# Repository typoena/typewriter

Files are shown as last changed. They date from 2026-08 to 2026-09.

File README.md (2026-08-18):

# Typoena

<p align="center">
  Typo, o tucano
</p>

A distraction-free, hackable, DIY writing machine. ESP32-S3 + e-ink + a real
mechanical keyboard. You write Markdown, you commit, you push. Nothing else
runs on it.

> **Status: firmware 0.8.0, hardware on the bench.** The device boots, edits,
> and syncs: vim navigation and editing, a file palette over multiple buffers,
> Markdown affordances, `/` search, `:gs` push / `:gl` pull, focus mode,
> `:update` OTA, a command palette and font picker, and a zero-computer
> first-boot wizard. v0.9 (robustness) is the open release — per-item status in
> the Macroplan, release contents in the [CHANGELOG](CHANGELOG.md).

Design & context:

- [Macroplan](docs/plan/macroplan.md) — the week-by-week delivery plan, live
  per-item status, and per-version scope
- [QFD](docs/quality/qfd.md) — how every decision is weighted against the
  user-facing requirements (Goal → Function → How → Component)
- [ADRs](docs/adr.md) — the decision log, rejected alternatives included
- [Doc index](docs/README.md) — everything else: per-version specs, notes,
  tradeoff curves
- [Bill of materials](hardware/bom.md) — build it yourself, full part list
- [Wiring](hardware/wiring.md) — every electrical connection, pin by pin
- [Postmortems](docs/record/postmortems/README.md) — failure write-ups
- [Kaizen](docs/record/kaizen/README.md) — improvement loops

Technical pages, one per subsystem:

- [Firmware](firmware/README.md) — build, flash, provisioning, editor setup,
  bring-up spike log
- [Enclosure](hardware/case/README.md) — parametric, 3D-printable
  typewriter-body case (OpenSCAD)
- [Installer](installer/DESIGN.md) — macOS setup tool: flash + provision
  without a dev environment

---

## Vision

A single-purpose appliance that boots into a text editor with a Vim keymap,
edits Markdown files, and (optionally) pushes them to a git remote (GitHub
first) over Wi-Fi. No browser, no notifications, no apps. Open lid → write →
push (or don't) → close lid.

Two file scopes coexist on the SD card — formal definitions in
[`CONTEXT.md`](CONTEXT.md):

- **Tracked** — lives in the git working copy, gets **Pushed** when the
  user runs `:gs`.
- **Local** — never leaves the device. Permanently-private: journal entries,
  scratch, things that aren't anyone else's business. There is no "promote
  to Tracked" gesture — scope is fixed at file creation.

Same editor, same keymap; the difference is just whether `:gs` (push to
the remote) is offered.

---

## Hardware

**ESP32-S3-N16R8** (16 MB flash, 8 MB PSRAM) · **GDEY0579T93** 5.79″ e-ink
strip (792×272, ~2.9:1 — biases the UX toward "current line + recent context",
the writing posture we want) · **Nuphy wired USB keyboard** with the S3 as USB
host · **microSD over SPI** · **USB-C wall power or a 3700 mAh LiPo**, switched
by a latching panel button through a load-sharing power path.

---

## Software stack

**Rust on `esp-idf-rs` (std)**, a custom modal editor and thin widget layer on
`embedded-graphics`, a custom dual-SSD1683 e-ink driver, libgit2 (via `git2`)
for `:gs`/`:gl` sync over mbedTLS. The layer-by-layer table — each choice with
its ADR, measured costs, and the annotated repo layout — is in
[`docs/reference/stack.md`](docs/reference/stack.md).

---

## UX boundaries set by the medium

E-ink is a brutal honesty filter on UI choices. Hard constraints we design
around, not against:

- **No cursor blink.** Kills the panel and the battery.
- **Typing latency target: ≤ 200 ms** from keypress to glyph on screen, using
  partial refresh on the affected line only.
- **Full refresh every ~20 partials** to clear ghosting. User-visible flash —
  schedule it on pauses (>1 s of no input).
- **No smooth scrolling.** Page-style jumps only.
- **No animations.** Anywhere.
- **Render only changed lines**, not the viewport.

---

## Open questions / risks (tracked, not yet resolved)

- [ ] Heap fragmentation over a long writing session with the PSRAM allocator.
- [ ] Real-world e-ink ghosting with the current partial-refresh cadence.
- [~] Use-after-free freeing the in-flight USB transfer on keyboard unplug —
  fixed in code, pending an on-device hot-plug run to confirm.

Retired risks ([gix push](docs/record/postmortems/2026-07-05-spike7-gix-https-push.md),
[SD CMD59 rejection](docs/record/postmortems/2026-07-05-spike3-sd-cmd59.md), TinyUSB HID
stability, TLS heap, libgit2-on-xtensa) and how they died:
[`docs/record/postmortems/`](docs/record/postmortems/README.md) and the
[bring-up spike log](firmware/docs/bring-up-spikes.md).

These get resolved by writing code, not by deciding harder.

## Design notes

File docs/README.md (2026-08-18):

# Docs

> The design record for Typoena. Four trees, split by what you are doing:
> **reference** is what is true right now, **plan** is what is coming,
> **quality** is how requirements are weighed, and **record** is dated and
> append-only.
>
> Start with the [ADRs](adr.md) for the load-bearing choices, or
> [commands](reference/commands.md) for what the device actually answers to.
> Project overview: [`../README.md`](../README.md).

## Decisions

| Doc | What's in it |
| --- | --- |
| [`adr.md`](adr.md) | Architecture Decision Records — the load-bearing technical choices, rejected alternatives included. |
| [`INDEX.toml`](INDEX.toml) | Retrieval index: what each doc concludes, and which subsystem it concludes it about. One read, no folder browsing — for agents and for finding the file that holds a number. |

## Reference — true now, no dates

| Doc | What's in it |
| --- | --- |
| [`reference/commands.md`](reference/commands.md) | Every `:` command and `>` palette action, and what each one refuses to do. |
| [`reference/stack.md`](reference/stack.md) | Software stack layer by layer, with measured costs and the annotated repo layout. |
| [`reference/typoena-toml.md`](reference/typoena-toml.md) | `.typoena.toml` — the git-tracked editor preferences. |
| [`reference/typoena-snippets.md`](reference/typoena-snippets.md) | `.typoena.snippets.json` — the git-tracked, Zed-compatible snippet library. |
| [`reference/testing.md`](reference/testing.md) | Where Rust tests live and how to run them. |
| [`reference/ssd1683-commands.md`](reference/ssd1683-commands.md) | What every command and data byte the e-paper driver writes means. |
| [`reference/hid-keycodes.md`](reference/hid-keycodes.md) | Boot-report layout, modifier bits, and the usage IDs behind the chord table. |
| [`reference/font-atlas.md`](reference/font-atlas.md) | Atlas geometry, glyph slot order, and the framebuffer's ink polarity. |
| [`reference/libgit2-esp-port.md`](reference/libgit2-esp-port.md) | The POSIX shims libgit2 links against on esp-idf. |
| [`../hardware/bom.md`](../hardware/bom.md) | Bill of materials — every physical part by subsystem. |
| [`../hardware/wiring.md`](../hardware/wiring.md) | Every electrical connection, one table per subsystem. |

## Plan — what is coming

| Doc | What's in it |
| --- | --- |
| [`plan/macroplan.md`](plan/macroplan.md) | The delivery plan: macroplan source and the open checklists for v0.9, v0.10, v1.0 and v1.x. |
| [`plan/v0.9-onboarding-wizard.md`](plan/v0.9-onboarding-wizard.md) | First-boot setup and `:setup` — the zero-computer provisioning flow. |
| [`plan/v0.10-battery-and-sleep.md`](plan/v0.10-battery-and-sleep.md) | Power switch, power path, battery, sleep. Design decided, not built. |

Delivered releases are listed in full in [`../CHANGELOG.md`](../CHANGELOG.md).
Their behaviour lives in the reference pages above, not in per-release specs.

## Quality — how requirements are weighed

| Doc | What's in it |
| --- | --- |
| [`quality/qfd.md`](quality/qfd.md) | QFD hub — what-matters-now headlines, §6 the critical performance budget, §7 the tradeoffs and unresolved tensions. Start here. |
| [`quality/glossary.md`](quality/glossary.md) | Methodology vocabulary: the WHAT / Function / Characteristic / Metric / Target ontology. |
| [`quality/qfd-house-1.md`](quality/qfd-house-1.md) | House 1 (WHATs × HOWs) — §1 requirements, §2 characteristics, §3 reading, §4 roof. |
| [`quality/qfd-house-2.md`](quality/qfd-house-2.md) | House 2 (HOWs × components) — §5 cascade tree, component ranking, shared-pool budget. |
| [`quality/qfd-houses-3-4.md`](quality/qfd-houses-3-4.md) | Houses 3 & 4 under the pipeline reading — processes P1–P9 × controls Q1–Q8. |
| [`quality/qfd-perception.md`](quality/qfd-perception.md) | Competitive perception — five products scored 0–5 per WHAT. |
| [`quality/house-vs-product.md`](quality/house-vs-product.md) | Standing challenges: where the scored houses and the real product disagree. |

Device vocabulary (Save, Push, Tracked, Local) is in
[`../CONTEXT.md`](../CONTEXT.md), not here.

## Record — dated, append-only, never pruned

| Area | What's in it |
| --- | --- |
| [`record/postmortems/`](record/postmortems/README.md) | What broke, the root cause, and the decision that came out of it. |
| [`record/kaizen/`](record/kaizen/README.md) | Six-step improvement loops: a recurring cost measured, attacked, re-measured. |
| [`record/tradeoff-curves/`](record/tradeoff-curves/README.md) | Cost-vs-knob curves behind chosen defaults — energy, latency, memory. |
| [`record/notes/`](record/notes/README.md) | Longer-form essays: the arguments too big for an ADR, too durable for a commit message. |
| [`../firmware/docs/bring-up-spikes.md`](../firmware/docs/bring-up-spikes.md) | The chronological bench log of Spikes 1–7 that brought the firmware up on silicon. |

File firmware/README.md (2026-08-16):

# Typoena firmware

Rust crate targeting `xtensa-esp32s3-espidf` — the on-device firmware: a
vim-style modal editor with git push/pull, OTA updates, and a first-boot
wizard.

One crate of the [Typoena project](../README.md) — start there for the
vision, the hardware, and the design record (macroplan, QFD, ADRs, doc
index). The layer-by-layer stack and the annotated repo layout:
[`docs/reference/stack.md`](../docs/reference/stack.md).

Technical pages:

- [Build details](docs/build-details.md) — esp-idf components, libgit2 and
  the `full` feature
- [Editor setup](docs/editor-setup.md) — Zed / rust-analyzer, `esp` toolchain
  version requirement, launch environment
- [Provisioning an SD card](docs/sd-provisioning.md) — `just init` / `load` /
  `provision`, the config ladder, secrets on the card
- [Bench board & pinout](../hardware/wiring.md#the-bench-board) — DevKitC-1 v1.0, pin assignments
- [Bring-up spike log](docs/bring-up-spikes.md) — Spikes 1–6 as verified on
  the bench
- [Bench QC firmware](docs/bench-qc.md) — go/no-go fixture for the
  hand-soldered carrier PCB

## Quick commands

A [`justfile`](https://github.com/casey/just) wraps the common commands and
sources the espup env itself — run `just` in this directory for the list
(`build`, `flash`, `monitor`, `info`, `ports`).

## Build

Once per shell session, source the espup env (sets `LIBCLANG_PATH` and adds
the Xtensa GCC to `PATH`):

```sh
. ~/export-esp.sh
```

Then from this directory:

```sh
just build   # the product firmware: editor + git pushing + OTA + wizard
```

The first build is slow (esp-idf + libgit2 + mbedTLS); after that it's
incremental — see [build details](docs/build-details.md). The fast iteration
loop is host-side: `cargo test -p app -p editor`.

The panel's fast/partial waveform comes from Good Display's vendor reference
driver, kept verbatim in
[`reference/gdey0579t93-fp-lut/`](reference/gdey0579t93-fp-lut/README.md) — it is
the source of truth for the custom `0x32` LUT, which cannot be derived from the
panel's OTP.

## Flash

With the board connected over USB, `just flash` (or `cargo run --release`)
triggers `espflash flash --monitor` via the runner configured in
[`.cargo/config.toml`](.cargo/config.toml).

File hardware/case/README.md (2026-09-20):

# Enclosure — Typoena body

A 3D-printable case for [**Typoena**](../../README.md), the distraction-free DIY
writing machine. The e-paper strip sits on a reclined **deck**, where a
typewriter's paper would be; you bring your own keyboard for the front. There is
no platen part (it complicates the print); the rounded back-top edge nods to one.

> **Status: outer form and screen clamp proven on a print; the cavity
> follows the fabricated mainboard and has not been printed against it.** The
> wedge, the deck and the glass retention are worked out against the real
> hardware and every number there is measured — the **3700 mAh** cell included.
> The board block — mounting, ports, button — is cut straight from
> [`typoena-devboard.kicad_pcb`](../pcb/devboard/typoena-devboard.kicad_pcb), so
> its dimensions are exact and its *fits* are untried: **print the I/O coupon
> first**. Process error is corrected **in the slicer** and not in the model, and
> the correction is qualified per filament, so
> **[MANUFACTURING.md](MANUFACTURING.md)** is required reading before any print.
> The 12 heat-set inserts are untried — see **Open questions**.

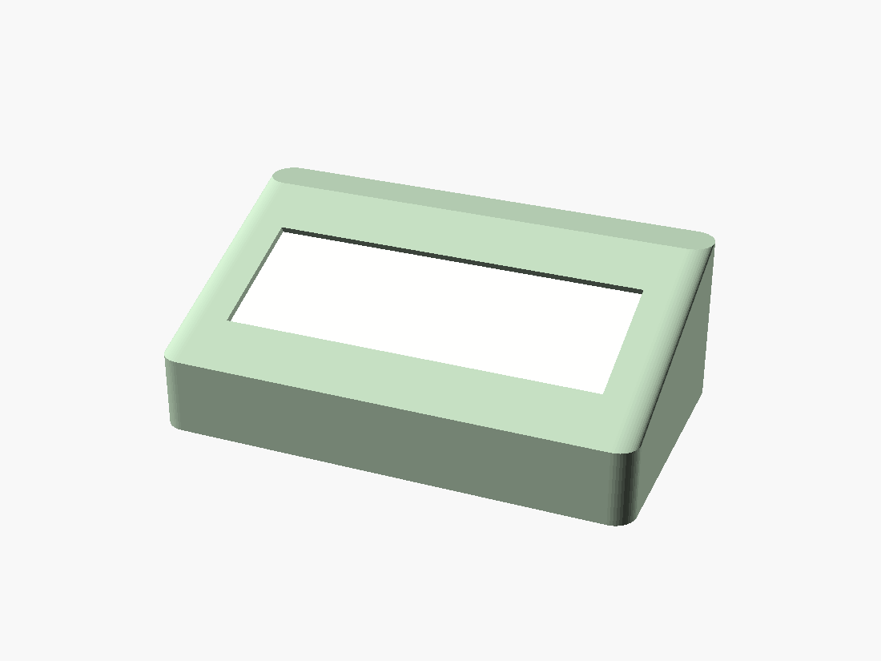
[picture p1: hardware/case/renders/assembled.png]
The deck: bezel lip framing the e-paper aperture

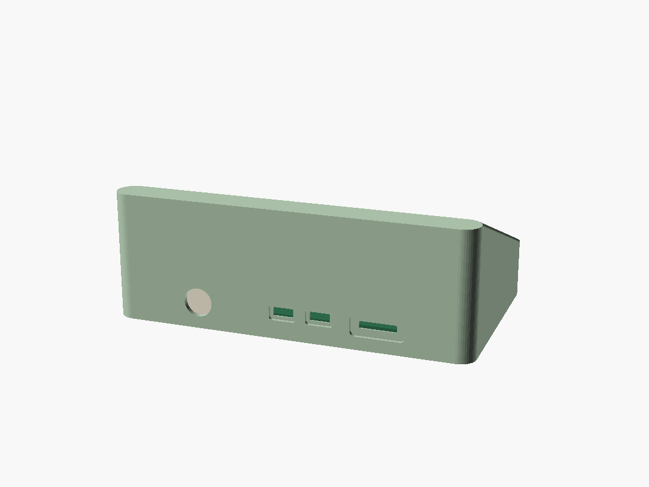
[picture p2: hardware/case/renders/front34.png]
Assembled body, three-quarter — reclined deck, back wall with port cutouts


## Files

| File | What |
| --- | --- |
| [`typoena-case.scad`](typoena-case.scad) | The parametric model, **nominal geometry**. All dimensions live at the top. |
| [`MANUFACTURING.md`](MANUFACTURING.md) | **Slicer settings — read before printing.** Process error is corrected here, not in the model, and the value is qualified per filament. |
| [`typoena-case-kb.scad`](typoena-case-kb.scad) | Integrated-keyboard variant (60%/40%) — see [README-kb.md](README-kb.md). |
| [`concept.html`](concept.html) | The **v0 concept sheet** as drawn, before the model existed. Its platen roller and knobs never shipped; the model wins on every dimension. |
| `renders/` | PNG previews (regenerated by `just render`). |
| `*.stl` | Mesh exports — generated on demand by `just stl`, not tracked. |

## Render

Needs [OpenSCAD](https://openscad.org). From `hardware/`:

```sh
just render   # regenerate every case/renders/*.png
just stl      # export every STL: body / bracket / baseplate / coupon / jig / assembly
just stl-io   # re-export just the back-wall I/O fit coupon (quick test print)
just stl-guide # re-export just the baseplate drill jig block (print it 4x)
just stl-feet # export the stick-on feet (deferred — see feet_mode)
just open     # open the model in OpenSCAD
```

The meshes aren't tracked — they're 5 MB of ASCII that git rewrites line by line
on any geometry change. For a shareable set, tag instead: `git tag case-vX.Y.Z &&
git push origin case-vX.Y.Z` has CI export from the tagged commit and publish
`stl.zip`, `stl-kb.zip` and the I/O coupon to
[Releases](https://github.com/typoena/typewriter/releases).

`show` accepts `assembled` · `body` · `bracket` · `baseplate` · `feet` ·
`print_plate` · `section` (vertical cut) · `plan` (exploded horizontal) ·
`plan_up` / `plan_down` (each half alone) · `io_coupon` (the I/O fit test print) ·
`drill_guide` (one baseplate drill jig block, print four) / `drill_guide_fit`
(the four of them seated on the plate).

## Dimensions

Baked into the model from the datasheets:

- **Panel (GDEY0579T93):** glass 150.92 × 56.94 × 1.0 mm, active area
  139.00 × 47.74 mm, pitch 0.1755 mm.
- **Mainboard** (99 W × 45 D × 1.6 mm, corners R3): the whole machine on one
  PCBA — BQ25896 power path, the panel's power stage, µSD, both USB-C. **Ø3.7
  hole 5 mm in from each corner**, which is a #6-32 clearance. It lies **along
  the back wall**, ports out.

  **Read its X off the canvas and you get it backwards.** KiCad's Y points down,
  so the port edge is drawn at the *bottom*; laying the board in with its ports at
  the **back** turns it 180° in plan. Every board-local X in the model is
  therefore `u = 116 − kicad_x`, from the board's **left edge as installed** — so
  `J4` (KiCad x 110) ends up 2…7 mm from the **left** edge, and the devkit
  (KiCad x 15…78) fills the **right** half.
- **ESP32-S3-DevKitC-1**, plugged into the mainboard's two 1×22 rows over its
  right half (`u` 38…101): **13.5 mm of stack** over the board face (socket 8.5 +
  board 1.6 + can 3.4) and the tallest thing in the cavity. Its antenna end
  overhangs the board's **right** edge by 2.3 mm, which is the widest the
  assembly ever gets.
- **Battery:** LiPo 3700 mAh, 94 × 32 × 10.3 mm, flat in the front-right.
- **Body:** 176 W × 104 D, 28 mm front → 68 mm back, deck reclined ~21°. Walls
  2.4 mm, deck 3.4 mm, corner radius 8 mm.

## How the hardware goes in (glueless)

No glue on the fragile 1 mm glass; every part stays serviceable.

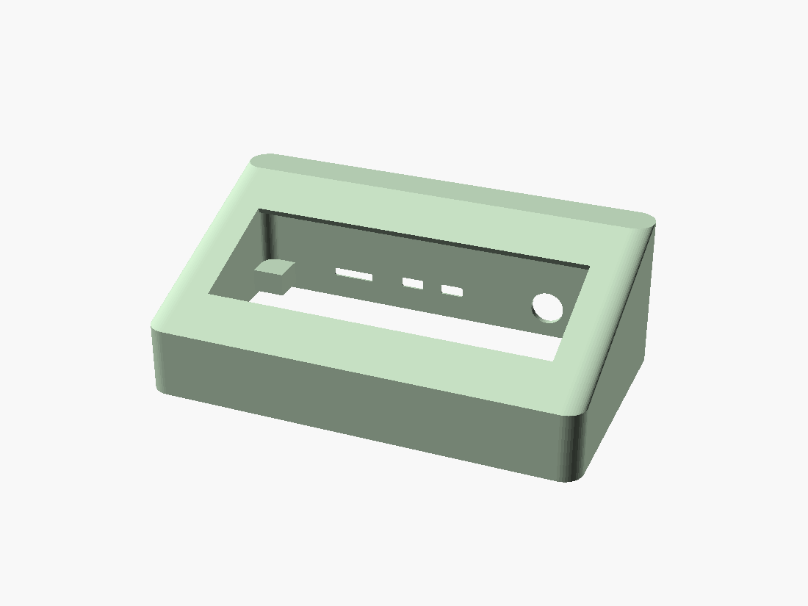
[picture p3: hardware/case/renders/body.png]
Bare body shell — screen recess through the deck, FPC slot on the left edge


**Screen.** The glass drops into the deck recess from behind (the walls locate it
in X/Y). The deck is that recess plus the lip in front of it — `top_wall` is
`lip_t + G_t`, so the pocket wall is **exactly one glass deep**: it takes the glass
over its full 1 mm and stops on its back face, where the foam frame (wider than the
pocket) comes up to meet it. Front to back the stack is: deck **bezel lip** (covers
the inactive border only, `lip_t = 2.4 mm`) → **glass** → non-adhesive closed-cell **foam**
gasket (`foam_t = 5 mm` free, squashed to `foam_c = 3.5` — a 30% squash) → printed
**bracket**
screwed to 4 bosses. The lip stops the glass falling out the front; the bracket
stops it dropping into the cavity. The FPC folds back through an internal
clearance on the **left** (kept under the bezel, so invisible outside) and down
into the cavity on its way to the board. For a screwless build, cantilever clips work but point-load the glass
edge; I'd default to foam + bracket.

The bosses' **free ends are the bracket's seating face** (`br_seat = 6.9 mm` below
the deck's outer face). The screw pulls the bracket onto that shoulder and stops,
so the foam squash — and therefore the clamp on a brittle panel — is set by
geometry rather than by how hard you turn the screwdriver. That is also why the
foam is 5 mm and not 1: the seat has to sit far enough behind the glass to leave
the boss room for a **heat-set insert** (see *Fasteners* below). The bore stops
`pilot_skin = 2.1 mm` short of the deck's outer face, so nothing shows on the side
the user looks at — and that skin, not the thread, is what set `lip_t`.

Locating tolerances: the pocket is the glass's *only* registration — nothing behind
it is narrower than the cavity — and it gives the glass **0.25 mm of play per side**
in X and Y, against a window margin of 1.00 mm (X) / 0.50 mm (Y) over the active area —
so a drifted panel shifts the bezel by a quarter of a millimetre and can never clip
a pixel. Don't try to make the bracket locate anything either way: the pocket
locates, the bracket only clamps. Its clearance holes are **Ø3.9 on a Ø3.5 shank** —
drive the screws through the bracket rather than expecting it to drop over them.

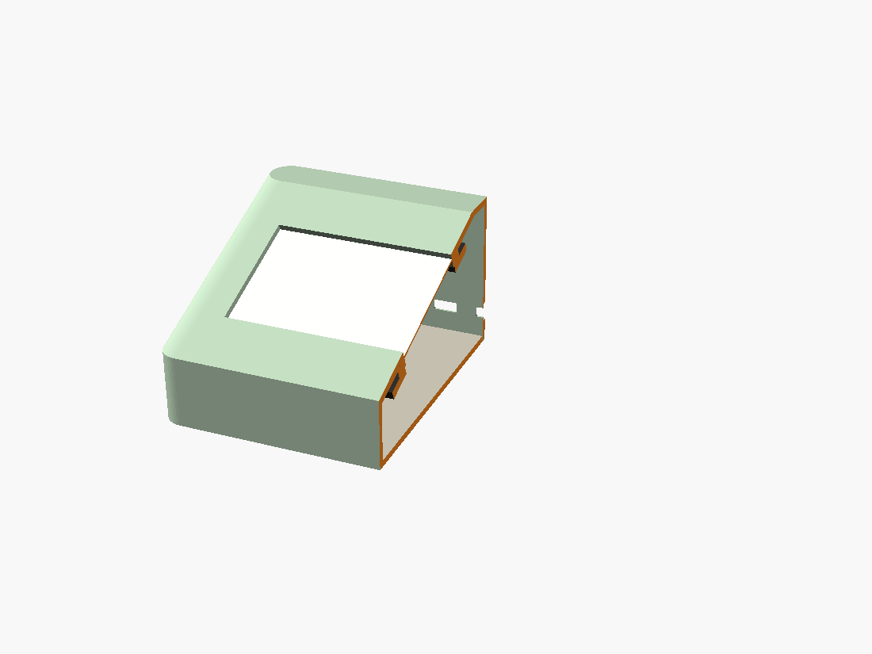
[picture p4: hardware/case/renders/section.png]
Midline section: glass clamped between front lip and rear foam + bracket

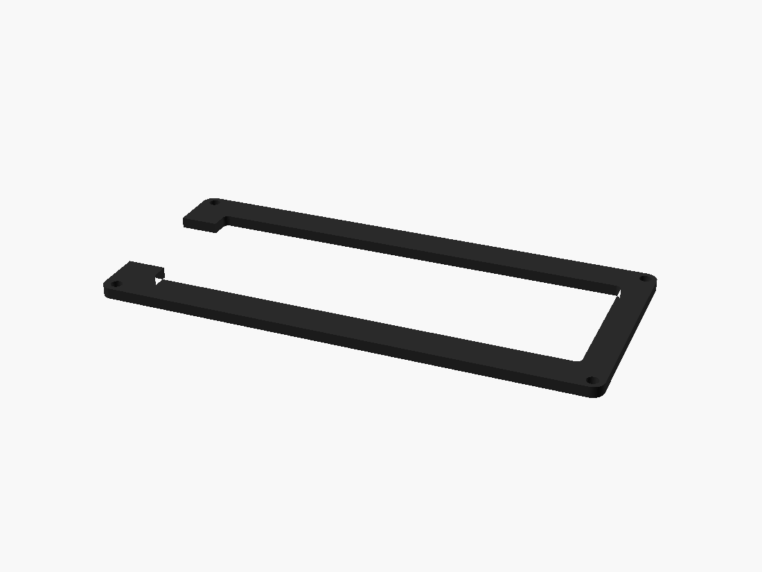
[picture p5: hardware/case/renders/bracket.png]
The bracket — four corner holes, window clears the active area, left edge relieved for the FPC


**Fasteners.** Every screwed joint in the machine uses one family: a
**ruthex RX-6-32×3.8** brass heat-set insert (Ø4.7 body, 3.8 long, datasheet bore
**Ø4.8 × 4.8 min**, **1.8 mm minimum wall**) taking a **#6-32** pan screw — 7 mm
of thread under a flat 1 mm × Ø6.5 head. Both parts are measured, not
catalogue numbers. All three joints get *opened*: the baseplate on every service,
the bracket on every glass swap, the board whenever it comes out — and a
self-tapped thread in PLA is good for a handful of cycles before it's a stripped
hole in a 10-hour print.

| | bracket → deck (×4) | baseplate → body (×4) | board → standoff (×4) |
| --- | --- | --- | --- |
| insert lives in | the body, under the deck | the body, from below | the **baseplate**, from above |
| boss | Ø8.9, **2.05 mm** of wall | rectangular pad, **2.6 mm** to the free faces | Ø8.9 standoff, **2.05 mm** of wall |
| bore | Ø4.8 × 4.8 blind, **2.1 mm of deck** left over it | Ø4.8 × 6.6 blind, 3.4 mm of roof | Ø4.8 × 6.4 blind, bottoming on the plate — **3.2 mm** under it |
| screw crosses | 3.6 mm of bracket | 1.4 mm of plate | 1.6 mm of PCB |
| thread in brass | **3.4 mm** | **3.8 mm** (the whole insert) | **3.8 mm** (the whole insert) |
| head | **no lamage** — bears on the bracket's face, inside the case | in a **lamage** in the plate's underside, flush with the desk — **drilled, not printed** (see [Drilling the baseplate](#drilling-the-baseplate)) | **no lamage** — bears on the PCB, Ø6.5 on a Ø3.7 hole |

Every bore is a **plain Ø4.8 cylinder** — no relief, no step, no lead-in for the
insert's head end: the iron melts its own seat, so the bore is not a clearance fit
and nothing about the insert's outline is modelled. There is no counterbore left
anywhere in the model: the baseplate's four screw passages come out of the printer
**solid** and are drilled afterwards.

That Ø4.8 is what Ruthex asks for around a Ø4.7 body: the insert melts its own
seat, so this is a grip, not a clearance fit. No insert has been set yet — judge
the first one on a part sliced with the XY compensation, since an uncompensated
bore lands ~0.16 mm under and the brass would be pressed into a hole that tight.

Every bore is deliberately **deeper than the insert** (they have to swallow the
screw tip), and with the relief gone **nothing in the part stops the press**. Sink
each insert flush with the boss's free end by eye or with a depth stop on the iron:
that face is a seating face on all three joints — proud brass spends the foam
preload on the bracket, rocks the plate on the baseplate, and tilts the board on
its standoffs.

**Twelve inserts, one screw.** The board is in the family too: its four holes are
a #6-32 clearance, so it screws *down* into an insert in each standoff and the
same **#6-32 × 7** drives every joint in the machine. That is what took the
drill off the baseplate's standoffs — the bore they need is Ø4.8, which a printer
holds, where the Ø1.6 pilot of a self-tapper is two or three perimeters wide and
comes out whatever size the extrusion width allows.

The depth budget is why `lip_t` went 1.4 → 2.4 and `bracket_t` 2.6 → 3.6. Between
the bracket's seat and the deck's *outer face* there is only `br_seat`, and the
bore eats it from below: 6.9 = bore 4.8 + skin 2.1. At the old numbers the bore came
to 5.4 against a `br_seat` of 5.9 — **0.5 mm** of skin on the machine's showpiece
face, with the screw tip arriving under it and the iron melting brass into it.
There is nowhere else to buy that skin, so it came half from the visible lip (a
deeper bezel well) and half from the invisible bracket, and the
glass ends up 1 mm deeper in a stiffer clamp. `typoena-case.scad` **asserts** the
walls, the skin, the roof and the thread engagement — a plausible-looking edit to
any of those four numbers fails the render instead of the print.

**Board.** Mount everything to the **baseplate** on the bench, then close from
below.

The mainboard sits on **four Ø8.9 printed standoffs**, `standoff_h` = **7 mm**
tall, one under each corner hole, and is pulled down onto them by four #6-32 into
their heat-set inserts. The standoff height is set by the insert rather than by
the gap: the bore is 6.4 mm deep from the standoff's free end and bottoms on the
plate, which leaves 3.2 mm of material under it.

That 7 mm gap is the **wiring bay**. The panel's flex crosses it west to east,
and the battery, button and lamp pigtails share it.

- The board lands **back-left**: `x` 18…117, `y` 55.8…100.8, i.e. hard against
  the back wall and as far left as the back-left baseplate boss allows.

  **Y is set by the ports.** The two USB-C shells stand **1.3 mm past the board's
  back edge** and have to end up *inside* the wall opening rather than behind the
  wall, so the board is pushed back until only **0.8 mm** is left between its edge
  and the wall's inner face. That puts the receptacle mouths 0.5 mm into the
  wall's thickness, 0.3 mm behind the floor of the cable-boot pocket — as close
  to full plug engagement as a 2.4 mm wall gets.

  **X is set by the flex.** The panel's ribbon leaves the glass on the **left**
  and drops through the deck slot at `x` 3.8…13.8; `J4`, the 24-pin FFC that takes
  it, is at the board's **left** end — body at `x` 20.1…24.5, ribbon entering its
  mouth at 25.3 heading **west**. The two want to be as close as they can get, and
  what stops the board at `x` = 18 is the back-left baseplate boss, whose free
  face is at 16; the model asserts the 2 mm between them.

  The run: down through the slot into the **front-left plenum**, east across the
  plenum floor, up over the board's front edge (its left quadrant is clear — the
  JST row starts at `u` 36) and back west into `J4` at (25, 75). Because the
  connector opens east, the flex has to overshoot and fold back on itself — a
  plain 180° reverse bend in the vertical plane, no mitres. Call it **~90 mm**
  of flex with the bends, against a panel ribbon of 20.

  The **DevKitC-1** lies over the board's right half, 8.5 mm up on its headers,
  with its antenna end overhanging the board edge. Nothing is put beside that end,
  and its own USB-C — the machine's programming port — points into the cavity:
  taking the baseplate off brings the whole board assembly out with it, which is
  how you reach it.

  Height is slack here, because the stack stands at the tall end of the wedge: it
  tops out at **24.7 mm** off the plate's underside against a ceiling of **43.9**
  over the board's front edge, so it clears by 19 mm. The model asserts 2.5.
- **Ports**, from the left: µSD at `x` 44.2, keyboard USB-C at 72.0, charge
  USB-C at 89.9 — the board's own spacing, carried over from the PCB file, so the
  cluster follows the board and nothing else can move it. Centres sit at
  `z` 11.91 (µSD card) and 12.83 (USB-C).

  The **µSD needs its pocket to be usable.** The socket is a push-pull Molex
  1040310811 whose mouth sits 1.92 mm *behind* the board's edge, and a card
  protrudes only 4 mm from that mouth — less than the wall is thick. However the
  board is placed, the card stops short of the outer face. So the µSD gets a
  **26 × 11 finger pocket** in the outer face, 1.6 mm deep like the USB-C boots,
  and an **18 × 3.5 opening** through its floor: the card ends level with the
  pocket floor (0.5 mm proud), and the 3.5 mm of open slot either side of an
  11 mm card is what a fingernail hooks. That clearance *is* the grip — it is not
  slack, and it is the first thing to judge on the coupon.
- **Power on/off switch** — a latching push button (push-on / push-off) through
  the back wall (`pwr_*`), Ø11.8 barrel, centre at `x` **132.3** (43.7 mm in from
  the right outer face), on the USB-C centreline. It carries **gate signal only**
  (µA) — it drives the soft-power latch that opens the load path, so the machine
  is genuinely off between sessions instead of draining the LiPo, and firmware
  still shuts down cleanly on flip-off; contract in
  [v0.10](../../docs/plan/v0.10-battery-and-sleep.md#power-switch--power-path--decided-2026-07-26).
  It sits clear of the typing path. It is a **loose part wired back to `J2`** on
  the board, with its lamp on `J3`.

  Nothing stands behind it, so its three rules are all clearances and all
  asserted: the Ø14 nut — the widest thing behind the panel, not the barrel —
  keeps 6 mm to the **devkit's** overhanging antenna end (`x` 119.3, which is what
  it has to clear, not the PCB edge at 117), 20.7 mm to the back-right screw boss,
  and 3.2 mm over the baseplate. The back face is planar only to `x` = 168
  (`W - corner_r`), which is the other end of its travel.

  No reset/BOOT button is exposed (S3 auto-download makes both recovery-only);
  like the devkit's own USB-C they're reached by opening the case.

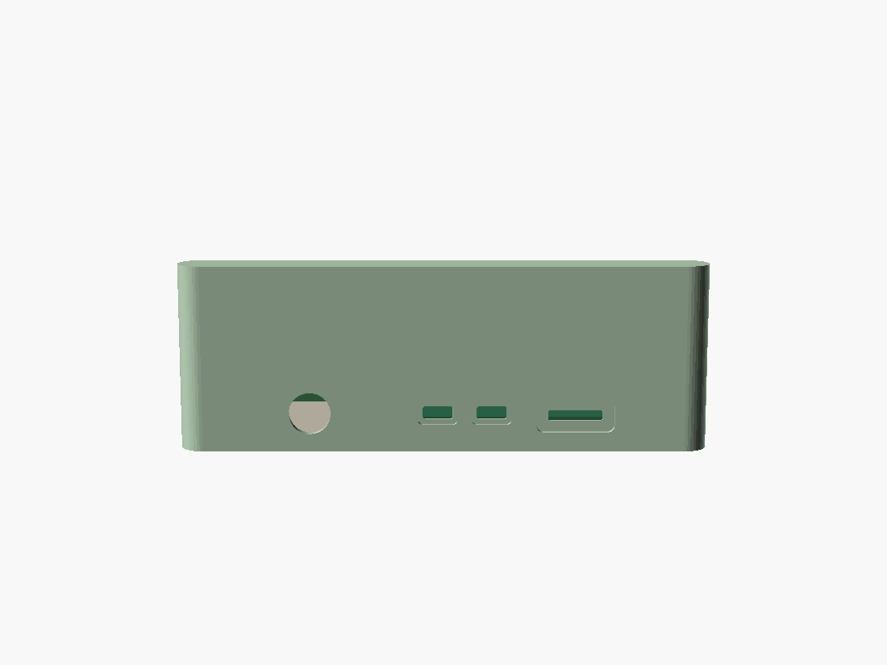
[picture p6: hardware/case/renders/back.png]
Back elevation — µSD, keyboard, charge and the button, all on one line

- **LiPo** flat across the **front** in a baseplate cage (foam/VHB does the
  rest) — the shallow (28 mm) front of the wedge is dead space the board stack
  can't use, and **3700 mAh is the biggest flat cell that fits it**
  (94 × 32 × 10.3); the heaviest part up front also keeps the centre of gravity
  low and forward. Its leads reach `J1` on the board's own front edge, ~25 mm
  away. The latching power switch keeps that capacity from bleeding between
  sessions.

  The cage is **not symmetric**. A **wall** stands at the cell's left end and two
  **nibs** sit at its mid-length: the cell goes in from the right, passes between
  the nibs — which hold it in Y only — and slides left until it stops on the wall.
  The nibs are at mid-length because that is where a pouch cell bows, and it is
  the one spot from which neither end of the cell can lever itself out.

  X is boxed both ways. On the left is the **flex plenum** — the front-left floor
  the panel's ribbon drops into and coils its slack in — and on the right the
  front-right screw boss, which is a rigid printed corner at the cell's own height
  and must never meet a pouch cell:

  | | x |
  | --- | --- |
  | flex plenum, right edge (`plenum_x1`) | 56 |
  | cage wall (`bat_wall_t` = 2) | 56 … 58 |
  | cell (94 long) | **58 … 152** |
  | nibs (`bat_nib_x`) | 105 |
  | front-right screw boss, free face | 160 |

  That is **8 mm** of air ahead of the cell, asserted (`battery: the cell runs
  into the front-right screw boss`) because `bat_x0` is set 300 lines from
  `post_xy` and a plausible edit to either would close it in silence. In Y the
  cell runs 6.4…38.4, and the **17.4 mm corridor** between it and the board's
  front edge is the flex's east-west run — also asserted.
- The baseplate screws up into **four bosses**, one at each corner, all on the
  same 3 mm inset off the corner tangent. Each is a rectangular pad **fused into
  the two walls it sits against** — the box in `post_box` is driven straight
  through the shell and `body_outer()` trims it flush, so the fusion can't drift
  when `wall` or `corner_r` moves. They start at `bp_t` so the plate seats *under*
  them; the 2.6 mm void that leaves is the plate's own volume, and the boss's
  first layer bridges off the wall. They are only `post_h` = **10 mm** tall: the
  walls carry the boss, so height is purely about clearing the Ø4.8 × 6.6 insert
  bore with a roof left on it. Running them to the deck was 67% more plastic
  propping nothing the walls weren't already carrying. The insert goes in from
  **below**, into the boss face the plate seats against — the iron reaches it
  straight down through the open bottom of the shell, so press all four *before*
  any board goes in.

  Each screw keeps **4.9 mm of plate rim** outboard of its Ø6.9 lamage for the
  head to pull against; that rim also absorbs the wander of a lamage that is
  drilled by hand. **No boss may stand under the board** — they run 3 mm past the
  board's underside — which is what the back pair costs: it is the back-left one
  that fixes how far left the board can go.

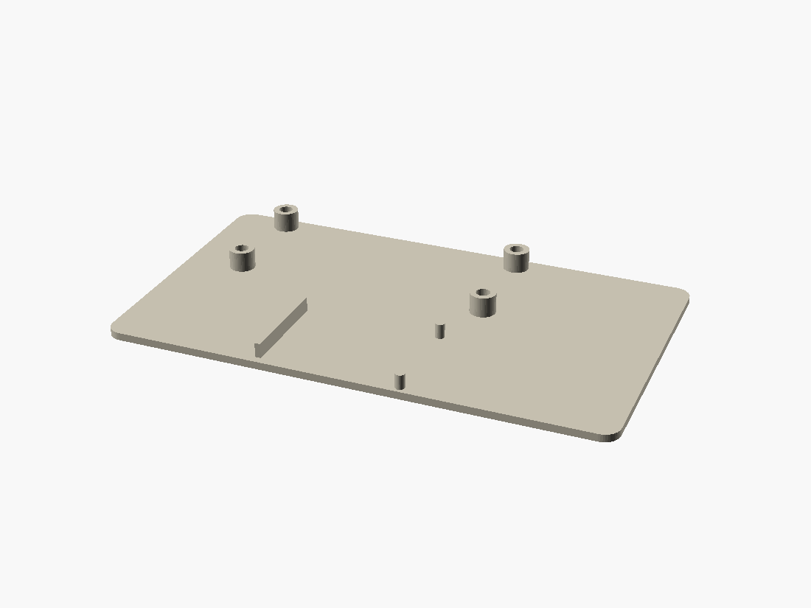
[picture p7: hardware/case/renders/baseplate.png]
The baseplate — the board's four bored standoffs, the battery cage, the screw pads

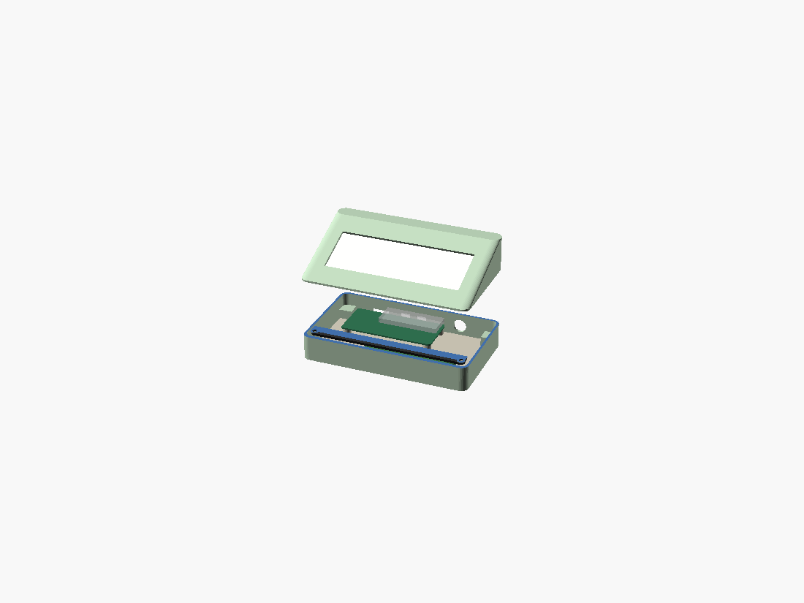
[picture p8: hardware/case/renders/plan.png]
Exploded plan: deck/screen half lifted above the cavity — the board across the back, the battery across the front, screw bosses, ports

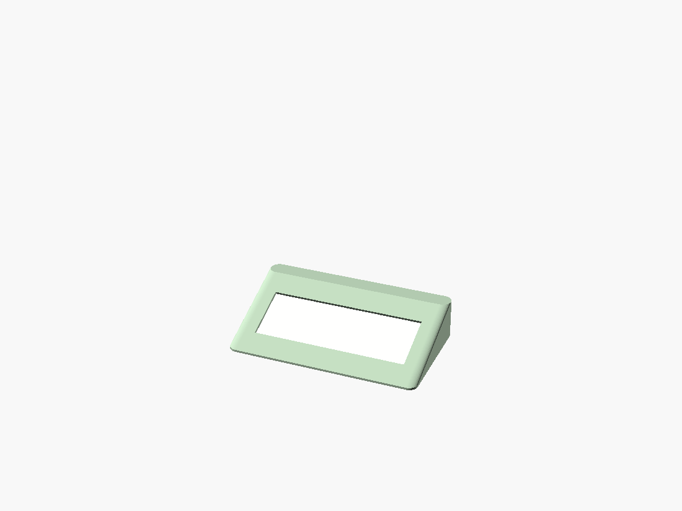
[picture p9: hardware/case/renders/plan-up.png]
Top half (plan_up) — deck underside: the screen in its recess and the bracket bosses

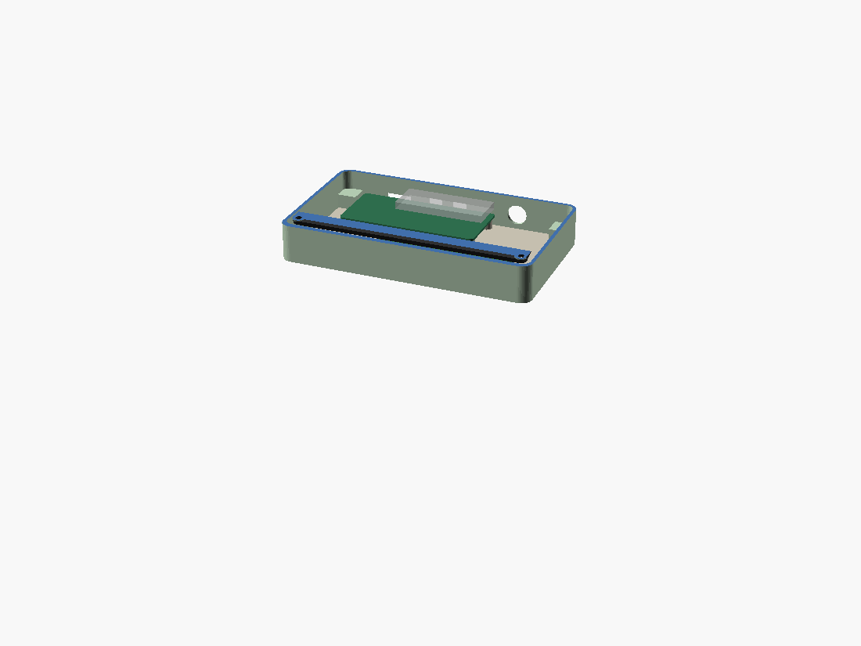
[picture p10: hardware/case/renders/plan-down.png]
Bottom half (plan_down) — the cavity: the mainboard along the back wall with the devkit over its right half, the battery across the front, the flex plenum front-left


**Assembly order.**

0. **Drill the baseplate** — 4 screw passages, the only feature it does not
   print. Print the corner jig (`just stl-guide`) and drill them off it; the
   fallback is marking through the still-empty Ø4.8 boss bores, which only works
   before the inserts go in. See [Drilling the baseplate](#drilling-the-baseplate).
1. **Press the 12 inserts**: on the bare body, 4 into the bracket bosses under the
   deck and 4 into the baseplate bosses (from below); on the baseplate, 4 into the
   standoffs (from above). Iron at ~250 °C, straight in, stop when the brass is
   **flush with the boss's face** — every bore is deeper than the insert, so
   nothing bottoms out for you. The bracket four point at the deck's visible face
   with 2.1 mm of PLA behind them — these are the ones to go slowly on.
2. Lay glass into the deck recess, add foam, screw the bracket to the 4 bosses
   (#6-32 × 7). Drive them until the bracket sits flat on the boss shoulders and
   stop — the shoulder is the stop, not the foam.
3. Screw the mainboard down onto its four standoffs (#6-32 × 7, ports facing the
   back); set the LiPo into its cage — slide it in from the right, past the two
   nibs, until it stops on the wall, and plug it into `J1`.
4. Connect the flex: through the deck slot, east along the wiring bay, up over the
   board's front edge and into `J4`, with the slack coiled in the front-left
   plenum. Run the button and lamp pigtails to `J2` / `J3`.
5. Screw the baseplate up into the four bosses.

### Drilling the baseplate

**The four body screws are the only thing the plate does not print.** Everything
else it carries — the standoffs, their Ø4.8 insert bores, the battery cage — comes
off the bed finished.

The lamage is a flat-bottomed pocket in the plate's *first* layers, so the print has
to bridge from Ø7.4 back in to Ø3.9 over open air, and the seat the head pulls
against ends up being whatever that bridge sagged to. A drill gives a flat seat.

Two features per hole, from the plate's **underside** (the face that meets the
desk):

| | Ø | depth | what it is |
| --- | --- | --- | --- |
| through hole | **3.9** (Ø4 bit) | through 2.6 | #6-32 shank clearance — the screw is turned through it |
| lamage | **6.9** (Ø7 bit) | **1.2**, flat-bottomed | the Ø6.5 × 1 pan head, finishing 0.2 **below** the face |

Flat-bottomed, not a countersink: the head is a flat 1 mm pan and a cone would only
touch it on one rim circle. The head must finish below the underside — with
`feet_mode = "none"` that face is what the machine stands on, and a proud head makes
it rock on three of four points. Drill the lamage **first**, then the through hole
through its centre: a twist bit's point needs full material to centre on.

Positions, from the plate's front-left corner (the long edge is the front; the plate
is 170.7 × 98.7):

| screw | x | y |
| --- | --- | --- |
| front-left | 8.35 | 8.35 |
| front-right | 162.35 | 8.35 |
| back-left | 8.35 | 90.35 |
| back-right | 162.35 | 90.35 |

**A jig rather than a measurement.** `just stl-guide` exports `drill-guide.stl`:
one corner block, of which the plate takes **four** — set the count in the slicer.
The passage sits 8.35 in from *both* edges at every corner, so a block symmetric
about its own diagonal serves all four positions: it is turned, never flipped. Drop it over a corner, where the two edges that meet there locate it
completely, and 6 mm of Ø4 bore holds the bit square over the centre. The plate
goes **underside up** on a sacrificial board: that face is the flat one, the
standoffs stand on the other.

The jig guides the **through hole only**, which inverts the order above — Ø4
first, lamage second, concentric to a hole that is already open. A **step drill**
is the bit for that: its Ø4 step drops into the passage and the Ø7 step cuts the
flat seat on the same axis. A plain Ø7 twist bit has nothing left to centre on and
will chase the hole off.

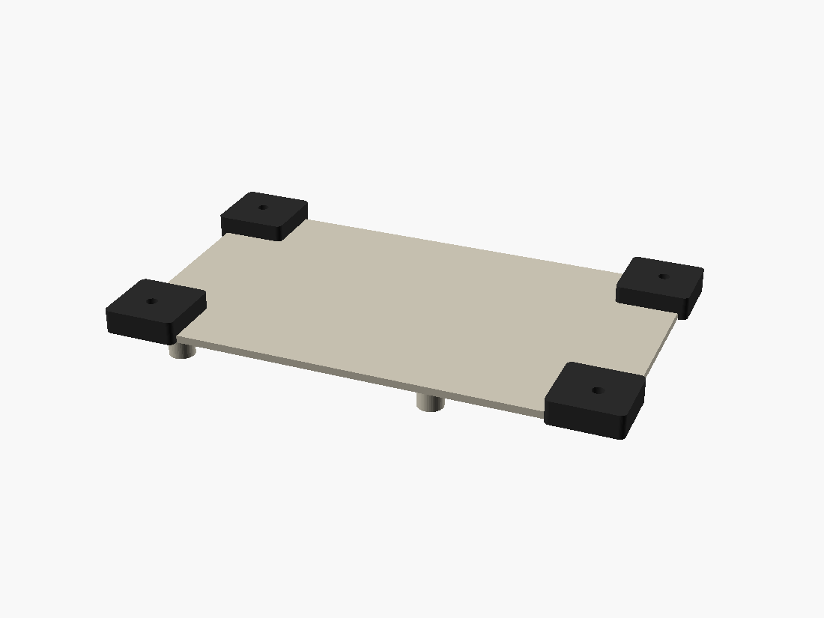
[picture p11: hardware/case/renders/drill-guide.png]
The four corner blocks seated on the plate they drill


Without the jig, **transfer from the body, before the inserts go in.** The
four boss bores are plain Ø4.8 holes at that point, open from below and pointing
straight down at the seated plate — sit the plate in the shell and mark their
centres through them (a Ø4.8 transfer punch, or a pointed marker and then a centre
punch). Press the inserts afterwards; once the brass is in, its ~Ø2.9 thread no
longer lines a bit up on anything. Every screw keeps 4.9 mm of plate rim outboard
of its lamage, which is the wander budget for doing this by hand.

The keyboard variant's bay posts (`bay_posts()` in `typoena-case-kb.scad`) are the
one place a drilled pilot survives: its keyboard PCB takes M2, and **Ø1.6 is two or
three perimeters wide**, so the printer rounds the hole to whatever its extrusion
width allows and the self-tapper arrives at a hole of unknown size. A bit cuts 1.6.

## Tune first

- **`Hb` (back height) → deck angle.** 18–22° is typewriter-shallow; raise toward
  ~28–35° if the screen reads too edge-on when sitting close.
- **Everything else is pinned to a part.** The cell (`bat_*`) and the panel's
  active-area offset (`active_off_x/y`) are measured; the board and port numbers
  (`pcb_*`, `port_*`, `usbc_*`, `sd_*`) are read off the PCB file. Move them only
  against a new part or a new board revision.

## Print notes

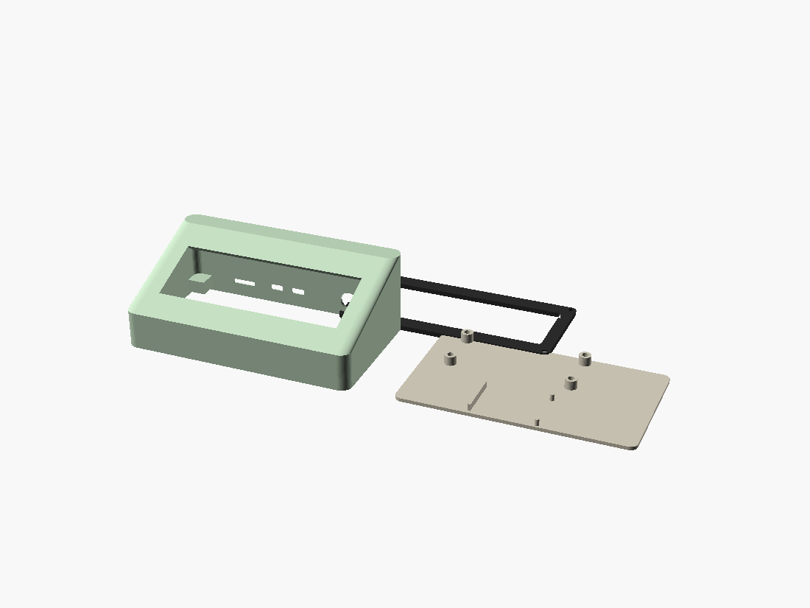
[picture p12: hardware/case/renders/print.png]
The three printed parts — body, bracket, baseplate


- Material PLA/PETG. Body in matte **sage** (`#B6CEB4`), bracket/base in cream or
  brass — the two-tone reads "typewriter" for a filament swap.
- 2.4 mm walls + open bottom keep material low.
- **Print the I/O coupon first.** `just stl-io` exports `io-coupon.stl` — a flat
  slice of the real back wall carrying only the four openings (2× USB-C with their
  cable-boot pockets, the µSD slot in its finger pocket, the power button) at their
  real spacing and wall thickness. Print it face-down (no support, ~45 min), then
  dry-fit it **against the assembled board**: the USB-C shells stand inside their
  openings now, so the coupon checks alignment and not just size. Adjust
  `usbc_*` / `sd_*` / `port_fit` / `pwr_fit` before committing to the body print.
  At 45 minutes a round it is not a guess-and-reprint loop: caliper the parts, then
  size the openings loose so one print clears.

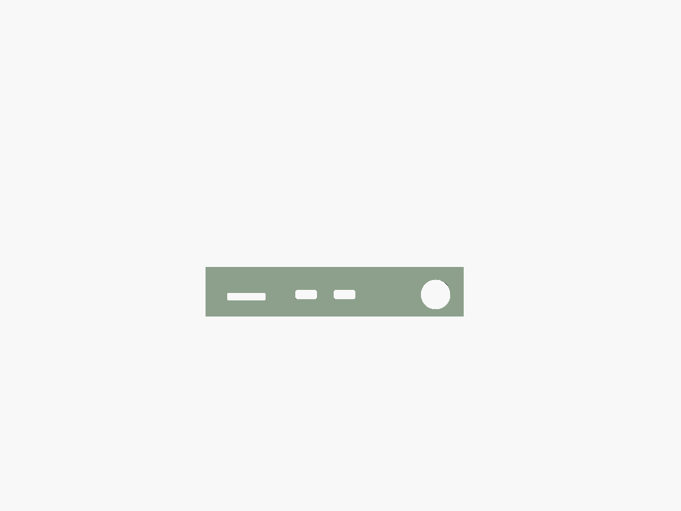
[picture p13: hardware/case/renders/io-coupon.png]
The I/O fit coupon — charge, keyboard, µSD, power button

- Print body deck-up (or on its back) for little/no support; bracket and baseplate
  print flat.
- **The STLs are nominal — the slicer carries any correction.** Process error is
  not in the model, and the XY compensation that removes it is qualified per
  filament: check it against the current spool before committing to a long print,
  and mind the sign. Value and procedure: **[MANUFACTURING.md](MANUFACTURING.md)**.
- **Check the fit that goes tight first:** the baseplate must drop into the shell
  with ~0.25 mm of play a side, no force. Both its mating faces are printed, so it
  loses twice whatever the process loses. Worth repeating on every new filament.
- **The deck ships blank** — `name_on = false`. The engraved `TYPOENA` nameplate
  is still modelled and comes back with that one flag; it sits in the band between
  the front edge and the screen, the only free deck area there is. If it does come
  back it needs `name_font` installed (**Monaspace Krypton**, `brew install --cask
  font-monaspace`, then `fc-cache -f` so the CLI finds it) and something to make
  the recess read: a swipe of paint pen, or a 3–4 layer filament swap across the
  band mid-print.
- **No feet on this version** (`feet_mode = "none"`). They are modelled and can
  come back as their own part with `feet_mode = "separate"` + `just stl-feet` —
  four Ø14 × 3.5 discs, the front pair concentric with the screw bosses and bored
  at the lamage Ø so a **driver** still reaches the recessed head (a shank-sized
  hole would put it out of reach and the plate could never come off). Glue them on
  *after* drilling, and off the drilled holes rather than off the model. What they must *not* go back to
  is `"fused"`: hanging off the plate they leave it resting on four small discs,
  turning the whole baseplate into a 3.5 mm overhang that wants support across its
  footprint, standoffs and nibs floating above it. As it stands all three parts
  print flat-face-down with every feature growing upward off the bed — no support
  anywhere.

## Open questions

Everything settled is in the sections above; the model `assert`s the numbers a
plausible edit could break, so those fail the render rather than the print.

- [ ] **Does the 100 mm extension still reach?** The panel's own ribbon is 20 mm
      and the glass back plane sits ~38 mm off the floor at mid-deck, so the drop
      alone is ~35. `J4` is close — its mouth is at (25, 75), a few centimetres
      from where the flex lands — but it **opens east**, so the flex overshoots
      and folds back on itself, and the round trip puts the run near **90 mm with
      the bends**. That is inside 100 with nothing to spare; a 150 mm part would
      coil the difference in the plenum. Measure it against the real adapter
      before ordering, and check the adapter itself sits in the plenum
      (`plenum_x1` = 56, with the 17.4 mm corridor in front of the board behind
      it).
- [ ] **Extension contrast risk, and it grows with the length.** On these
      COG-on-flex panels the charge-pump capacitors live on the driver board and
      the FPC carries the *generated* high-voltage rails (VGH/VGL/VSH/VSL) back to
      the COG. Added length adds resistance on exactly those rails, and the
      classic symptom is faint or ghosty output rather than an outright failure —
      so it can pass a smoke test and still look wrong. Run a full black/white
      refresh through the extension on the bench and compare against the direct
      connection **before the body print commits the geometry**. Keeping the run
      short is the only defence the case can offer, and `pcb_x0` is where it is
      for that reason.
- [ ] **Can the µSD card be pulled out?** By construction it stops level with the
      floor of its finger pocket (0.5 mm proud), so what does the pulling is the
      3.5 mm of open slot either side of the card. That is the first thing to
      judge on the coupon. If a nail can't hook it, `sd_slot_w` has 8 mm of room
      to grow before it meets the keyboard port's pocket, and `sd_pocket_w` has
      the same.
- [ ] **The USB-C shells stand inside their openings.** The mouths sit 0.5 mm into
      the wall's thickness, which is what buys the plug its engagement — but it
      also means `port_fit` (0.5 mm a side) is the board's **alignment** budget in
      X and Z, not just the plug's clearance. Dry-fit the coupon on the
      real board before the body print; if a shell binds, `port_fit` grows and
      nothing else has to move.
- [ ] **The devkit stack is the one unmeasured number in the cavity.** `pcb_h` =
      13.5 is socket 8.5 + board 1.6 + can 3.4, none of it calipered. It clears
      the deck by 19 mm, so it is not load-bearing — but it is what the ceiling
      assert is checked against, and the board is in hand.
- [ ] **Re-check `pwr_fit = 0.4` on the coupon.** At 0.4 the hole is Ø12.2,
      leaving 0.9 mm a side of bearing against the Ø14 `pwr_body_d` — ample, but
      that bearing is what retains the switch, so it is judged on the coupon and
      not on paper. The switch is deliberately far tighter than the ports: it is
      the one part *retained* by the panel rather than merely passing through it,
      and a coupon whose hole printed Ø14.7 came out wider than `pwr_body_d`,
      with the panel no longer retaining it at all.
- [ ] **The 12 heat-sets are the one irreversible step on a print.** The geometry
      is checked (walls, skin, roof, floor and thread engagement are asserted; the
      screw and insert-body envelopes were booleaned against the solids and come
      back empty — the insert's head end has no relief, it melts its own seat by
      design), but nothing in the model can hold the **iron**. Two live risks:
      - **Over-pressing the bracket four.** The bore is 4.8 deep for a 3.8
        insert and has no stop in it, so there is 1 mm of slack under a flush
        insert and only **2.1 mm of deck** past that — on the face the user
        looks at. Sink to flush and stop; if a first deck dimples or blushes
        there, take `lip_t` up before touching anything else (each +1 is +1 of
        skin; the cost is a deeper bezel well and the same +1 on `top_wall`,
        which an assert holds — the pocket has to stay one glass deep).
      - **The screw length is a tape-measure datum.** Bore depths are budgeted
        at `scr_thread_max = 8` against a measured 7, so a 7.5 mm batch is
        already covered; a 10 mm one is not, and on the bracket it would arrive
        at the deck skin. Caliper one screw before driving 4 into the deck.
- [ ] **Programming means opening the case.** The board's own charge USB-C carries
      no data — the USB-serial bridge is on the devkit — so the port that flashes
      the machine is the devkit's, pointing into the cavity. Four screws take the
      baseplate off and the whole board assembly comes with it, which is the
      intended answer; OTA is the other one.
- [ ] Optional **hinged lid** over the deck (protects the glass in a bag) — not
      yet modelled.
- [ ] Feet — **deferred** (`feet_mode = "none"`). Modelled and ready as a
      separate part. With the heads flush there is nothing forcing them back:
      the plate sits flat on the desk on its own face.

## The panel measurement

Measured borders, glass edge → active area: **9.0 left** (FPC side) · **2.0
right** · **4.0 top** · **4.0 bottom**. From those,
`active_off = (left − right)/2` horizontally and `(top − bottom)/2` vertically,
giving **+3.5 mm horizontal** (toward the right, away from the FPC) and **0
vertical**.

Only the differences are used, so measuring to the visible light window rather
than the true pixel array is fine — the overshoot is symmetric and cancels. The
size itself comes from the datasheet, where it is exact: 792 × 272 px at 0.1755 mm
pitch = **139.00 × 47.74 mm**.

Consequences of the 2 mm right border: the bezel ledge over the glass is
**8.46 mm on the left and 1.46 mm on the right**. That ledge is a step in a solid
deck rather than a free-standing rib, so 1.46 mm prints and holds fine — the
bracket and foam behind carry the clamping load, and the ledge only has to stop
the glass falling forward.

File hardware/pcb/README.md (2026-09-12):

# Typoena — PCBs

Deux projets KiCad 10, même form factor **99 × 45 mm**, 4 couches, et le même
netlist à quelques blocs près.

| Projet | Rôle |
| --- | --- |
| [`devboard/`](devboard/README.md) | carte fabriquée, portant une ESP32-S3-DevKitC-1 sur deux rangées de barrettes. **Figée** — elle décrit le matériel posé sur l'établi |
| [`mainboard/`](mainboard/README.md) | la carte de la machine : module ESP32-S3 soudé, pont USB-série intégré |
| [`common/`](common) | ce que les deux partagent : outillage, symboles maison |

Les valeurs de composants et leur source de datasheet sont communes aux deux
cartes, elles vivent dans [`DESIGN-NOTES.md`](DESIGN-NOTES.md).

## Deux projets, pourquoi deux dossiers

Un projet KiCad, c'est **un** schéma racine et **un** PCB. Les deux cartes ne
peuvent donc pas cohabiter dans un dossier : leurs feuilles hiérarchiques portent
les mêmes noms (`01-power.kicad_sch` … `04-io.kicad_sch`). Chaque carte a son
dossier, et tout le reste remonte dans `common/`.

## Prérequis

Aucun des deux éléments ci-dessous ne vit dans le dépôt : ils s'installent **par
machine**, et les projets ne s'ouvrent pas correctement sans eux.

### KiCad 10

Développé et vérifié avec **KiCad 10.0.5**. Le format de fichier du schéma est
`20250114`, partagé avec KiCad 9, donc un KiCad 9 devrait pouvoir l'ouvrir — mais
la bibliothèque ci-dessous s'installe dans un chemin versionné
(`KICAD10_3RD_PARTY`), donc il faudrait l'y réinstaller séparément.

### Bibliothèque JLCPCB (CDFER)

Elle fournit les symboles et empreintes des composants du catalogue JLCPCB, **avec
les champs `LCSC`, `Part` (MPN), `Class` (Basic/Preferred) et `Stock` déjà
renseignés**. C'est ce qui rend le BOM commandable sans saisir chaque référence à
la main.

Installation par `Outils` → `Gestionnaire de plugins et de contenu` → `Gérer les
dépôts`, ajouter :

```
https://raw.githubusercontent.com/CDFER/cd_fer-kicad-repository/main/repository.json
```

puis installer *JLCPCB KiCad Library* depuis l'onglet `Bibliothèques` (~127 Mo).

| | |
| --- | --- |
| Paquet | `com.github.CDFER.JLCPCB-Kicad-Library` |
| Version installée | **2025.07.18** |
| Licence | MIT — [dépôt](https://github.com/CDFER/JLCPCB-Kicad-Library) |
| Enregistre | `PCM_JLCPCB-*` (18 bibliothèques de symboles) et `PCM_JLCPCB` (empreintes) dans les tables **globales** |

Deux réserves, sans conséquence sur la conception mais bonnes à connaître :

- **Le canal d'installation est en retard sur le dépôt git** — la dernière version
  publiée date de juillet 2025, le dépôt est mis à jour quotidiennement par
  script. Les numéros LCSC et les empreintes ne changent pas ; en revanche les
  champs `Stock`, `Price` et `Class` sont vieux d'un an. Il faut de toute façon
  **revérifier les stocks au moment de commander**, en particulier pour les
  références Extended.
- Le paquet se déclare pour KiCad 8.0. Vérifié ici sous KiCad 10.0.5 : les
  bibliothèques se chargent et se tracent sans erreur.

## `common/` — l'outillage

```
common/
├── netlist.py         les composants que les deux cartes ont à l'identique
├── gen_sch.py         netlist.py + <carte>/board.py -> les 5 fichiers de schéma
├── kisch.py           émission de schéma KiCad 10 (symboles, fils, étiquettes)
├── gen_syms.py        écrit typoena.kicad_sym
├── gen_fab.py         gerbers, perçage, placement et BOM au format JLCPCB
├── check_pcb.py       contrôle qualité du PCB, lecture seule
├── projet.py          chemins d'un projet, résolus depuis son nom
└── typoena.kicad_sym  symboles maison
```

Chaque carte n'a plus qu'un `board.py` : son nom, son UUID racine, et les
composants qu'elle seule porte.

### Bibliothèque de symboles

`common/typoena.kicad_sym` — deux symboles absents des bibliothèques stock,
partagés par les deux cartes. **Aucune empreinte faite main** : tous les
composants utilisent des empreintes stock, relues par l'équipe bibliothèque de
KiCad.

- **BQ25896RTW** — dérivé du `Battery_Management:BQ25895RTW` stock. Les deux
  puces partagent le même WQFN-24-EP 4×4 mais **trois broches diffèrent**
  (2 `PSEL`, 3 `/PG`, 24 `NC` au lieu de `D+`, `D−`, `DSEL`). Le générateur
  contrôle les 25 broches contre la datasheet avant d'écrire, et l'empreinte reste
  celle du symbole d'origine.
- **TPS61023DRL** — dessiné d'après le § *Pin Configuration*, en SOT-563 stock.

Un symbole ne peut se tromper que sur le nom, le numéro et le type électrique de
ses broches — trois choses que l'ERC et la relecture du netlist attrapent. C'est
pourquoi le buck-boost 3V3 a été choisi **parmi les composants dont l'empreinte
existe déjà** (TPS63001 plutôt que TPS63802) : le raisonnement est dans
[`DESIGN-NOTES.md`](DESIGN-NOTES.md).

## Régénérer

```sh
cd hardware/pcb
python3 common/gen_syms.py             # bibliothèque de symboles
python3 common/gen_sch.py mainboard    # schéma : racine + 4 feuilles
kicad-cli sch erc --severity-all -o /tmp/erc.rpt \
  mainboard/typoena-mainboard.kicad_sch
```

`gen_sch.py` réécrit les cinq fichiers de schéma en entier : le relancer après une
retouche dans le GUI **écrase le travail manuel**.

### Le verrou `netlist.lock`

Une carte qui porte un `netlist.lock` est **figée** : `gen_sch.py` vérifie que son
netlist n'a pas bougé, puis s'arrête sans réécrire une seule feuille. Deux raisons
de ne jamais régénérer une carte figée :

- `netlist.py` sert les deux cartes ; une retouche faite pour l'une déplacerait le
  netlist de l'autre en silence. Le verrou la fait échouer ;
- le PCB rattache chaque empreinte à son symbole par un chemin d'UUID, et
  `kisch.uid()` est un uuid4 : une régénération tire de nouveaux UUID et **casse
  tous ces liens**. La mise à jour suivante repose les empreintes et perd le
  placement — c'est le contrôle `H1` de `check_pcb.py` qui surveille ce lien.

Poser le verrou est donc le dernier geste d'une carte terminée, et une carte dont
le PCB existe se verrouille sans attendre qu'elle parte en fabrication :

```sh
python3 common/gen_sch.py mainboard --lock
```

Pour reprendre une carte figée, supprimer son `netlist.lock` — en sachant que les
liens symbole/empreinte du PCB sont alors à refaire.

## Contrôler

```sh
cd hardware/pcb
python3 common/check_pcb.py mainboard                        # pendant le routage
python3 common/check_pcb.py mainboard --profil fabrication   # avant de commander
python3 common/check_pcb.py mainboard -v                     # tous les détails
```

**Lecture seule** : l'outil ne peut pas écrire dans le dépôt. Il rend `PASS` /
`WARN` / `FAIL` par contrôle et sort en erreur s'il reste un `FAIL`.

Il commence par **s'autotester** : la transformation empreinte → pastille est
validée contre la carte (coïncidences piste/pastille, orientation des boîtiers
deux bornes). Si elle ne tient pas, le script s'arrête au lieu de produire des
distances fausses.

Ce qu'il couvre, au-delà de l'ERC et du DRC :

| | |
| --- | --- |
| **A7** | remplissage périmé — un recouvrement zone/piste à 0,000 mm signifie qu'il faut remplir avant de lire quoi que ce soit |
| **B, C** | aucune piste sur In1.Cu, plans d'un seul tenant, **aucune via sur un nœud de commutation** |
| **D** | boucles chaudes et découplage : condensateur → broche, pastille GND → via, et la topologie en té |
| **E, F** | trou de via hors des pastilles CMS ; plafonds d'échappée par boîtier à pas fin, et couverture de la règle `.kicad_dru` |
| **G** | cols trop longs, capacité en courant des rails |
| **H** | lien schéma↔PCB, pastilles sans net — deux défauts qu'aucun outil KiCad ne signale |
| **I, J** | perçages sous le procédé, bandeau de vernis, signaux haute impédance |

Les seuils et leur justification vivent dans le script, au-dessus du contrôle
concerné. Les **budgets de courant sont des hypothèses** à corriger après mesure
au banc.

## Fabriquer

```sh
cd hardware/pcb
python3 common/gen_fab.py mainboard
```

Réexporte la BOM du dépôt depuis le schéma, puis écrit gerbers, perçage,
placement et BOM JLCPCB dans `<carte>/fab/`, qui est ignoré par git.

## Assemblage

Communs aux deux cartes, et portés par le tronc commun :

- **Non montés** — les trois JST-PH du bord (`J1` batterie, `J2` contact bouton,
  `J3` LED), le JST-PH clavier `J13` et le bouton QON `SW1`. Ils se posent à la
  main, donc ils sortent du BOM et du CPL. Chaque carte y ajoute ses headers
  traversants 2,54 mm, que JLCPCB n'assemble pas de toute façon.
- **`R1`, `R10`, `R11`, `R26`, `R27` en 0603** et non en 0402, comme tous les
  autres passifs : ce sont celles qui se reprennent au fer pendant la mise au
  point.
- **`D1`** porte `C19077497` — deux références JLCPCB existent pour le même
  SMF5.0A, c'est celle qu'on a trouvée en stock.

## Classes de nets

Communes aux deux cartes — même `.kicad_dru`, mêmes classes dans le `.kicad_pro`.

| Classe | Piste | Via | Nets |
| --- | --- | --- | --- |
| `Default` | 0,25 mm | 0,6 / 0,3 | tout le reste |
| `Power` | 0,6 mm | 0,8 / 0,4 | VBAT, VSYS, VBUS, PMID, +3V3, +5V, +3V3_SD, REGN |
| `Ground` | 0,6 mm | 0,8 / 0,4 | GND — le seul net de masse du schéma |
| `Switching` | 0,6 mm | 0,8 / 0,4 | les nœuds de commutation des trois convertisseurs et de la pompe de charge du panneau |
| `USB` | 0,25 mm | — | les deux paires D+/D−, en paire différentielle 0,25 / 0,2 |

La classe `Switching` existe pour être **visible en couleur** au routage : ce sont
les nets où la boucle doit être la plus courte possible, et ils ne se rattrapent
pas une fois la carte partie en fabrication.

## Construire sans interface

`kicad-cli` 10 est sur le `PATH` du poste de bureau. Le conteneur exécute KiCad
depuis une AppImage extraite, qui demande son propre environnement :

```sh
K=~/.local/share/com.jean.desktop/tools/kicad9
bash -c "source $K/kicad-env.sh && \$KICAD_CLI sch erc -o /tmp/erc.rpt --severity-all \
  hardware/pcb/mainboard/typoena-mainboard.kicad_sch"
```

Ne pas `source` cet environnement dans un shell qui sert à autre chose — son
`LD_LIBRARY_PATH` casse le `curl` du système.

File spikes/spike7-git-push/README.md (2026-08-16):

# Spike 7 — git push (desktop half)

> Bring-up spike 7, the desktop half of the
> [spike log](../../firmware/docs/bring-up-spikes.md).
> Decision context: [ADR-004](../../docs/adr.md#adr-004-git-implementation--gitoxide-gix)
> (git impl) and [ADR-005](../../docs/adr.md#adr-005-auth--https--github-personal-access-token)
> (auth). Full write-up:
> [`../../docs/postmortems/2026-07-05-spike7-gix-https-push.md`](../../docs/record/postmortems/2026-07-05-spike7-gix-https-push.md).

Spike 7 proves the `add → commit → push` sequence the on-device `git` module
will run. Per the technical doc it's **desktop-Rust first, then on device** —
this crate is the desktop half. It is a **host** program (plain `stable`
toolchain), deliberately kept out of the xtensa-pinned `firmware/` crate.

## Headline finding: the ADR-004 kill-switch fired

Spike 7 is the documented kill-switch for [ADR-004](../../docs/adr.md): _"if
[gix smart-HTTP push] fails on the device, we fall back to `libgit2-sys`."_
It fires at the **library level**, before any device work: gitoxide's own
crate-status doc states `gix` supports push only over `file://` and `ssh://` —
**push over HTTP(S) is not implemented** (only clone/fetch are). Since
[ADR-005](../../docs/adr.md) fixes auth as HTTPS + PAT, `gix` cannot satisfy the
push path today. So this spike uses the fallback the risk table names:
`libgit2` via the [`git2`](https://docs.rs/git2) crate.

## What it does

Mirrors the v0.1 `git` module contract:

1. open the working copy
2. stage with `git add --all` semantics (**deletions propagate** — needed for
   v0.5 file-delete)
3. short-circuit when nothing is staged → "nothing to push"
4. commit; author from config, message = an ISO-8601 timestamp (the time _is_
   the message)
5. push `HEAD` to `origin/<branch>` over HTTPS, PAT in the credential callback
   (**never logged**)
6. on push rejection (remote moved): fetch + `pull --no-edit` (fast-forward or a
   clean merge), then retry the push once; merge conflicts are fatal (surfaced,
   never auto-resolved)

## Verified (2026-07-05)

Run live against a local `file://` bare remote (no credentials):

- **first commit + push** from an unborn `HEAD` → lands in origin ✅
- **nothing to push** short-circuits when the index matches `HEAD` ✅
- **divergence**: a second clone advances origin → push rejected → `pull
--no-edit` merges cleanly → retry push succeeds, origin gets a two-parent
  merge commit ✅

- **real HTTPS + PAT push to github.com** — confirmed 2026-07-05 against
  `jcalixte/typoena-test`: `committed → push accepted by remote`, the commit
  landed on GitHub. The `git2` build links `openssl-sys` for the TLS transport.

Still not exercised: a **non-fast-forward rejection over HTTPS** (the
`push_update_reference` callback path) — the local `file://` transport surfaced
rejection as a `push()` error instead, and the GitHub push above was a clean
fast-forward. The callback path is coded for but unproven live.

## Not proven here (the next gate)

The risk moved _with_ the kill-switch: **can `libgit2` cross-compile to
`xtensa-esp32s3-espidf` against esp-idf's mbedtls?** — the exact C cross-compile
pain gix was chosen to avoid. That is the next on-device spike, and it also
needs PSRAM (`CONFIG_SPIRAM`) enabled and a working SD card (Spike 3) for the
`/sd/repo` working copy. This desktop pass de-risks the API + git mechanics
only.

## Run

Local remote — proves the mechanics, no secrets:

```sh
mkdir -p /tmp/s7 && cd /tmp/s7
git init -q --bare origin.git && git clone -q origin.git work
echo hi > work/notes.md
cargo run --manifest-path <this-crate>/Cargo.toml -- "$PWD/work"
```

Real GitHub repo — proves HTTPS + PAT (use a throwaway repo + a `repo`-scoped
fine-grained PAT):

```sh
cp .env.example .env    # fill TW_GH_USER / TW_PAT / TW_REPO_PATH
set -a; . ./.env; set +a
cargo run -- "$TW_REPO_PATH"
```

`TW_REPO_PATH` must be a clone whose `origin` is the HTTPS URL (or set
`TW_REMOTE_URL` to point `origin` there). The PAT is passed to libgit2's
credential callback and never printed.

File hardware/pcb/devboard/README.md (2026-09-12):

# Typoena devboard — carte de mise au point

Elle porte toute l'électronique de la machine **sauf le MCU** : à sa place, deux
rangées de barrettes qui reçoivent une ESP32-S3-DevKitC-1. C'est la carte
fabriquée, celle qui est sur l'établi.

| | |
| --- | --- |
| Schéma | hiérarchique, 4 feuilles — 86 composants, ERC 0 violation |
| Nets | 62 |
| BOM | 40 lignes, 37 référencées LCSC |
| PCB | routé — 99 × 45 mm, 4 couches, 85 empreintes, 569 segments, 80 vias, 4 zones remplies, 0 connexion restante |
| Contrôle | `check_pcb.py devboard` : 26 PASS · 5 WARN · 0 FAIL |
| Valeurs et leur source | [`../DESIGN-NOTES.md`](../DESIGN-NOTES.md) |

```
typoena-devboard.kicad_sch    racine : les quatre feuilles
├── 01-power.kicad_sch     47 composants   chargeur, rails 3V3 et 5V, rail uSD, bouton
├── 02-mcu.kicad_sch        5              rangées DevKitC, découplage 3V3
├── 03-display.kicad_sch   21              étage de puissance du panneau, FPC, secours
└── 04-io.kicad_sch        13              USB-C ×2, clavier interne, microSD
```

## Figée

`netlist.lock` verrouille son netlist, et `gen_sch.py devboard` s'arrête après
l'avoir vérifié sans réécrire une feuille. Le verrou décrit exactement la carte
fabriquée — référence, symbole, valeur, empreinte, LCSC, MPN, non-monté — pas ce
que le générateur croit. Les deux ont divergé : la carte a été finie dans le GUI,
et `board.py` porte maintenant l'écart dans `REMPLACEMENTS` et `DNP`. Le mécanisme
est décrit dans [`../README.md`](../README.md#le-verrou-netlistlock).

## Ce qu'elle a et que la mainboard n'a pas

- **`J11` / `J12`** — deux rangées 1×22 au pas de 2,54 mm, 22,86 mm entre rangées,
  pour une ESP32-S3-DevKitC-1. Chaque signal garde la GPIO qu'il a sur la
  mainboard : le firmware est le même sur les deux cartes.
- **`J5`** — header 8 points vers une DESPI-C579, secours si l'étage écran intégré
  ne démarre pas. Il a servi : l'étage intégré est validé, et la mainboard part
  sans lui.
- **`J6` sans paires de données** — le pont USB-série est sur la carte de
  développement, le port USB-C n'est donc ici qu'un port de charge. Les 5k1 de CC
  restent : ce sont elles qui déclarent la carte comme consommateur.

Elle n'a **pas** de points de test sur ses GPIO libres : ils sont nés sur la
mainboard.

### Assemblage

En plus des non-montés communs aux deux cartes, JLCPCB n'assemble pas ses trois
headers traversants 2,54 mm : `J5`, `J11` et `J12`.

## Régénérer, contrôler, fabriquer

Tout l'outillage est dans [`../common/`](../common) et les commandes dans
[`../README.md`](../README.md).

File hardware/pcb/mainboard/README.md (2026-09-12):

# Typoena mainboard — carte unique PCBA

Une seule carte porte toute l'électronique de la machine : chargeur et power path,
ESP32-S3 soudé, étage de puissance du panneau, µSD, pont USB-série et les deux
ports USB-C.

| | |
| --- | --- |
| Schéma | hiérarchique, 4 feuilles — 106 composants, ERC 0 violation |
| Nets | 79 |
| BOM | 53 lignes, 41 référencées LCSC |
| PCB | 99 × 45 mm, 4 couches — **en cours de routage**, voir plus bas |
| Contrôle | `check_pcb.py mainboard` : 26 PASS · 4 WARN · 0 FAIL |
| Valeurs et leur source | [`../DESIGN-NOTES.md`](../DESIGN-NOTES.md) |

```
typoena-mainboard.kicad_sch   racine : les quatre feuilles
├── 01-power.kicad_sch     47 composants   chargeur, rails 3V3 et 5V, rail uSD, bouton
├── 02-mcu.kicad_sch        9              ESP32-S3-WROOM-1, strapping, découplage
├── 03-display.kicad_sch   20              étage de puissance du panneau, FPC
└── 04-io.kicad_sch        32              USB-C ×2, clavier interne, microSD, CH343P, points de test
```

## Forme de la carte

**99 × 45 mm, coins R3, quatre fixations Ø3,7 mm à 5 mm des coins** — la géométrie
de la [devboard](../devboard/README.md), reprise telle quelle, ports compris. Le
boîtier est construit dessus : `case/typoena-case.scad` pose `pcb_w = 99`,
`pcb_d = 45`, `pcb_r = 3` et ses quatre inserts aux mêmes coordonnées. Une
seule forme à tenir pour les deux cartes, un seul boîtier à imprimer.

| Décision | Raison |
| --- | --- |
| Format allongé | épouse une machine de 176 mm de large et laisse un rectangle propre pour la batterie de 94 × 32 mm. JLCPCB facturant la surface et non la forme, les ~4 400 mm² se paient au même prix sous n'importe quel format de surface égale |
| Module **en débord de bord** | son keepout fait 48 × 41 mm contre 18 × 25,5 mm pour le corps : le faire déborder sort l'essentiel de cette zone stérile de la carte, et c'est la configuration que préfère la datasheet |
| Les 3 ports groupés sur **un bord long** | une seule paroi à percer, et c'est la disposition qui éloigne le plus les convertisseurs à découpage de l'antenne |
| L'écran **n'impose rien** | on conserve le coupleur FFC et la rallonge 100 mm, donc `J4` se place où le routage l'arrange |

Le plancher en largeur est **~35 mm** : le socket µSD est profond de 15,4 mm depuis
le bord et le module large de 18 mm. En dessous il n'y a plus de canal pour router
derrière les connecteurs.

À nos vitesses (SPI 20 MHz, USB full-speed, I²C 400 kHz), l'allongement ne coûte
rien électriquement. Les vrais coûts sont un plan de masse plus étroit — compensé
par la couche dédiée — et une carte qui fléchit, d'où les fixations aux **quatre
coins**.

> :warning: **Commander un deuxième coupleur FFC.** Puisqu'on garde la rallonge, le
> coupleur 24↔24 reste dans le montage — et `hardware/bom.md:50` le note acheté à
> **un seul exemplaire, sans rechange**. C'est la seule pièce non redondée de la
> chaîne.

## Ce qu'elle a et que la devboard n'a pas

- **`U1`** — ESP32-S3-WROOM-1-N16R8 soudé, à la place des rangées DevKitC, avec son
  strapping (`R18`/`C14` sur EN, `R19` sur IO0) et ses boutons `SW2` RESET /
  `SW3` BOOT.
- **`U5`** — CH343P, pont USB-série, sur les paires de données de `J6` : l'USB-C de
  charge est aussi le port de programmation. L'USB natif de l'ESP32-S3 reste câblé
  côté hôte clavier (`J7` / `J13`).
- **`Q5` / `Q6`** — auto-reset croisé façon DevKitC : chaque transistor a sa source
  sur l'**autre** signal, si bien que EN et IO0 ne sont tirés bas que lorsque DTR
  et RTS diffèrent. Les deux asserter ensemble — ce que fait un terminal à
  l'ouverture du port — ne redémarre pas la carte.
- **`J9`** — header UART 6 points, non monté.
- **11 points de test** traversants sur les GPIO libres, voir plus bas.

Elle n'a **pas** le header de secours écran `J5` : la réimplémentation de l'étage
intégré est validée au banc.

## PCB — en cours de routage

Le PCB descend de celui de la devboard : contour, empilage, fixations et position
des trois ports en viennent tels quels.

| | |
| --- | --- |
| Posé | 94 empreintes, 768 segments, 124 vias, 4 zones |
| Plans | GND, PWR_3V3 et PWR_5V d'un seul tenant · **aucune via sur un nœud de commutation** |
| Cuivre en l'air | **0** |
| Connexions restantes | **2** |

L'import se fait par **`Outils` → `Mettre à jour le PCB depuis le schéma`** : KiCad
garantit les nets, les écrire à la main serait strictement plus risqué pour un
résultat identique.

> Le schéma porte son `netlist.lock`. Ne pas le régénérer : les empreintes sont
> rattachées à leurs symboles par un chemin d'UUID, et `gen_sch.py` en tirerait de
> nouveaux. Voir [`../README.md`](../README.md#le-verrou-netlistlock).

### Ce qu'il reste à poser

1. **Déplacer `TP10`** — sa pastille traversante tombe sur `KBD_5V_EN` et
   `SD_PWR_EN`, qui passent dessous sur B.Cu : 4 courts-circuits et 4 ponts de
   vernis. Un trou traversant perce toutes les couches, il ne peut pas se poser
   sur une zone routée
2. Basculer le champ `Value` des points de test sur **F.Silkscreen** (voir plus bas)
3. Les **2 dernières connexions**
4. Remplissage des plans

## Architecture

```
USB-C charge ──VBUS──┬─► BQ25896 ──BAT──► [JST-PH] LiPo 3700 mAh
   (2× 5k1 Rd sur CC)│      │  L 1µH
                     │      └──SYS──┬──► TPS63001 ──► 3V3  (MCU, EPD, µSD, CH343P)
                     └─► CH343P     │
                        (D+/D−)     └──► TPS61023 ──► 5V ──► VBUS clavier
                                          EN ← IO41           (USB-C, 2× 56k Rp sur CC)
3V3 ──► AO3401A ──► 3V3_SD ──► µSD
        EN ← IO40
3V3 ──► L 47µH + Si1308EDL + 3× MBR0530 ──► PREVGH / PREVGL ──► FPC 24p ──► panneau
```

Le 3V3 sort du buck-boost à **~90 %** de rendement. Le BQ25896 intègre tout le
power path — sélection source/batterie, limitation d'entrée, BATFET — donc aucun
MOSFET ni diode discrète sur le chemin de puissance principal.

## Plan de broches

| Signal | GPIO | | Signal | GPIO |
| --- | --- | --- | --- | --- |
| EPD BUSY / RST / DC / CS | 4 / 5 / 6 / 7 | | `I2C_SDA` / `I2C_SCL` | **17 / 18** |
| EPD MOSI / SCK | 11 / 12 | | `PMIC_INT` | **16** |
| SD CS / MISO / SCK / MOSI | 10 / 13 / 14 / 15 | | `PWR_SENSE` (contact bouton) | **21** |
| USB D− / D+ (clavier) | 19 / 20 | | `SD_PWR_EN` | **40** |
| UART0 RX / TX | 44 / 43 | | `KBD_5V_EN` | **41** |
| BOOT | 0 | | `BTN_LED` | **38** |

**`PWR_SENSE` doit rester dans GPIO 0–21.** Sur ESP32-S3, seuls les RTC GPIO
réveillent d'un deep sleep (`ext0` / `ext1`) — et le « off » de cette machine *est*
un deep sleep. Même contrainte pour le reed switch de couvercle, à qui **IO2 est
réservé** (laissé non connecté ici, aucun connecteur n'est prévu à ce stade).

### Points de test

Les GPIO restants ne sortent pas sur une barrette : chacun a son **trou traversant
non monté**, posé où le routage l'arrange. L'empreinte `TestPoint_THTPad_*` se
retire d'elle-même du BOM et du CPL — ni ligne de BOM, ni pose.

**Deux tailles, selon l'usage.**

| | net | empreinte | perçage | pourquoi |
| --- | --- | --- | --- | --- |
| `TP1` | `GND` | Ø2,0 | **Ø1,0** | le retour, sans lequel un point de test de signal ne sert ni à sonder ni à alimenter |
| `TP3` | `+3V3` | Ø2,0 | **Ø1,0** | de quoi alimenter ce qu'on soude |
| `TP4`, `TP5` | `I2C_SDA`, `I2C_SCL` | Ø2,0 | **Ø1,0** | un périphérique I²C se câble sans rien redécider : le bus existe déjà pour le BQ25896, un composant de plus coûte **zéro broche** |
| `TP6`–`TP9` | `IO1`, `IO2`, `IO8`, `IO9` | Ø1,5 | Ø0,7 | les seules **ADC1** disponibles, et les seules capables de **réveiller d'un deep sleep** |
| `TP10`, `TP12`, `TP13` | `IO39`, `IO47`, `IO48` | Ø1,5 | Ø0,7 | numériques ordinaires |

Le Ø1,0 des cinq premiers n'est pas du confort : une broche carrée de 0,64 mm a
**0,9 mm de diagonale**, donc c'est le plus petit perçage qui laisse encore souder
une barrette et y mettre un cavalier. C'est là qu'on branche quelque chose
d'alimenté, et c'est la seule raison de dépenser la place.

Les huit GPIO ne recevront qu'un fil soudé une fois : Ø0,7 passe du 24 AWG à
l'aise et divise l'encombrement par deux.

> **Chaque `TP` doit porter son nom de net sur la sérigraphie.** Son champ `Value`
> l'a déjà ; il reste à le basculer de F.Fab vers F.Silkscreen dans pcbnew
> (`Édition` → `Modifier les propriétés des textes et graphiques`, filtré sur
> `TP*`). Sur une barrette, la position encode l'identité ; un trou isolé sans
> marquage ne dit rien, et ces treize-là sont alors inutilisables.

`IO1`, `IO8` et `IO9` sont les trois ADC1 libres — l'ADC2 est désactivé par le
Wi-Fi, et le reste de l'ADC1 est pris par l'écran et la µSD. `IO2` est RTC comme
eux, et c'est lui qui accueillera le **reed switch de couvercle** le jour venu.

> **`IO3`, `IO45` et `IO46` ne sont délibérément pas sortis.** Ce sont des broches
> de strapping : quelque chose qui les charge au démarrage empêche la carte de
> booter. Les rendre accessibles serait une invitation à un mode de panne difficile
> à diagnostiquer. `IO35`, `IO36` et `IO37` sont pris par la PSRAM octale.

**Il n'y a aucun port de debug matériel sur cette carte.** Le JTAG de l'ESP32-S3
demande `IO39`/`IO40`/`IO41`/`IO42`, or `IO40` porte `SD_PWR_EN` et `IO41`
`KBD_5V_EN` ; et l'USB-Serial/JTAG intégré est sur `IO19`/`IO20`, dépensées pour
l'hôte clavier. `TP10` est donc une simple broche numérique malgré son nom
JTAG, et `IO42` n'est pas sorti du tout — sa broche 35 est déclarée non connectée.

**Contrainte de placement** : garder les `TP` de GPIO **près de `U1`**, en grappe
lâche derrière le module. Pas pour les aligner — chacun va où il veut — mais parce
qu'une piste GPIO non terminée près de l'antenne rayonne. Deux millimètres de
moignon valent mieux que vingt.

## Ce qui reste à faire

- [ ] **Finir le routage.** 2 connexions restantes, plus les 13 points de test
      à importer et poser.
- [ ] **Relire le schéma.** 106 composants, relus par une seule paire d'yeux. L'ERC
      est à zéro et le netlist a été vérifié bloc par bloc, mais sur une carte
      qu'on fait fabriquer c'est le jalon qui compte.
- [ ] **Tracer les fils.** La connectivité passe par des **étiquettes globales**,
      pas par des fils : électriquement équivalent, ERC-propre, netlist identique.
      Mais c'est aride à lire. Les tracer est un travail de souris qui ne change
      pas le netlist — la découpe en feuilles, elle, est faite.
- [ ] **Confirmer les 25 perçages Ø0,2 mm** — les matrices thermiques de U1, U2 et
      U3 — sur
      la page de capacités du fabricant. Seul poste de la carte sous le procédé
      courant, donc le seul susceptible de changer de catégorie tarifaire.
- [ ] **Frais de chargeur à arbitrer.** Tous les passifs sont Basic ou Preferred,
      donc exemptés. Restent ~12 lignes Extended à 3 $ : les 5 ICs (incompressible),
      les 4 inductances (JLCPCB n'a **aucune** inductance de puissance en Basic) et
      les connecteurs.
- [ ] **Revérifier les stocks à la commande**, en particulier les références
      Extended : la bibliothèque JLCPCB installée date de juillet 2025.
- [ ] Reprendre `hardware/bom.md` et `hardware/wiring.md` : ils décrivent le montage
      de banc — devkit et deux perfboards — et non cette carte. Le brochage y est
      celui du DevKitC-1, donc faux pour le module nu.

## Points ouverts, à trancher au banc

- **La protection thermique de la cellule est désactivée.** La cellule EEMB n'a pas
  de NTC, donc `TS` est polarisé par un pont fixe au centre de la fenêtre autorisée.
  C'est la conséquence assumée du choix de cellule — détail et valeurs dans
  [`../DESIGN-NOTES.md`](../DESIGN-NOTES.md).
- **Le courant de charge n'est pas sourcé.** La fiche de la cellule EEMB 103395 n'a
  pas été consultée, et l'`ICHG` par défaut du BQ25896 n'est pas vérifié. `/CE` étant
  à la masse, c'est cette valeur par défaut qui s'applique au premier branchement,
  avant que le firmware ne parle en I²C — donc avant toute programmation possible.
- **Consommation du CH343P en veille.** Son `VIO` est sur le 3V3 permanent (c'est
  l'usage prévu de cette broche) tandis que `VDD5` vient de VBUS. À mesurer : si le
  quiescent est significatif devant les ~84 µA visés, l'alimenter autrement.
- **Luminosité de la LED du bouton.** Spécifiée 12 V, alimentée en 3V3 : elle
  fonctionnera faiblement. La résistance série se règle au bring-up, **sans
  descendre sous 100 Ω** — elle sert aussi à borner une inversion de connecteur.
- **Trois JST-PH identiques.** Batterie, contact et LED sont mutuellement
  enfichables : la protection contre le mésappariement est devenue électrique, pas
  mécanique. Le tableau des cas dans [`../DESIGN-NOTES.md`](../DESIGN-NOTES.md) fait
  partie du cahier des charges du layout (sérigraphie explicite, connecteur batterie
  écarté des deux autres).
- **Détection de carte µSD non câblée** (`DET_A` en l'air). Si elle devient utile,
  IO9 est libre et compatible.

### Budget de veille visé

ESP32-S3 en deep sleep ~10 µA + BQ25896 (BATFET passant, High-Z) 32 µA + TPS63001
40 µA + 2× SSD1683 en deep sleep mode 2 (`0x10`/`0x03`) 2 µA + µSD coupée ≈ **84 µA**,
soit ~5 ans. L'autodécharge de la cellule (~2–3 %/mois, l'équivalent de ~150 µA)
domine largement : en pratique la veille tient **~22 mois**, et c'est elle qui fixe
la limite, pas l'électronique. Tout ce qui passe sous ~50 µA optimise du bruit.

## Régénérer, contrôler, fabriquer

Tout l'outillage est dans [`../common/`](../common) et les commandes dans
[`../README.md`](../README.md).

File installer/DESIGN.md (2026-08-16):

# Typoena installer — design

A self-contained macOS CLI (ratatui TUI) that prepares an SD card so a
**pre-flashed** Typoena is ready to use the moment the card goes in. The public
entry point is the one-liner on typoena.dev:

    curl -fsSL https://typoena.dev/install.sh | sh

`install.sh` downloads this prebuilt binary; the binary does the rest. The user
needs **no repo checkout and no Rust toolchain** — just the card.

## Decisions

- **Self-contained end-user tool.** No `just`, no typewriter checkout. The
  binary bundles what it needs (config templates, snippet catalog). The proven
  `just` bash (`firmware/justfile`) is the *reference spec* for the safety
  behaviours, ported to Rust — not shelled out to.
- **The installer never flashes.** Devices ship **pre-flashed from
  manufacturing**; setup is SD-card-only. Firmware field updates
  (auto-update) are a **device/roadmap** concern, not the installer's — see
  [`docs/plan/macroplan.md`](../docs/plan/macroplan.md) (v1.x note).
- **The card's repo is a fresh `git clone` from the remote** (HTTPS + PAT),
  written straight onto the card. There is no local source clone to mirror, so
  none of the rsync machinery applies: **no `--ff-only` refresh, no `.gitignore`
  excludes, no repack** — a fresh clone already contains only tracked files and
  is a single pack, and its origin is already the HTTPS URL we cloned from.
- **Lives in `typewriter/installer/`**, tracked in the firmware repo so it
  versions in lockstep with the config templates + snippet catalog it ships.

## Phase pipeline (the wizard)

1. **Preflight** — a mounted card + git present. Advisory; warnings don't block.
2. **Configure** — collect Wi-Fi SSID/pass, GitHub user, GitHub token, git
   remote, and commit identity (the remote field sits **after** user + token so
   a bare repo name can complete against the now-known username). Pre-fill via
   the derive ladder (below); the token comes from **Sign in with GitHub** (^G,
   device flow) or a pasted PAT. The remote accepts shorthand — a bare `notes`
   (→ `https://github.com/<gh_user>/notes.git`), `you/notes`, `you/notes.git`,
   `github.com/you/notes`, and SSH pastes (`git@host:…`, `ssh://…`) all expand
   to the canonical HTTPS clone URL (`expand_remote_url_with_user`, live
   "→ will use …" hint under the field); the conf and the clone only ever see
   the expanded form, since the device's libgit2 is HTTPS-only.
3. **SD card** — pick the card (refuse on ambiguity), `git clone` the remote
   onto `/repo`, seed `.typoena.toml` + snippets if absent, write
   `typoena.conf`, strip `._*`, eject.
4. **Done** — "put the card in your Typoena and power on."

## Safety behaviours to keep (from `firmware/justfile` — do NOT regress)

- **Card-ambiguity refusal** — never guess when >1 removable volume; a wrong
  guess lets a write hit the wrong disk. Refuse and ask.
- **`.typoena-dirty` guard** — refuse to overwrite a card that carries
  unpushed device edits; offer backup-and-discard.
- **AppleDouble `._*`** — `dot_clean` before eject; `._pack-*.idx` corrupts the
  pack scan (Mac git *and* device libgit2).
- **Token never derived** — it comes from the ^G sign-in or is typed, never
  scraped from this Mac; plaintext on FAT means physical custody is the
  control. Device-flow tokens carry only the Typoena app's `contents:write`
  on repos the user granted; a pasted PAT should be fine-grained and scoped
  the same way. The clone uses the token so private notes repos work.

_Dropped vs. the old `just load` (now moot with clone-from-remote): rsync
mirror, `--ff-only` source refresh, `.gitignore` exclude list, `git repack -ad`._

## Config derive ladder (Configure step)

Each value: explicit input → derived from this Mac → prompt.
`author` ← `git config user.{name,email}` · `gh_user` ← `gh api user` ·
`ssid` ← live SSID if it can be read, else the top preferred network as a
**flagged guess** · `wifi_pass` ← Keychain (on ^K, may prompt macOS) ·
`remote` ← typed · `token` ← ^G Sign in with GitHub (device flow) or a typed
PAT (never derived).

**Wi-Fi SSID is best-effort, not authoritative.** On macOS 15+ (incl. Tahoe
26) `networksetup -getairportnetwork` reports "not associated" even when
connected, and `ipconfig`/`system_profiler` return `<redacted>` unless the
process holds Location Services permission — which a `curl | sh` binary won't.
So `config.rs` tries the real current SSID (dynamic Wi-Fi device via
`-listallhardwareports`, then `getairportnetwork`, then `ipconfig getsummary`),
and when all are blocked, falls back to the top of
`-listpreferredwirelessnetworks` as a guess. A guess sets `wifi_ssid_guessed`,
and the Configure step flags the field so the user confirms rather than trusts
it.

## Architecture / crates

- `ratatui` + its crossterm backend — TUI.
- `git2` — clone the remote onto the card, confirm origin. _[SD slice]_
- Config templates + snippet catalog embedded via `include_str!`
  (self-contained).

## Open items

- **Non-macOS** — Linux/Windows later; the work is macOS-first.
- **Clone target** — cloning ~hundreds of MB directly onto FAT via a reader;
  measure, and fall back to clone-to-temp-then-copy if it's too slow.
- **Re-provision** — the destructive case is covered: an existing card goes
  through an explicit **wipe-and-reclone** (`y`-confirmed screen showing origin +
  HEAD + unpushed-edit count; removes only `repo/` + the dirty journal, then
  clones fresh). Missing: a config-only rewrite that rotates the token or
  switches Wi-Fi *without* recloning, and backing up `.typoena-dirty` edits
  before wiping instead of only warning.

## The wizard, screen by screen

**App shell + Preflight.** Branded wizard with a `--check` headless mode; card
and git detection. Preflight reports only genuinely removable cards (via
`diskutil`) and never names `Macintosh HD` — a machine's own disk showing as
"available" alarms users.

**Configure.** Form + derive ladder, masked secrets, Keychain fill,
required-field validation.

**SD card.** Pick the card (boot disk excluded) → `git clone` onto it (single
pack, clean HTTPS origin) → seed `.typoena.toml` → write `typoena.conf` → strip
`._*` → eject. The clone runs on a worker thread streaming progress: `git clone
--progress` is split on `\r`/`\n` (line-buffered reading swallows the in-place
ticks) and parsed into a gauge, and the scrolling log keeps only the phase-final
`done.` lines.

**Navigation.** `Tab` / `Shift-Tab` move forward and back through fields *and*
steps, spilling at the ends; vim `h/j/k/l` on the non-form steps; arrows work
too. The sidebar shows `✓` done / `▸` current / dim pending, a `move` box, and a
live gate hint (`fill required` / `write card first` / `→ <next>`), so
"when and where can I go" is always visible.

**Brand header.** A single block caret types `typoena`, then the site's tagline,
paced against a wall-clock `Instant` rather than the render tick so the cadence
is frame-rate-independent. Solid while writing, blinks for 10 s once both lines
land, then settles.

## Sign in with GitHub (device flow)

`^G` on Configure asks GitHub for a one-time code (client_id
`Iv23liwgnE86ITDpBdnn`, the org-owned "Typoena" GitHub App — public by design,
no client secret in the device flow), shows it big, auto-opens
github.com/login/device, and polls in the background
(`authorization_pending` / `slow_down` honored, Esc cancels via an atomic flag)
until the `ghu_` token lands in the token field. The panel is modal on Configure
(plain Esc/n/q cancel; `^N`/`^P` are inert so a reflexive step-jump can't kill
the flow). HTTP is system `curl` — no HTTP crate; GitHub's OAuth endpoints
answer form-encoded, parsed by a tiny percent-decoding parser. `ghu_` tokens
speak the same `x-access-token:<token>` basic auth as a PAT, so the clone path
and the firmware are unchanged; a manual PAT paste remains the fallback. If the
app has token expiry on, the success message flags the token's lifetime.

**Authorization ≠ installation.** The token proves identity, but it only reaches
repos the app is *installed* on — a clone of an uninstalled repo 403s
(`Write access to repository not granted`), and the device flow never installs
anything, so every first-time `^G` user would hit it. Two guards:

- the token is probed against `GET /repos/{owner}/{repo}` the moment sign-in
  completes. No access → a yellow flag on Configure with the fix; `^O` opens the
  install page and a background watcher re-probes (5 s, ~2 min) so the flag
  turns green the moment the repo is granted. (`^I` would be the mnemonic, but
  Ctrl-I *is* Tab on a terminal.) Verdicts remember the remote they judged, so
  editing the field retires a stale flag. Advisory only: non-GitHub hosts and
  network failures stay silent.
- the SD step detects that 403's stderr signature and fails with a hint pointing
  at `github.com/apps/typoena/installations/new`, plus Enter-to-retry — no new
  sign-in needed, since token access is evaluated live.

## Release

Public GitHub releases on `typoena/typewriter`, one per `installer-v*` tag: a
universal macOS binary (lipo arm64+x86_64, stripped) with a `.sha256` sidecar.
`typoena.dev/install.sh` (in the [[typoena-site]] repo) is a Darwin guard → curl
of binary + sidecar from `releases/latest/download` → `shasum -c` verify →
`exec … </dev/tty`. Cutting a tag is the whole deploy.

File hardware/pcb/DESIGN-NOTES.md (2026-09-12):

# Typoena — valeurs de conception et leur source

Chaque valeur non évidente du schéma, avec la page de datasheet dont elle sort. Le
schéma porte les valeurs ; ce fichier porte le *pourquoi*, une seule fois.

## BQ25896RTW — chargeur / power path (datasheet SLUSC76C)

Adresse I²C **0x6B**. Boîtier WQFN-24-EP 4×4, empreinte stock
`Package_DFN_QFN:Texas_RTW_WQFN-24-1EP_4x4mm_P0.5mm_EP2.7x2.7mm_ThermalVias`.

Le symbole est dérivé du `Battery_Management:BQ25895RTW` stock : **trois broches
diffèrent** entre les deux puces, tout le reste est identique.

| Broche | BQ25895 | BQ25896 |
| --- | --- | --- |
| 2 | D+ | **PSEL** |
| 3 | D− | **/PG** |
| 24 | DSEL | **NC** |

Régénérable : `scratchpad/gen_syms.py` contrôle le brochage complet des 25 broches
contre le §6 de la datasheet avant d'écrire.

### Valeurs

| Élément | Valeur | Source |
| --- | --- | --- |
| Inductance SW → SYS | **1 µH** | §10.2 Typical Application |
| C sur VBUS | 1 µF | §10.2 |
| C sur PMID | 10 µF | §10.2 (8,2 µF au schéma type ; 10 µF est la valeur E-standard la plus proche) |
| C sur BTST (vers SW) | 47 nF | broche 21 : « connect the 0.047 µF bootstrap capacitor from SW to BTST » |
| C sur REGN | 4,7 µF / 10 V | broche 22 |
| C sur BAT | 10 µF | broche 13/14 : « connect a 10 µF closely to the BAT pin » |
| C sur SYS | 2 × 10 µF | broche 15/16 : « connect a 20 µF closely to the SYS pin » |
| R sur ILIM | **150 Ω** | `IINMAX = KILIM / RILIM`, KILIM 320…390 A·Ω (§8.5) → plafond 2,4 A typ / 2,6 A max |

**Pourquoi 150 Ω et pas les 260 Ω du schéma type.** Le plafond matériel ne doit pas
être la contrainte qui mord : en charge, l'entrée alimente *à la fois* la charge
(~1,5 A visés) et le système (~0,5 A à 3V3 plus le clavier). 260 Ω plafonnerait à
1,5 A et brimerait la charge dès que la machine tourne. Le firmware fixe la vraie
limite par `IINLIM` (REG00) selon l'alimentation branchée.

### Broches de configuration câblées en dur

| Broche | Niveau | Raison |
| --- | --- | --- |
| PSEL (2) | **GND** | déclare une alimentation « adapter » et non un port USB hôte : limite par défaut plus haute |
| OTG (8) | **GND** | l'OTG est délibérément inutilisé — le 5 V clavier vient du TPS61023. Le maintenir bas garantit que le boost ne peut pas démarrer |
| /CE (9) | **GND** | charge active par défaut : **la carte charge sans une seule ligne de firmware** |
| TS (11) | pont **10 k (REGN) / 12 k (GND)** | voir ci-dessous |

**Le pont sur TS.** La cellule EEMB n'expose pas de thermistance. Le BQ25896 suspend
la charge si TS sort de sa fenêtre, donc il faut le polariser dans la plage
« température normale » : entre `V(T3)` = 44,75 % et `V(T2)` = 68,25 % de REGN pour
une charge à plein régime (§8.5, JEITA Thermistor Comparator). Le pont 10 k/12 k met
TS à **54,5 %** de REGN, bien au centre. REGN étant coupé hors charge (§9.2.6 : « the
REGN LDO stays off to minimize the quiescent current »), ce pont **ne consomme rien en
veille** — ce qui compte, vu que le budget de veille est le critère de conception.

> :warning: Le revers : la protection thermique de la cellule est désactivée. C'est la
> conséquence assumée d'une cellule sans NTC. Si un jour la cellule en expose une, le
> pont se remplace par la thermistance et le firmware n'a rien à changer.

## TPS63001DRCR — buck-boost 3V3 (datasheet SLVS520)

Sortie **fixe 3,3 V**, VSON-10-EP 3×3 (boîtier DRC). Symbole **et** empreinte stock :
`Regulator_Switching:TPS63001` + `Package_SON:Texas_DRC0010J_ThermalVias`.

| Élément | Valeur | Source |
| --- | --- | --- |
| Inductance L1↔L2 | **2,2 µH** | §8.2, Table 1 (VLF4012-2R2) |
| C entrée | 10 µF | §8.2 |
| C sortie | **2 × 10 µF** | §8.2 |

> :warning: Ne pas « améliorer » ce filtre. §8.2.1 : *« The TPS63000 series have internal
> loop compensation. Therefore, the external LC filter has to be selected according to
> the internal compensation. »* Mettre 22 µF parce qu'on en a en stock déstabilise la
> boucle.

| Broche | Niveau | Raison |
| --- | --- | --- |
| EN (6) | **VSYS** | le 3V3 doit monter sans firmware et ne jamais être coupé — le MCU dort dessus |
| VINA (8) | **VSYS** | alimentation de l'étage de contrôle |
| PS/SYNC (7) | **GND** | 0 = mode économie d'énergie actif, ce qui donne le quiescent annoncé |
| FB (10) | **VOUT** | §8.2.1 : sur la version à sortie fixe, FB **doit** être relié à VOUT. Pas de pont de contre-réaction |

### Pourquoi pas le TPS63802, qui était meilleur sur le papier

Le TPS63802 fait 11 µA de quiescent et 2 A sur toute la plage, contre 40 µA typ
(50 max) et 800 mA en mode boost ici. Il a été écarté parce que son boîtier VSON-HR
(DLA0010A) n'existe dans aucune bibliothèque KiCad : il aurait fallu dessiner
l'empreinte à la main, et **une empreinte faite main est le seul artefact d'un schéma
qu'aucun outil ne peut valider** — une numérotation de pastilles inversée passe l'ERC,
le DRC et la relecture des Gerbers, et ne se découvre qu'à la mise sous tension.

Ce qu'on a payé pour supprimer ce risque :

| | TPS63802 | TPS63001 | Effet réel |
| --- | --- | --- | --- |
| Quiescent | 11 µA | 40 µA | veille 25 → 22 mois (l'autodécharge de la cellule, ~150 µA, domine de toute façon) |
| Sortie, mode buck | 2 A | 1200 mA | pic mesuré ~600–700 mA → ~2× de marge |
| Sortie, mode boost | 2 A | **800 mA** | le mode boost ne s'enclenche que sous VSYS 3,3 V, soit **sous le seuil de coupure basse** qu'on implémente déjà |
| Prix ×1 | ~1,3 $ | 1,73 $ | |

En prime, la sortie fixe supprime le pont 511 k / 91 k et sa dérive.

## TPS61023DRL — boost 5 V clavier (datasheet SLVSF14B)

| Élément | Valeur | Source |
| --- | --- | --- |
| Inductance VSYS→SW | **1 µH** | §8.2 Typical Application |
| C entrée | 10 µF | §8.2 |
| C sortie | 2 × 22 µF | §8.2 |
| Pont FB, R10 (VOUT→FB) | **56 kΩ** 1 % | calcul ci-dessous |
| Pont FB, R11 (FB→GND) | **7,5 kΩ** 1 % | idem |

VREF = 595 mV (PWM) → 0,595 × (1 + 56/7,5) = **5,04 V**, dans la fenêtre USB
4,75–5,25 V. Avec la tolérance de 1 % sur les deux résistances, la sortie reste entre
4,95 et 5,13 V. Les ~79 µA du pont sont sur le rail 5 V, coupé en veille : sans effet
sur le budget. Le 56 kΩ est mutualisé avec R26 et R27, les rappels CC de l'USB-C.

C'est le **rapport** qui fixe la sortie, à 1 % près sur chaque résistance : toute paire
de rapport 7,5 donne la même tension. Les valeurs sont hautes pour que le pont, en
travers de la sortie tant que le boost tourne, ne consomme presque rien.

`EN` (2) porte un **pulldown 100 kΩ** : le rail clavier est **éteint par défaut**, y
compris GPIO flottant et pendant le deep sleep.

## Les quatre inductances de puissance

Aucune n'existe en Basic — **JLCPCB n'a aucune inductance de puissance dans sa
bibliothèque Basic**, ni la bibliothèque CDFER qui la suit. Ce sont donc quatre lignes
Extended, dont une mutualisée.

| Réf | Valeur | Référence | LCSC | Empreinte |
| --- | --- | --- | --- | --- |
| L1 (BQ25896) | 1 µH, 4,15 A, 18 mΩ | Sunlord SWPA4030S1R0NT | C42193 | `L_APV_ANR4030` |
| L3 (TPS61023) | **même référence que L1** | — | C42193 | `L_APV_ANR4030` |
| L2 (TPS63001) | 2,2 µH, 2,9 A, 44 mΩ | Bourns SRN4018-2R2M | C913207 | `L_Bourns-SRN4018` |
| L4 (panneau) | 47 µH, 1,2 A, 200 mΩ | Sunlord SWPA6045S470MT | C36414 | `L_APV_ANR6045` |

Mutualiser L1 et L3 sur la même référence économise une ligne de BOM, soit 3 $ de frais
de chargeur.

### Pourquoi une empreinte « APV » pour un composant Sunlord

C'est déroutant à la lecture, donc autant l'écrire : `L_APV_ANR4030` porte le nom d'une
série d'un autre fabricant, mais son motif est **identique au millième près** à celui que
Sunlord recommande pour le SWPA4030S — pastilles **1,10 × 3,70 mm, entraxe 3,00 mm**.
Idem pour `L_APV_ANR6045` face au SWPA6045S : **1,70 × 5,70 mm, entraxe 4,50 mm**. Les
deux séries partagent le même code de taille (4030 = 4,0 × 4,0 × 3,0 mm) et donc la même
implantation.

La correspondance a été établie **par calcul** — en analysant les 692 empreintes
d'inductances de KiCad et en comparant taille de pastille et entraxe aux cotes `a`/`b`/`c`
du tableau *Recommended Land Pattern* de la datasheet SWPA — et non à l'œil. Ça évite de
dessiner deux empreintes à la main.

> :warning: **L'erreur à ne pas reproduire.** Ces quatre inductances étaient initialement
> spécifiées en 0805 et 1210. À 1 µH ou 2,2 µH, un boîtier 0805 contient une inductance
> **de signal calibrée pour ~50 mA**, pas les 1 à 4 A de nos rails. Ni l'ERC ni la
> relecture du netlist ne peuvent voir ce genre d'erreur : elle ne vit que dans le choix
> d'empreinte. Les vraies inductances font 4 × 4 et 6 × 6 mm, ce qui pèse sur le budget
> de surface de la carte.

## Panneau GDEY0579T93 — étage de puissance (datasheet §9 Reference Circuit)

Recopie littérale du circuit publié. Le SSD1683 est en COG sur la dalle et pilote un
étage à découpage **externe** : il sort la commande de grille (`GDR`, broche 2) et lit
le courant (`RESE`, broche 3) ; l'inductance, le MOSFET et les diodes sont à nous.

| Réf | Valeur |
| --- | --- |
| L | 47 µH / 500 mA |
| Q | Si1308EDL (SOT-323) |
| D ×3 | **B5819W** (SOD-123) — substitution, voir ci-dessous |
| R grille | 1 MΩ |
| R shunt | 2,2 Ω |
| R sur TSCL / TSDA | 10 kΩ ×2 |
| C sur 3V3 | 4,7 µF / 25 V |
| C sur VDHR, VGH, VSL, VGL, VCOM, VSH, VDD, VCI, PREVGH, PREVGL | 1 µF / 25 V ×9 |

`BS` (broche 8) à la masse : sélectionne le SPI 4 fils. Alimenté depuis le **3V3**,
aucun rail supplémentaire.

### La seule substitution par rapport au circuit de référence

Les trois MBR0530 sont remplacées par des **B5819W** (`C8598`). Motif : la MBR0530 est
Extended chez JLCPCB, la B5819W est **Basic** — 3 $ de frais de chargeur en moins et
un stock de 648 000 pièces au lieu de 87 000.

Elle est mieux dimensionnée sur les trois axes qui comptent ici : 40 V au lieu de 30,
1 A au lieu de 0,5, même boîtier SOD-123. La tension directe est comparable (600 mV
à 1 A contre 550 mV à 500 mA), et aux courants réels de cette pompe de charge —
quelques dizaines de mA — les deux tournent autour de 300 mV. C'est cette tension qui
fixe l'écart entre les rails ±15 V théoriques et réels, donc c'est le paramètre à
surveiller au banc si le contraste du panneau surprend.

Aucune autre substitution : le **Si1308EDL** est conservé tel quel malgré son statut
Extended. Le SSD1683 pilote sa grille avec un driver faible, et le choix d'origine tient
à sa très faible charge de grille (1,4 nC). Le 2N7002W en SOT-323, Preferred et dix fois
moins cher, ne commute que 115 mA contre 1,5 A — ce n'est pas un substitut.

## Bloc bouton

Les trois connecteurs off-board sont en **JST-PH 2,0 mm 2 points** (batterie, contact,
LED) — c'est le format en stock. Ce choix abandonne la règle anti-mésappariement de
`docs/bom.md:40` : la protection devient électrique.

| Erreur de branchement | Protection |
| --- | --- |
| Batterie → connecteur contact | 10 kΩ série → ~420 µA dans la diode de clamp du GPIO |
| Batterie → connecteur LED | **résistance série 100 Ω, jamais 0 Ω** → ~40 mA au lieu d'un court sur le 3V3 |
| Batterie inversée → connecteur LED | même résistance, via la diode de corps du 2N7002 |
| Contact ↔ LED intervertis | inoffensif dans les deux sens |

LED du bouton mesurée : s'allume à 3 V comme à 5 V, tension nominale annoncée 12 V —
elle embarque donc presque certainement sa propre résistance dimensionnée pour 12 V.
Alimentée en 3V3 elle tirera ~1 mA et **sera peu lumineuse** ; c'est assumé, la valeur
de la résistance série se règle au bring-up sans jamais descendre sous 100 Ω.

## Contraintes de brochage MCU

`PWR_SENSE` et le reed switch de couvercle doivent être dans **GPIO 0–21** : sur
ESP32-S3, seuls les RTC GPIO réveillent d'un deep sleep (`ext0` / `ext1`). C'est la
seule contrainte de brochage qui ne se voit pas sur un schéma.

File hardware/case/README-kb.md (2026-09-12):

# Enclosure — integrated-keyboard variant (concept)

The one-piece [**Typoena**](../../README.md): the same reclined e-paper deck as
the [bring-your-own-keyboard body](README.md), with a keyboard tray grafted onto
the front — AlphaSmart / Freewrite silhouette, typewriter proportions. Two
sizes, both built on off-the-shelf QMK PCBs so "custom" means switches,
caps and keymap, not PCB design:

| `kb` | keyboard | body (W × D) | print |
| --- | --- | --- | --- |
| `"60"` | GH60 footprint (DZ60, YMDK…) | 291.3 × 202.4 mm | monolithic, 300 bed |
| `"40"` | Planck footprint, ortho, MIT (2u) | 232.1 × 180.7 mm | monolithic |

> **Status: v0 concept, not yet printed.** The wedge half is inherited verbatim
> from the proven base model. The `"40"` bay is dimensioned from OLKB's published
> CAD part (see below); the `"60"` bay's tray-mount numbers are still best-guesses
> marked `<< VERIFY >>` until checked against a real DZ60 drawing.

**The Planck is discontinued** — Drop's store closed 31 March 2026 and olkb.com no
longer lists one. Buy a clone that advertises Planck-case compatibility (JJ40,
Niu Mini): those keep the footprint the `"40"` numbers come from, and both plates
cut MIT as well as grid. A clone that doesn't claim compatibility (Pabile P48,
Boardsource Equals 48) may fit the bay but will not land on these posts — caliper
it and re-derive `kb_holes` before printing.

| 60% (GH60) | 40% (Planck) |
| --- | --- |
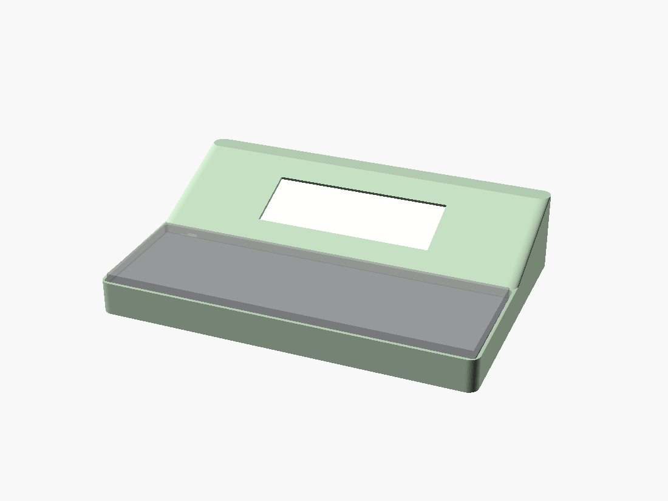
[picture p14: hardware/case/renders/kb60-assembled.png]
60% variant assembled — keyboard tray in front, reclined deck behind
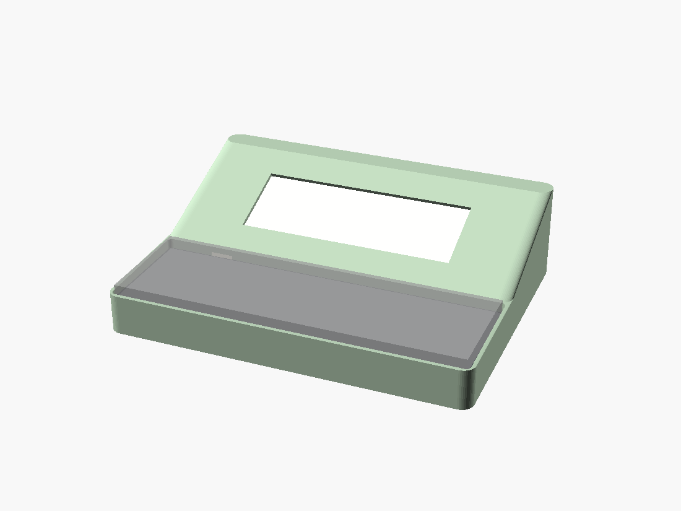
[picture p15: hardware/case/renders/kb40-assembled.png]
40% Planck variant — same silhouette, 59 mm narrower
|  |  |

## How it composes

[`typoena-case-kb.scad`](typoena-case-kb.scad) `include`s the base model and
overrides only `W`: the whole wedge — screen clamp, the mainboard across the
back, the front battery, the baseplate and the ports — carries over at the new
width and is translated back by the bay depth. The screen re-centres on the wider
deck and the right-hand baseplate bosses track the new right wall; the board, the
battery and the I/O cluster keep their distance from the **left** wall. The bay is
additive:

- **Tray mount.** The keyboard PCB screws to integral posts on the bay floor
  (standard GH60 tray positions for the 60%; for the 40, the Planck's five M2
  holes read off [`olkb_parts`](https://github.com/olkb/olkb_parts/blob/master/planck/planck-pcb-module.kicad_mod) —
  the same part gives the 226.5 × 73.5 outline and puts the USB notch rear-left,
  37.25 mm in, not centred).
  Plate floats on the switches, walls locate it with 0.75 mm wiggle. The rim
  (`Hk = 26` at the front) hides the plate edge, caps sit proud; toward the
  deck it rises to meet the wedge's front-top edge flush, so bay and deck
  join without a seam.

  **`Hk` and `kb_post_h` track the base model's `Hf`.** `Hf` isn't only the
  wedge's front height here — it *is* the bay/cavity shared wall, the wall behind
  the top key row. Raise it and that wall climbs while the keyboard stack stays
  put: at the base model's +4 with these left alone, the caps drop from **3.1 mm
  proud of the wall to −0.9 mm** and the back row sits in a well. Both carry the
  same +4 (`Hk` 22→26, `kb_post_h` 8→12), which restores 3.1 mm over the wall and
  5.1 mm over the front rim exactly, and the plate stays hidden. `kb_cable_cut`
  derives from `kb_pcb_z`, so the USB passthrough follows the taller posts on its
  own — no third number to chase.
- **Internal USB.** The keyboard stays a stock QMK device. Its cable leaves
  through a slot in the shared wall into the wedge cavity and lands on **`J13`**,
  the mainboard's 4-pin JST-PH (VBUS/D−/D+/GND) wired in parallel with the
  keyboard USB-C. That receptacle faces **out** the back wall and can't take an
  internal plug, so the model fills its cutout: the back wall shows only charge,
  µSD and the power switch. (Direct matrix-on-GPIO — dropping the 5 V boost
  and USB host for wake-on-key — is a possible v2; it costs 19 pins plus matrix
  scan and a keymap in firmware.)
- **Floor + feet.** The bay has an integral 3 mm floor and its own front feet;
  the wedge keeps its drop-in baseplate for service access.

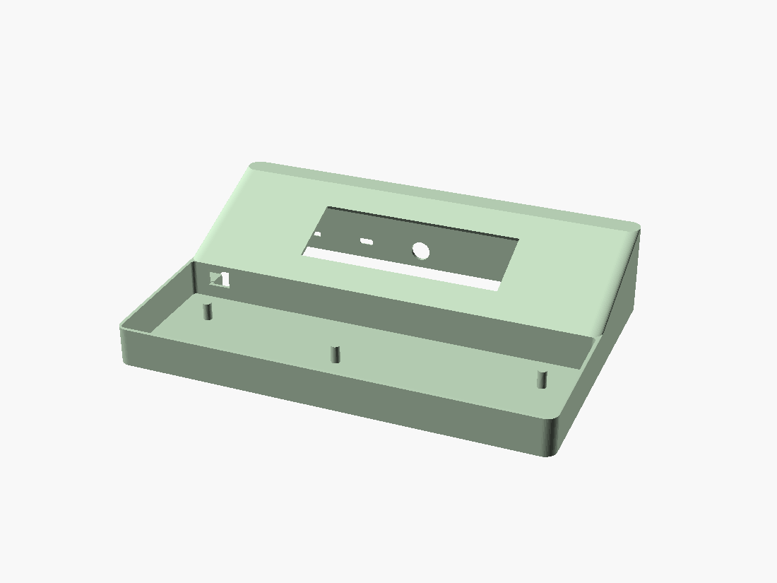
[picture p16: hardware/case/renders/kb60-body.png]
60% body — tray posts, USB passthrough slot, screen recess behind

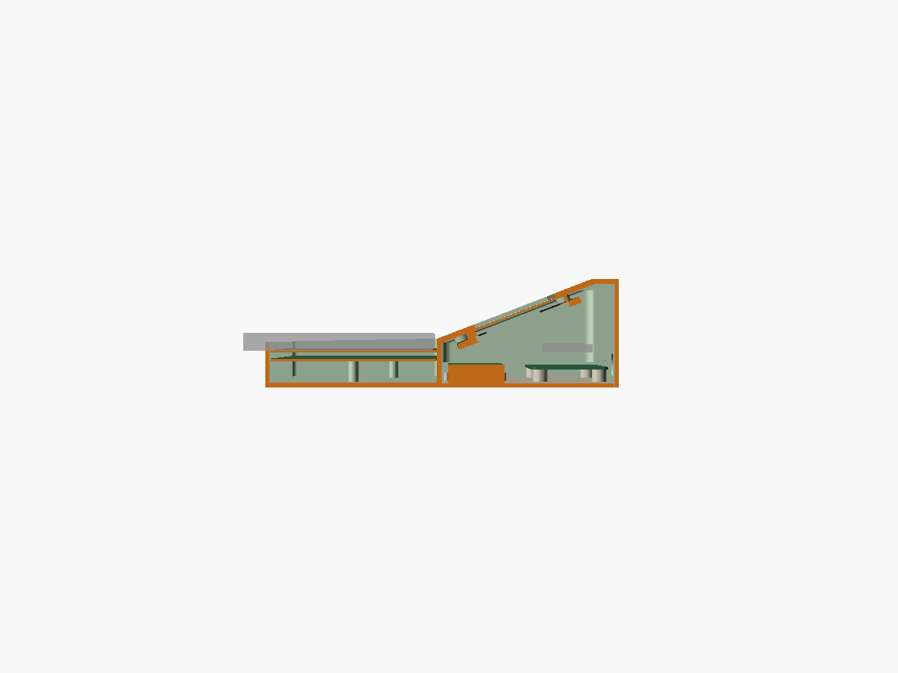
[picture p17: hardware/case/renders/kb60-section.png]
Section — tray stack in front, battery and boards in the wedge

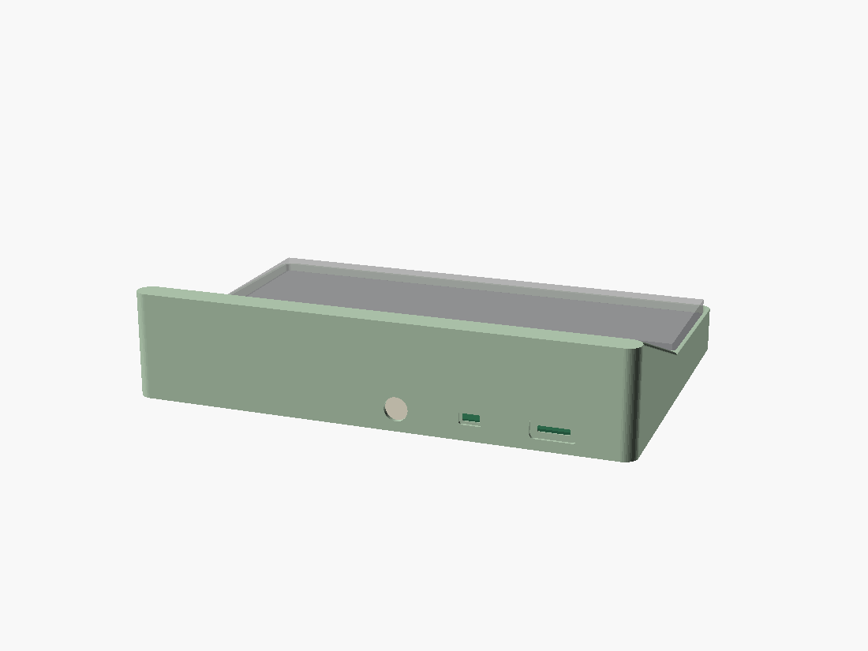
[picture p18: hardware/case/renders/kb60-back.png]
Back wall — just charge, µSD and the power switch now


## Render / export

From `hardware/`:

```sh
just render-kb   # regenerate case/renders/kb*.png (both sizes)
just stl-kb      # kb60/kb40 body + baseplate STLs (bracket comes from `just stl`)
```

`show` accepts `kb_assembled` · `kb_body` · `kb_baseplate` · `kb_section` ·
`kb_print`. **`kb` and `W` move as a pair** (`"60"` → 291.30, `"40"` → 232.05);
an include-override must be a literal, so `W` can't follow `kb` by itself — the
model asserts if they drift.

## Verify before printing

- [ ] **Tray post positions** against the actual PCB drawing (`kb_holes`) — the
      GH60 set is the commonly-cited standard; the 40 set is OLKB's own CAD, so
      it only holds for a Planck-compatible clone.
- [ ] **USB position + slot** (`kb_usb_x`, `kb_post_h`): the plug head must pass
      the shared-wall slot and clear the wedge cavity behind it. The slot is
      rear-left, so re-check it against the battery cage rather than assuming
      centre.
- [ ] **MIT stabiliser clearance** — a 2u space wants a PCB-mount stab hanging
      below the PCB; confirm `kb_post_h = 12` still leaves room over the bay floor.
      It now sits the PCB 15 mm up off a 3 mm floor, so there is 12 mm under the
      board — the +4 that came with the body's height helps here.
- [ ] Everything on the base model's own list (battery dims, active-area offset).

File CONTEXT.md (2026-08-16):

# Typoena

A single-purpose writing appliance: e-ink + mechanical keyboard + ESP32-S3. The
user opens the lid, writes Markdown, and (when they choose) pushes to a git
remote. This glossary fixes the language of that workflow, and of the screen
the writer looks at while doing it.

**Related docs:**
[`README.md`](README.md) — project overview, hardware, macro roadmap.
[`docs/adr.md`](docs/adr.md) — load-bearing decisions; **ADR-010** is the
formal record of the **Push** UX defined below.
[`docs/quality/qfd.md`](docs/quality/qfd.md) — requirements ↔ functions ↔ components, ranked
by user-facing weight. References the terms in this file as canonical.
[`docs/reference/commands.md`](docs/reference/commands.md) — every `:` command
and `>` palette action these terms name.

## Language

### File scopes

**Tracked**:
A file that lives in the device's git working copy and can be pushed to the
remote. Lives under `/sd/repo/`.
_Avoid_: synced, public, remote, committable.

**Local**:
A file that exists only on the device and can never be pushed. A
permanently-private scope, not a draft staging area — files are born Local and
stay Local for their lifetime. Lives under `/sd/local/`.
_Avoid_: draft, private, untracked, scratch (these all imply impermanence or
promotability, which is not the model).

### Editing model

**Buffer**:
A **File** loaded into memory for editing, with its own caret, scroll position,
and undo history. Opening a file makes it the **active buffer** — the one the
**Writing column** shows. Up to three buffers stay **resident** at once (the
active one plus two parked in the background); switching back to a resident
buffer restores its caret and undo without re-reading the card. A fourth open
**evicts** the least-recently-used resident buffer — saved first if it has
unsaved edits, so nothing is lost.
_Avoid_: tab, window, document (a buffer is not a UI chrome element); "the file"
when you mean the in-memory copy rather than the bytes on the card.
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

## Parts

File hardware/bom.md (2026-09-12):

# Typoena — project BOM

> Every physical part in the build, one table per subsystem. Purchase links for
> the power-path parts live in
> [v0.10 — Power switch + power path](../docs/plan/v0.10-battery-and-sleep.md#power-switch--power-path--decided-2026-07-26)
> (status-checked 2026-07-26); this file is the reference-of-record for _what_
> each part is, and [wiring.md](wiring.md) for _how the parts connect_ (pin
> map, per-subsystem nets, inter-board harness). Rows marked `⟨ref?⟩` need the
> exact reference confirmed by Julien.

## Core electronics

| Part | Reference / pick | Notes |
| --- | --- | --- |
| MCU dev board | **ESP32-S3-DevKitC-1 v1.0** (module **ESP32-S3-WROOM-1-N16R8**: 16 MB flash, 8 MB octal PSRAM) | Board rev v1.0 confirmed (RGB LED on GPIO 48, not 38). Pinout: `firmware/docs/esp32-s3-devkitc-1-v1.0-pinout.jpg` |
| E-paper panel | **Good Display GDEY0579T93** — 5.79″ B/W, 792 × 272, dual SSD1683 | Glass 150.92 × 56.94 × 1.0 mm, active 139.00 × 47.74 mm; FPC exits left |
| E-paper adapter | **Good Display DESPI-C579** | Panel FPC → SPI breakout; usually sold as a kit with the panel |
| Keyboard | User-supplied 60 % USB keyboard — bench unit is a **NuPhy (VID:PID 19f5:3255)** ⟨exact model ref?⟩ | Any boot-protocol HID keyboard works; VBUS-only USB-C host port (no CC) |
| µSD card | Genuine **SDHC ≤ 32 GB** (bench: 32 GB) | Hard requirement: large/counterfeit SDXC rejects CMD59 (CRC) in SPI mode — firmware refuses it |
| µSD slot / breakout | microSD→pin SPI adapter board, soldered to PCB 2 ⟨ref?⟩ | |
| USB-C breakout ×2 | 4-pin USB-C breakout (VBUS/D+/D−/GND), one keyboard-host + one charge-in ⟨ref?⟩ | Keyboard port sources 5 V straight onto VBUS; optional 56 kΩ Rp (CC→VBUS) for stricter keyboards |

## Power

Design + behavior contract + purchase links:
[v0.10 power-path section](../docs/plan/v0.10-battery-and-sleep.md#power-switch--power-path--decided-2026-07-26).

| Part | Reference / pick | Notes |
| --- | --- | --- |
| Charger board | **HW-373** (TP4056 + DW01A/FS8205A protection, USB-C) | On PCB 2. Bare TP4056 is not a power-path controller — hence the P-FET/Schottky circuit |
| Boost converter | **MT3608** module, trimmed to ~5 V — bought: [AZDelivery](https://www.amazon.fr/dp/B089QHXF8K) | On PCB 1. No fixed-output module in this current class — set the trim pot to 5.0 V with a meter before wiring the load, ≤ 5.5 V max (devkit LDO stress); input peaks ~2 A during refresh + Wi-Fi |
| Battery | **EEMB 103395** — 1S LiPo 3.7 V 3700 mAh, 10.3 × 33 × 95 mm, JST-PH 2.0 plug ([Amazon](https://www.amazon.fr/dp/B08215B4KK)) | Installed, powering the bench build — measure the real cell (incl. lead exit) and fill the scad's `bat_*` `<< MEASURE >>` |
| Power switch | **QitinDasen** Ø12 mm latching push button, red LED, IP66, pre-wired — bought ×3 (2026-08-01) | Gate signal only, never in the load path; flip on = boot, flip off = clean shutdown + sleeping-Typo off card; LED stays **unwired** — contract + rationale in the [v0.10 power-path section](../docs/plan/v0.10-battery-and-sleep.md#power-switch--power-path--decided-2026-07-26) |
| P-MOSFET ×2 | **AO3401A** (SOT-23, P-ch 30 V 4 A) | #1 load-sharing switchover, #2 soft-power latch in the load path |
| N-MOSFET | **2N7002** (SOT-23) | `PWR_HOLD` GPIO holds the latch gate low; 100k pulldown so a crashed ESP32 releases it |
| Signal diode | **1N4148** | Button → latch gate pull; keeps `PWR_SENSE` readable |
| Schottky diode | **SS34** (3 A 40 V; SOD-123F or the easier-to-solder SMA) | Mains → load node feed |
| Resistors / cap | 100 kΩ ×3, 10 kΩ ×1, ≥ 100 nF ×1 | Gate pull-up/pulldowns, `PWR_SENSE` series, press-stretch cap — any stock |
| Battery connector | **JST-PH 2.0 mm** 2-pin — bought (2026-08-01): 20× male plugs + 20× pre-wired female pigtails, 10 cm red/black silicone | :alert-triangle: polarity not standardized — verify red = B+ before first plug-in |
| Button connector | **JST-XH 2.54 mm** 2-pin, pre-wired pair | Different family from the battery on purpose — can't cross-mate |
| Reed switch (lid close, v0.10) | Not yet picked ⟨ref?⟩ | Deep-sleep wake source; blocked on the hinged-lid decision |

## Boards & interconnect

| Part | Reference / pick | Notes |
| --- | --- | --- |
| PCB 1 | Perfboard/protoboard **50 × 70 mm** ⟨ref?⟩ | Devkit + DESPI-C579 + MT3608; Ø2 corner holes |
| PCB 2 | Perfboard/protoboard **20 × 80 mm** ⟨ref?⟩ | µSD + 2× USB-C + HW-373; connectors overhang 8 mm |
| Jumper wire | F-F Dupont rainbow jumpers + rainbow ribbon ⟨ref?⟩ | Vertical rows make PCB 1 ~22 mm tall — drives the case's rear placement |
| FFC coupler | **sourcing map** 24-pin ↔ 24-pin FFC/FPC extension adapter, 0.5 mm pitch — bought ×1 (2026-08-01) | Joins the panel FPC to the extension cable below, for slack routing panel → DESPI-C579. **No spare** — the cable is ×2 but this is not |
| FFC cable | AWM 20624 flat flex, 24P, 0.5 mm pitch, 100 mm, **Type B** (opposite-side contacts) — bought ×2 | Pairs with the coupler; Type B flips contact side — check orientation at the DESPI-C579 end |

## Enclosure

Model: `hardware/case/typoena-case.scad`; assembly + print notes:
[hardware/case/README.md](case/README.md).

| Part | Reference / pick | Notes |
| --- | --- | --- |
| Filament, body | PLA/PETG, matte **sage `#B6CEB4`** ⟨ref?⟩ | |
| Filament, bracket + baseplate | PLA/PETG, cream or brass ⟨ref?⟩ | Two-tone via filament swap |
| Threaded inserts | **ruthex RX-6-32×3.8** brass heat-set, `GE-6-32X38-001` (bag of 50) | **×12**: bracket bosses ×4 and baseplate posts ×4 in the BODY, board standoffs ×4 in the BASEPLATE. Ø5.4 flange / Ø4.7 body; every bore is printed Ø4.8 with ≥1.8 mm of wall per the datasheet. Pressed in with a soldering iron before assembly — see *Fasteners* in [`hardware/case/README.md`](case/README.md) |
| Screws, insert joints | **#6-32 × 7 mm thread**, flat pan head 1.0 × Ø6.5 ⟨qty 12⟩ | One screw for the whole machine — bracket ×4, baseplate ×4, mainboard ×4 (its corner holes are a Ø3.7 #6-32 clearance). Measured off the part, not a catalogue number — the model budgets bore depth at 8 mm of thread, so **caliper a screw if the batch changes**. The four baseplate heads sit in a drilled lamage in the plate's underside, flush with the desk; the other eight bear on a printed face |
| Foam gasket | **A4 Technologie MOU-BL-5-A** — closed-cell PE foam, 48 kg/m³, 5 × 200 × 300 mm, €2.40 ([a4.fr](https://www.a4.fr/mousse-polyethylene-45kg-m3-5-x-200-x-300-mm-bleue.html)) | Non-adhesive. Spreads the bracket's clamp load on the 1 mm glass, and its squash (`foam_t` 5.0 → `foam_c` 3.5, 30 %) IS the clamp preload — see the CONTRACT on `foam_c`. Density matters: 48 kg/m³ ≈ Plastazote LD45; cosplay EVA (85–125) is too firm at this squash. Cut as a frame, not a pad — `module foam()` is the template |
| Battery fixing | Foam / VHB tape ⟨ref?⟩ | Plus the baseplate cage nibs |
| Feet (optional) | Printed (modelled) vs stick-on rubber bumpers — undecided | Open TODO in the case README |

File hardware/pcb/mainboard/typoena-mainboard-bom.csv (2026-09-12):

Reference | Value | Footprint | MPN | LCSC | QUANTITY | DNP
C1,C14,C18,C19,C20,C22,C23,C24,C25,C26,C27,C28 | 1uF | Capacitor_SMD:C_0603_1608Metric | CL10A105KB8NNNC | C15849 | 12
C2,C5,C6,C7,C8,C9,C10,C13,C16,C30 | 10uF | Capacitor_SMD:C_0805_2012Metric | CL21A106KAYNNNE | C15850 | 10
C3 | 47nF | Capacitor_SMD:C_0603_1608Metric | CL10B473KB8NNNC | C1622 | 1
C4,C21 | 4.7uF | Capacitor_SMD:C_0805_2012Metric | CL21A475KAQNNNE | C1779 | 2
C11,C12,C17 | 22uF | Capacitor_SMD:C_0805_2012Metric | CL21A226MAQNNNE | C45783 | 3
C15,C29 | 100nF | Capacitor_SMD:C_0402_1005Metric | CL05B104KO5NNNC | C1525 | 2
D1 | SMF5.0A | Diode_SMD:D_SOD-123 | SMF5.0A | C19077497 | 1
D3,D4,D5 | B5819W | Diode_SMD:D_SOD-123 | B5819W | C8598 | 3
J1 | BATTERIE JST-PH | Connector_JST:JST_PH_S2B-PH-K_1x02_P2.00mm_Horizontal | S2B-PH-K-S | C173752 | 1 | DNP
J2 | BOUTON contact JST-PH | Connector_JST:JST_PH_S2B-PH-K_1x02_P2.00mm_Horizontal | S2B-PH-K-S | C173752 | 1 | DNP
J3 | BOUTON LED JST-PH | Connector_JST:JST_PH_S2B-PH-K_1x02_P2.00mm_Horizontal | S2B-PH-K-S | C173752 | 1 | DNP
J4 | FPC 24p 0.5mm - PANNEAU | Connector_FFC-FPC:Jushuo_AFC07-S24FCA-00_1x24-1MP_P0.50_Horizontal | AFC07-S24FCA-00 | C262567 | 1
J6 | USB-C CHARGE + PROG | Connector_USB:USB_C_Receptacle_HRO_TYPE-C-31-M-12 | TYPE-C-31-M-12 | C165948 | 1
J7 | USB-C CLAVIER (hote) | Connector_USB:USB_C_Receptacle_HRO_TYPE-C-31-M-12 | TYPE-C-31-M-12 | C165948 | 1
J8 | microSD | Connector_Card:microSD_HC_Molex_104031-0811 | 1040310811 | C585350 | 1
J9 | UART PROG | Connector_PinHeader_2.54mm:PinHeader_1x06_P2.54mm_Vertical |  |  | 1 | DNP
J13 | CLAVIER INTERNE | Connector_JST:JST_PH_S4B-PH-K_1x04_P2.00mm_Horizontal | S4B-PH-K-S | C157926 | 1 | DNP
L1,L3 | 1uH 4.15A | Inductor_SMD:L_APV_ANR4030 | SWPA4030S1R0NT | C42193 | 2
L2 | 2.2uH 2.9A | Inductor_SMD:L_Bourns-SRN4018 | SRN4018-2R2M | C913207 | 1
L4 | 47uH 1.2A | Inductor_SMD:L_APV_ANR6045 | SWPA6045S470MT | C36414 | 1
Q1 | AO3401A | Package_TO_SOT_SMD:SOT-23 | AO3401A | C15127 | 1
Q2,Q3,Q5,Q6 | 2N7002 | Package_TO_SOT_SMD:SOT-23 | 2N7002 | C8545 | 4
Q4 | Si1308EDL | Package_TO_SOT_SMD:SOT-323_SC-70 | SI1308EDL | C7603347 | 1
R1 | 150R | Resistor_SMD:R_0603_1608Metric | 0603WAF1500T5E | C22808 | 1
R2,R4,R5,R6,R15,R18,R19,R22,R23,R28,R29,R30 | 10k | Resistor_SMD:R_0402_1005Metric | 0402WGF1002TCE | C25744 | 12
R3 | 12k | Resistor_SMD:R_0402_1005Metric | 0402WGF1202TCE | C25752 | 1
R10,R26,R27 | 56k 1% | Resistor_SMD:R_0603_1608Metric | 0603WAF5602T5E | C23206 | 3
R11 | 7.5k 1% | Resistor_SMD:R_0603_1608Metric | 0603WAF7501T5E | C23234 | 1
R12,R13,R14,R17 | 100k | Resistor_SMD:R_0402_1005Metric | 0402WGF1003TCE | C25741 | 4
R16 | 100R | Resistor_SMD:R_0402_1005Metric | 0402WGF1000TCE | C25076 | 1
R20 | 1M | Resistor_SMD:R_0402_1005Metric | 0402WGF1004TCE | C26083 | 1
R21 | 2R2 | Resistor_SMD:R_0805_2012Metric | 0805W8F2R20T5E | C17521 | 1
R24,R25 | 5k1 1% | Resistor_SMD:R_0402_1005Metric | 0402WGF5101TCE | C25905 | 2
R31,R32 | 4k7 | Resistor_SMD:R_0402_1005Metric | 0402WGF4701TCE | C25900 | 2
SW1 | QON | Button_Switch_SMD:SW_SPST_B3U-1000P | B3U-1000P | C231329 | 1 | DNP
SW2 | RESET | Button_Switch_SMD:SW_SPST_B3U-1000P | B3U-1000P | C231329 | 1
SW3 | BOOT | Button_Switch_SMD:SW_SPST_B3U-1000P | B3U-1000P | C231329 | 1
TP1 | GND | TestPoint:TestPoint_THTPad_D2.0mm_Drill1.0mm |  |  | 1 | DNP
TP3 | +3V3 | TestPoint:TestPoint_THTPad_D2.0mm_Drill1.0mm |  |  | 1 | DNP
TP4 | I2C_SDA | TestPoint:TestPoint_THTPad_D2.0mm_Drill1.0mm |  |  | 1 | DNP
TP5 | I2C_SCL | TestPoint:TestPoint_THTPad_D2.0mm_Drill1.0mm |  |  | 1 | DNP
TP6 | IO1 | TestPoint:TestPoint_THTPad_D1.5mm_Drill0.7mm |  |  | 1 | DNP
TP7 | IO2 | TestPoint:TestPoint_THTPad_D1.5mm_Drill0.7mm |  |  | 1 | DNP
TP8 | IO8 | TestPoint:TestPoint_THTPad_D1.5mm_Drill0.7mm |  |  | 1 | DNP
TP9 | IO9 | TestPoint:TestPoint_THTPad_D1.5mm_Drill0.7mm |  |  | 1 | DNP
TP10 | IO39 | TestPoint:TestPoint_THTPad_D1.5mm_Drill0.7mm |  |  | 1 | DNP
TP12 | IO47 | TestPoint:TestPoint_THTPad_D1.5mm_Drill0.7mm |  |  | 1 | DNP
TP13 | IO48 | TestPoint:TestPoint_THTPad_D1.5mm_Drill0.7mm |  |  | 1 | DNP
U1 | ESP32-S3-WROOM-1-N16R8 | RF_Module:ESP32-S3-WROOM-1 | ESP32-S3-WROOM-1-N16R8 | C2913202 | 1
U2 | BQ25896RTW | Package_DFN_QFN:Texas_RTW_WQFN-24-1EP_4x4mm_P0.5mm_EP2.7x2.7mm_ThermalVias | BQ25896RTWR | C181475 | 1
U3 | TPS63001DRCR | Package_SON:Texas_DRC0010J_ThermalVias | TPS63001DRCR | C28060 | 1
U4 | TPS61023DRL | Package_TO_SOT_SMD:SOT-563 | TPS61023DRLR | C919459 | 1
U5 | CH343P | Package_DFN_QFN:WCH_QFN-16-1EP_3x3mm_P0.5mm_EP1.8x1.8mm | CH343P | C2846043 | 1

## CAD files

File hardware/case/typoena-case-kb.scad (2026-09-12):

// ============================================================================
//  Typoena — enclosure variant "kb"  ·  integrated-keyboard body  ·  rev v0
// ----------------------------------------------------------------------------
//  The one-piece writer: same reclined e-paper deck as typoena-case.scad, with
//  a keyboard tray grafted onto the front (AlphaSmart / Freewrite silhouette).
//  The keyboard is an off-the-shelf QMK PCB in a standard tray mount:
//
//    kb = "60"  — GH60-footprint PCB (DZ60/YMDK…), 285 x 94.6
//    kb = "40"  — Planck-footprint ortho PCB, 226.5 x 73.5, MIT (47 keys, 2u
//                 space). The Planck itself is discontinued; buy a clone that
//                 advertises Planck-case compatibility (JJ40, Niu Mini).
//
//  It connects over USB *internally*: a short cable runs from the keyboard PCB
//  through a slot in the shared wall into the wedge cavity, to J13 on the
//  mainboard — the 4-pin JST-PH (VBUS/D-/D+/GND) wired in parallel with the
//  keyboard USB-C. That receptacle faces out the back wall and cannot take an
//  internal plug, so this model FILLS its cutout: the back wall shows only
//  charge, µSD and the power switch.
//
//  This file `include`s typoena-case.scad and overrides W (bay width wins over
//  screen width) — the whole wedge (screen clamp, board, battery, baseplate,
//  ports) carries over verbatim, translated back by the bay depth. The screen
//  re-centres on the wider deck; the board, the battery and the I/O cluster keep
//  their distance from the LEFT wall, and only the right-hand baseplate bosses
//  track the new right wall. `show` here uses kb_* names so the parent file's
//  own show-chain stays dormant.
//
//  Units: millimetres.   Render: see README-kb.md
//
//  Parts (set `show` below, or -D from the justfile):
//    "kb_assembled" – everything in place, coloured (keyboard ghosted in)
//    "kb_body"      – the one-piece shell (bay floor + tray posts integral)
//    "kb_baseplate" – the wedge chassis, re-widened (drops in from below)
//    "kb_section"   – vertical cut: tray stack in front, screen clamp behind
//    "kb_print"     – printable parts laid out (body, baseplate, bracket)
// ============================================================================

include <typoena-case.scad>

show = "kb_assembled";
kb   = "60";                 // "60" (GH60 tray) | "40" (Planck)

// ---- keyboard PCB + plate (datasheet / ecosystem-standard numbers) ---------
kb_pcb_w   = kb=="60" ? 285.00 : 226.50;
kb_pcb_d   = kb=="60" ?  94.60 :  73.50;
kb_plate_w = kb=="60" ? 285.75 : 226.50;   // universal 60% plate is the widest part
kb_plate_d = kb=="60" ?  95.25 :  73.50;   // sandwich plate follows the PCB outline
// tray-mount posts, (x from PCB LEFT edge, y from PCB TOP/back edge).
// The 40 set is the Planck's five M2 (Ø2.2) holes off OLKB's own CAD part
// (olkb_parts/planck/planck-pcb-module.kicad_mod, origin = board centre); the
// ten Ø2.9 holes there are acrylic-sandwich standoffs, unused here.
// << 60 set still VERIFY against a DZ60 drawing before printing >>
kb_holes   = kb=="60"
    ? [[25.2,27.9],[128.2,47.8],[259.8,27.9],[190.5,85.2]]      // GH60 std
    : [[18.25,17.75],[208.25,17.75],[18.25,55.75],[208.25,55.75],[113.25,36.75]];
// USB-C centre from PCB left edge. Same CAD part: the Planck's is a 13 mm notch
// in the back edge, rear-LEFT — not centred, so the passthrough slot is off-axis.
kb_usb_x   = kb=="60" ? 19 : 37.25;

// ---- bay geometry -----------------------------------------------------------
kb_int_w  = kb_plate_w + 0.75;   // plate floats on the switches; 0.75 wiggle
kb_int_d  = kb_plate_d + 0.75;
kb_d      = wall + kb_int_d;     // bay depth; the wedge's own front wall is the
                                 // SHARED wall between bay and cavity
kb_floor  = 3.0;                 // integral bay floor (no baseplate up front)
// CONTRACT: these two track Hf. Hf is the bay/cavity shared wall, so the wall
// behind the TOP KEY ROW rises with it while the keyboard stack does not — at the
// base file's +4 and these left at 8.0 / 22 the caps drop from 3.1 mm proud of
// that wall to -0.9 and the back row sits in a well. Both carry the same +4, which
// restores 3.1 proud of the wall and 5.1 of the front rim exactly.
kb_post_h = 12.0;                // floor -> PCB bottom << VERIFY vs USB slot >>
Hk        = 26;                  // bay rim: hides the plate edge, caps sit proud
DT        = kb_d + D;            // total body depth

// width now comes from the keyboard, not the screen — this override reflows the
// whole included wedge (screen re-centres, the right-hand bosses and the
// baseplate re-derive; the board and its ports stay put against the left wall).
// MUST be a literal: an include-override is evaluated at the base file's first
// W assignment, before any variant variable exists (expressions land undef).
// Keep the kb/W pair in sync — the assert below refuses a mismatch.
//   kb="60" -> W = 291.30      kb="40" -> W = 232.05   ( = kb_int_w + 2*wall )
W = 291.30;
assert(abs(W - (kb_int_w + 2*wall)) < 0.01,
       "W is out of sync with kb — see the table above this assert");

// derived tray-stack heights (MX: plate top = PCB top + 5.0)
kb_pcb_z   = kb_floor + kb_post_h;            // PCB bottom face
kb_plate_z = kb_pcb_z + pcb_t + 5.0 - 1.5;    // plate bottom face (1.5 plate)
// PCB placed centred in the bay interior; its TOP edge (USB side) faces the deck
kb_px0 = (W - kb_pcb_w)/2;                    // PCB left edge, world X
kb_py1 = wall + (kb_int_d + kb_pcb_d)/2;      // PCB top/back edge, world Y

// ===========================================================================
//  keyboard bay
// ===========================================================================
// back pillars sit at the wedge's front-pillar XY so the two hulls share one
// continuous side wall and corner radius. They rise to Hf (not Hk): the rim
// top must meet the wedge's front-top edge flush — at Hk it stops 2 mm short
// and the wedge's receding corner leaves an open slot at each junction corner.
module bay_outer() {
    hull() for (x=[corner_r, W-corner_r]) {
        translate([x, corner_r,        0]) cylinder(h=Hk, r=corner_r);
        translate([x, kb_d + corner_r, 0]) cylinder(h=Hf, r=corner_r);
    }
}

module bay_cavity() {
    translate([W/2, wall + kb_int_d/2, kb_floor])
        linear_extrude(Hk) rrect(kb_int_w, kb_int_d, 3);
}

// Solid: the keyboard's M2 Ø1.6 pilots are DRILLED after the print, not
// modelled. A Ø1.6 hole is two or three perimeters wide, so the printer rounds it
// to whatever its extrusion width allows and the self-tapper meets a hole of
// unknown size; a bit cuts 1.6. The Ø6 pad leaves 2.2 mm of wall around it.
module bay_posts() {
    for (h = kb_holes)
        translate([kb_px0 + h[0], kb_py1 - h[1], kb_floor])
            cylinder(h=kb_post_h, r=3);
}

module bay_feet() {
    for (fx=[corner_r+6, W-corner_r-6])
        translate([fx, corner_r+6, -foot_h]) cylinder(h=foot_h+0.1, r=foot_r);
}

// USB passthrough in the shared wall: keyboard PCB -> wedge cavity -> the
// mainboard's J13. Sized for a low-profile USB-C plug head.
module kb_cable_cut() {
    translate([kb_px0 + kb_usb_x - 8, kb_d - 2, kb_pcb_z - 3])
        cube([16, wall + 4, 12], center=false);
}

// the external keyboard USB-C opening, filled: that port turns inward (J13 on
// the mainboard), so the wall stays blank there. Sized off the boot pocket, not
// the shell, or the pocket stays sunk in the wall around a filled slot.
// Local wedge coordinates — union it inside the translated wedge.
module kb_port_patch() {
    pw = usbc_boot_w + 1;
    ph = usbc_boot_h + 1;
    translate([port_x[1] - pw/2, D - wall, port_z[1] - ph/2])
        cube([pw, wall, ph]);
}

module variant_body() {
    difference() {
        union() {
            translate([0, kb_d, 0]) { case_body(); kb_port_patch(); }
            // bay back pillars reach corner_r past the shared wall — carve the
            // wedge cavity out of the bay solid too, or that band re-fills the
            // cavity's front (battery space) up to Hk
            difference() {
                bay_outer(); bay_cavity();
                translate([0, kb_d, 0]) body_cavity();
            }
            bay_posts();
            bay_feet();
        }
        kb_cable_cut();
    }
}
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

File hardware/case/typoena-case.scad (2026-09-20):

// ============================================================================
//  Typoena — 3D-printed enclosure  ·  "typewriter body"
// ----------------------------------------------------------------------------
//  A shallow sage wedge. The e-paper strip sits on a reclined deck where a
//  typewriter's sheet of paper would be; the keyboard you bring rests in front.
//  No platen part (keeps the print simple) — the rounded back-top edge is a
//  subtle roll that nods to one for free.
//
//  Everything here is PARAMETRIC. Every number is off a datasheet or measured on
//  the part; the source is noted where it matters.
//
//  Units: millimetres.   Render:  see hardware/case/README.md
//
//  Parts (set `show` below):
//    "assembled"   – everything in place, coloured (screen ghosted in)
//    "body"        – the shell only (print deck-up or on its back)
//    "bracket"     – the screen retaining frame (print flat)
//    "baseplate"   – the chassis / bottom cover (print flat)
//    "feet"        – the four stick-on feet, laid flat for printing
//    "print_plate" – all printed parts laid out side by side
//    "section"     – vertical cross-section: how the screen is trapped
//    "plan"        – exploded horizontal section: deck lifted off the cavity
//    "plan_up"     – just the top half (deck / screen / bracket)
//    "plan_down"   – just the bottom half (cavity: standoffs, bosses, ports)
//    "io_coupon"   – TEST PRINT: a flat slice of the back wall with only the
//                    I/O openings (2x USB-C, µSD, power button) — dry-fit check
//    "drill_guide" – TOOL: the corner block that holds the Ø4 bit on a baseplate
//                    screw passage — print FOUR (see README, "Drilling the
//                    baseplate"); "drill_guide_fit" shows them in use
// ============================================================================

show = "assembled";
$fn = 20;

// ---- what this model is ---------------------------------------------------
// NOMINAL GEOMETRY ONLY. Every dimension below is the part as it must END UP,
// and every clearance is the functional gap wanted on the finished assembly.
// The machine's own error is NOT modelled here and must not be: it belongs to the
// process, not to the part, and it is corrected in the slicer. The setting, its
// qualified value and how to re-measure it are in MANUFACTURING.md, which is
// required reading before any print — the number is per filament, and its sign
// doubles the error when it is wrong.

// ---- fasteners ------------------------------------------------------------
// ONE family for everything that screws into the BODY: a ruthex RX-6-32x3.8
// brass heat-set insert (#6-32, Ø4.7 body / 3.8 long) taking a #6-32 pan screw,
// 7 mm of thread under a 1 mm x Ø6.5 head. Both are measured parts, not
// catalogue numbers.
// The bore is a PLAIN cylinder: no relief is modelled for the insert's head end,
// the iron sinks it. HAZARD: nothing in the part then says when to stop pressing
// — the bore is deliberately deeper than the insert, so flush is by eye (or by a
// depth stop on the iron), and the boss's free end is a seating face on both
// joints. See the assembly order in the README.
// WHY inserts and not the self-tapped PLA of v0: these are the two joints that
// get OPENED — the baseplate every time the machine is serviced, the bracket
// every time the glass comes out. A self-tapped thread in PLA is good for a
// handful of cycles and then it is a stripped hole in a 10-hour print.
// The BOARD is in this family too: its four Ø3.7 holes are a #6-32 clearance and
// it screws down into an insert in each standoff, so nothing in the machine is a
// self-tapped thread and nothing on the baseplate has to be drilled.
ins_hole_d  = 4.8;   // hole the datasheet asks for. The insert melts its own seat,
                     // so this is not a clearance fit — the brass must grip what it
                     // is pressed into.
ins_min_h   = 4.8;   // ...and its minimum DEPTH. Same number as the diameter by
                     // coincidence only — never fold the two together. Going
                     // deeper is free and every bore here does; the floor is what
                     // matters.
ins_len     = 3.8;   // insert length — the thread the screw actually gets
ins_wall    = 1.8;   // datasheet minimum material around the hole. Heat-setting
                     // pushes melt outward, so every boss below is sized to beat
                     // this, and asserts hold the line if a radius drifts.
scr_thread  = 7.0;   // thread under the head (measured) — this is the one that
                     // sizes ENGAGEMENT, i.e. how much brass the screw actually
                     // grips, and the asserts hold it over 2.5 mm.
scr_thread_max = 8.0;   // ...and the one that sizes DEPTH, deliberately 1 mm over:
                     // the datum is a screw laid on a tape measure. Over-budgeting
                     // buys hole depth (free); under-budgeting bottoms the screw
                     // and jacks the joint back open, or punches the deck.
scr_head_d  = 6.5;   // head Ø  (measured)
scr_head_h  = 1.0;   // head thickness (measured)
scr_clear_d = 3.9;   // clearance hole: #6-32 majors at Ø3.5
// depth of a blind insert bore: everything the thread can still bring past `over`
// (the insert plus whatever tip is left over), floored at the datasheet's 4.8.
// `over` is the material in front of the bore (plate crossed, bracket crossed)
// that the thread spends before it arrives. Overshooting costs only boss height,
// which the roof assert holds — bottoming a screw jacks the joint open.
function ins_bore_h(over) = max(ins_min_h, scr_thread_max - over);
// ...and how much brass the screw grips once it has crossed `over`. Capped at the
// insert: thread past the far end grips nothing.
function ins_grip(over) = min(ins_len, scr_thread - over);

// ---- body envelope --------------------------------------------------------
W        = 176;   // width  (X)  — screen 150.9 + bezel + walls
D        = 104;   // depth  (Y)  — front (keyboard) .. back (ports)
// The two heights MOVE AS A PAIR: theta is their difference over the full depth,
// so shifting both by the same amount translates the whole deck plane vertically
// and leaves the recline, deck_L, screen_cy and the entire screen clamp untouched.
// Raising Hf alone flattens the deck by ~1 mm per degree. What they have to buy
// is ceiling over the board's front edge, which is asserted at pcb_ceiling — the
// board stack clears by 19 mm here, so this pair is free to come down if a
// shorter machine is ever wanted.
// In the kb variant Hf is also the bay/cavity SHARED WALL, so Hk and kb_post_h
// must move with it or the top keycap row sinks into the wall — see README-kb.md.
Hf       = 28;    // height at the FRONT edge (y = 0)
Hb       = 68;    // height at the BACK edge  (y = D). Hf<Hb makes the reclined
                  // deck, and the deck plane runs edge to edge: both heights are
                  // ON it, with no flat at either end to break the slope.
wall     = 2.4;   // side/back wall thickness
top_wall = 3.4;   // deck thickness (before the bezel lip is cut into it), and it
                  // is TWO things stacked: lip_t of deck stands in FRONT of the
                  // glass, and what is left behind it is the pocket wall that
                  // holds the glass in X/Y. So it moves with lip_t — asserted
                  // below, because a deck that no longer swallows the glass
                  // leaves a pocket that clamps it without locating it.
corner_r = 8;     // rounded vertical + top-edge radius (the "machined" look)

// deck slope, derived from the two edge heights over the full depth — the deck
// IS this plane, from the front edge to the back one (see body_outer)
theta    = atan((Hb - Hf) / D);   // ~21 deg with the defaults
// >> THE ergonomics dial. Raise Hb for a more vertical, easier-to-read screen;
//    lower it for a flatter, more typewriter-like deck. 18-22 deg = shallow,
//    28-35 deg reads better when you're sitting close.
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

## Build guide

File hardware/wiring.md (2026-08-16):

# Typoena — wiring reference

> Every electrical connection in the build, one table per subsystem. Companion
> to [bom.md](bom.md) (_what_ each part is — this file is _how they connect_).
> Pin numbers are ESP32-S3-DevKitC-1 v1.0 GPIOs, verified against the firmware
> (`firmware/src/main.rs`, `firmware/src/infrastructure/storage_sd.rs`) and the
> QC pin map in [`firmware/docs/bench-qc.md`](../firmware/docs/bench-qc.md).
> Power-path design rationale + behavior contract:
> [v0.10 — Power switch + power path](../docs/plan/v0.10-battery-and-sleep.md#power-switch--power-path--decided-2026-07-26).

## The bench board

The bench build follows the **ESP32-S3-DevKitC-1 v1.0** pinout — an
ESP32-S3-WROOM-1 **N16R8** module (16 MB flash, 8 MB octal PSRAM). The v1.0
revision wires the on-board WS2812 RGB LED to **GPIO 48**; v1.1 moved it to
GPIO 38, so match assignments against this diagram, not the v1.1 one. The octal
PSRAM consumes **GPIO 26–37**, so those are unavailable for peripherals.

Pinout diagram: [Espressif ESP32-S3-DevKitC-1 v1.0 user guide][devkitc-1-v1.0].

[devkitc-1-v1.0]: https://docs.espressif.com/projects/esp-dev-kits/en/latest/esp32s3/esp32-s3-devkitc-1/user_guide_v1.0.html

## ESP32-S3 pin map

| GPIO | Net | Notes |
| --- | --- | --- |
| 4 | EPD BUSY | Input, pull-down — active-high (high = busy) |
| 5 | EPD RST | Output |
| 6 | EPD DC | Output |
| 7 | EPD CS | Output |
| 11 | EPD MOSI | SPI2 |
| 12 | EPD SCK | SPI2 |
| 10 | SD CS | SPI3, internal pull-up |
| 13 | SD MISO | SPI3, internal pull-up |
| 14 | SD SCK | SPI3, internal pull-up |
| 15 | SD MOSI | SPI3, internal pull-up |
| 19 | USB D− | Native PHY → keyboard USB-C breakout |
| 20 | USB D+ | Native PHY → keyboard USB-C breakout |
| 21 | `CHRG` (optional) | HW-373 charge status, open-drain, low = charging |
| 0 | BOOT button | Devkit strapping pin; QC operator confirm |
| 48 | WS2812 LED | On-devkit RGB (board rev v1.0 — not 38) |
| 40 | `PWR_HOLD` | Output → 2N7002 gate (see power signals below) |
| 41 | `PWR_SENSE` | Input, internal pull-up ← button via 10 kΩ |
| 1 | Battery sense (v0.10)  | **ADC1** — Wi-Fi disables ADC2 |

Free for later: 2, 8, 9 (ADC1), 16/17/18, 38, 39, 42, 47.
Off-limits: 26–37 (flash + octal PSRAM), 43/44 (console UART), 0/3/45/46
(strapping).

This is the bench build's pinout. The mainboard PCB assigns these pins
differently — see [`hardware/pcb/mainboard/README.md`](pcb/mainboard/README.md)
for the pin plan that ships.

## E-paper — DESPI-C579 header → devkit (PCB 1)

Panel FPC clips into the DESPI-C579; its 8-pin header wires to the devkit.

| DESPI-C579 pin | Devkit |
| --- | --- |
| VCC | 3V3 |
| GND | GND |
| SDI | GPIO 11 |
| SCK | GPIO 12 |
| CS | GPIO 7 |
| D/C | GPIO 6 |
| RES | GPIO 5 |
| BUSY | GPIO 4 |

## microSD — breakout on PCB 2 → devkit

Dedicated SPI3 host (own bus, no sharing with the EPD — ADR-012); firmware
enables internal pull-ups on all four lines.

| µSD breakout pin | Devkit |
| --- | --- |
| VCC | 3V3 |
| GND | GND |
| SCK / CLK | GPIO 14 |
| MOSI / CMD | GPIO 15 |
| MISO / DAT0 | GPIO 13 |
| CS / DAT3 | GPIO 10 |

## USB-C keyboard host — breakout on PCB 2 → devkit

The S3's native PHY is the host; the hard requirement is **sourcing 5 V onto
VBUS** (the S3 has no CC pins). Details + bench evidence:
[`bench-qc.md`](../firmware/docs/bench-qc.md).

| Breakout pin | Connects to |
| --- | --- |
| VBUS | 5 V rail (sourced **out** to the keyboard) |
| D+ | GPIO 20 — both orientation pads bridged (A6 & B6) |
| D− | GPIO 19 — both orientation pads bridged (A7 & B7) |
| GND | GND |
| CC1/CC2 | Optional 56 kΩ Rp → VBUS for stricter keyboards |

## USB-C charge-in — breakout on PCB 2

| Breakout pin | Connects to |
| --- | --- |
| VBUS | HW-373 IN+ — also the "mains 5 V" power-path net |
| GND | HW-373 IN− |
| D+/D− | Unused |

## Power path

Circuit diagram, behavior contract, and placement invariants live in the
[v0.10 section](../docs/plan/v0.10-battery-and-sleep.md#power-switch--power-path--decided-2026-07-26).
Not covered there: the MT3608 output (trimmed ~5.0 V, ≤ 5.5 V) feeds the
devkit's **5V pin** and the keyboard VBUS; all grounds are common.

### Power / control signals

| Signal | GPIO  | Wiring |
| --- | ----- | --- |
| `PWR_HOLD` | 40 | → 2N7002 gate (100 kΩ pulldown) |
| `PWR_SENSE` | 41 | ← button through 10 kΩ series, internal pull-up |
| `CHRG` | 21 | ← HW-373 charge-status pad, one wire (optional — pad access unconfirmed) |
| Battery sense | 1 | Planned (v0.10): 100k/100k divider + 100 nF into ADC1 — or MAX17048 |

## Off-board connectors

| Connector | Family | Wiring |
| --- | --- | --- |
| Battery | JST-PH 2.0 mm 2-pin | Pack plug → PCB 2 pigtail. :alert-triangle: polarity not standardized — verify red = B+ first |
| Power button | JST-XH 2.54 mm 2-pin  | Panel-mount button → `J5` on PCB 1: latch-gate net + GND; gate signal only (µA). LED wires left unwired |
| Panel FPC | 24-pin FPC | Folds back through the case's internal clearance slot into the DESPI-C579 |

## PCB 1 ↔ PCB 2 harness

PCB 1 (devkit + DESPI-C579 + MT3608, back-left) ↔ PCB 2 (µSD + 2× USB-C +
HW-373, back-right), rainbow ribbon + F-F Dupont (~22 mm vertical stack — see
the case README). Nets crossing the boards:

- SD SPI: GPIO 14/15/13/10 + 3V3 + GND
- Keyboard USB: GPIO 19/20 + 5 V (VBUS) + GND
- Power: mains 5 V (charge USB-C VBUS / HW-373) and battery OUT+ from PCB 2 into
  the power path on PCB 1, plus optional `CHRG`

The discrete power-path parts (FETs, diodes, latch network) all sit on **PCB 1**
with the MCU and the button connector `J5`, so `PWR_HOLD`/`PWR_SENSE` never
cross the harness. PCB 2 (20 × 80 mm) had no room left.

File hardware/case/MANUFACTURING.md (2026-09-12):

# Manufacturing — Typoena enclosure

The model is nominal geometry: every dimension in `typoena-case.scad` is the
dimension the finished part must measure. The machine's own error belongs to the
process, so it is corrected here, in the slicer, and never in the model.

| setting | Cura | value |
| --- | --- | --- |
| **XY compensation** | *Horizontal Expansion* (`xy_offset`, under *Shell*) | **0** |
| **Hole XY compensation** | *Hole Horizontal Expansion* (`hole_xy_offset`) | **0** |
| **Z** | — | no correction |

The qualified filament lands on nominal: a baseplate comes out 170.7 × 98.7 to
within what a caliper resolves, X and Y alike. There is nothing to take out, and
`hole_xy_offset` stays at 0 as well — it stacks on top of the first one and would
correct every insert bore twice.

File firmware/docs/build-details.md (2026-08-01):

# Build details — esp-idf, libgit2, the `full` feature

The first build is slow (the esp-idf C sources are checked out and built
under `.embuild/`; the build also compiles libgit2 + mbedTLS). Subsequent builds
are incremental — libgit2 is a fingerprint-cached esp-idf component, so editing
Rust never recompiles it. Editor and render-engine logic is host-tested
off-device (`cargo test -p app -p editor`), which is the fast iteration loop.

## The `full` feature — why libgit2 stays behind a switch

Pushing (`:gs`/`:gl` → git) and `:update` (OTA) drag in libgit2 + mbedTLS
(compiled as an esp-idf component) and the `git2` crate — expensive to build.
The `firmware` bin sets `required-features = ["full"]`, so the product firmware
always has them. `full` is nonetheless **off by default**, for one reason: a
bare `cargo build` and the standalone bench bins build WITHOUT libgit2.

| Target | `full` | libgit2 component | `git2` crate |
| --- | --- | --- | --- |
| `firmware` (`just build`/`flash`) | always (required-features) | compiled | linked |
| bench bins (`just build-bench`, …) | off | not compiled (empty no-op) | not linked |

Two independent switches gate libgit2, and the `full` recipes flip them together:

1. **`full` Cargo feature** (`--features full`) — pulls the `git2`/`libgit2-sys`
   crates and the `net`/`ota`/`wizard_io` modules. The `firmware` bin requires
   it; the bench recipes omit it.
2. **`LIBGIT2_SRC` env** — the [libgit2 component](../components/libgit2/CMakeLists.txt)
   only compiles its sources when this points at the vendored tree; unset, it
   registers an _empty_ component. Only the full recipes set it.

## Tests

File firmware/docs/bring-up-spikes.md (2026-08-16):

# Hardware bring-up — spike log

The chronological record of the bench spikes that brought the firmware up on
real silicon, kept as-verified (dates and measurements are from the bench
sessions). For what the crate is and how to build it, start at the
[firmware README](../README.md).

## Modal editor (vim modes) — verified 2026-07-05

The firmware became a small vim-style modal text editor. The
[`editor` crate](../../editor/src/lib.rs) owns the buffer, caret, motions, and
per-mode rendering; [`src/main.rs`](../src/main.rs) is the hardware loop that
drains keystrokes, redraws, and picks a refresh strategy;
[`src/drivers/keyboard_usb.rs`](../src/drivers/keyboard_usb.rs) decodes editing
chords and a dual-role Caps key. The buffer is pure ASCII, so a byte offset
doubles as the caret's character index (Tab expands to spaces on insert).

Modes (shown live in a small status strip below the text):

- **Insert** — the boot mode; keys type at the caret. `Ctrl+W` /
  `Ctrl+Backspace` delete the previous word, `Cmd+Backspace` deletes to the
  start of the line.
- **Normal** — motions `h j k l`, `w b e`, `0` `$`, `gg` `G`; edits `x`, `dd`,
  and the `d` / `c` (change) operators over motions and text objects — `ciw`,
  `daw`, `di(`, `ci"`, … (bracket pairs are nesting-aware); `i a A I o O` to
  enter insert; count prefixes like `3j`, `2dd`.
- **View** — read-only reading: `j` / `k` scroll, `space` pages, `gg` / `G`
  jump; edits are locked out.

**Caps Lock is dual-role**: tapped it is `Esc` (→ Normal); held it is `Ctrl`.
So Caps no longer types capitals — use Shift.

Rendering reuses the partial refresh from Spike 5: additive Insert typing stays
on the fast windowed path with a ~750 ms debounced caret, while caret moves,
deletes, mode switches, and View scrolling take a clean full-area partial
(~630 ms). Count prefixes collapse repeated motion into a single refresh, which
matters at this latency.

Known rough edges (deferred): no backspace auto-repeat (the keyboard is on
`SET_IDLE(0)` and only key-downs are tracked), non-sticky column on `j` / `k`,
the `$` / end-of-line block caret sits one cell past the last char, `iw` / `aw`
are whitespace-delimited (like vim's `iW` / `aW`), and `cw` isn't special-cased
to `ce`.

## Spike 6 — Wi-Fi + TLS: verified 2026-07-05

A separate binary — [`src/bin/wifi_tls.rs`](../src/bin/wifi_tls.rs), flashed
with `just flash-wifi` — kept apart from the editor firmware. It brings up the
station, syncs the clock over SNTP (mbedtls validates the server cert against
wall time, so the 1970 RTC has to be corrected first), then does an HTTPS GET
to `https://api.github.com/` with cert-chain validation against the esp-idf
certificate bundle (`esp_crt_bundle_attach`), and logs status, a body preview,
and free heap around the handshake (TLS heap pressure is a watched risk). A
validated GET was the gate for Spike 7 (git push over HTTPS + PAT).

Bench result (WPA2-PSK AP, 2.4 GHz): associate ~3 s → DHCP → SNTP first sync →
`esp-x509-crt-bundle: Certificate validated` → `HTTPS GET … → 200`, reading real
GitHub JSON. **TLS handshake cost ≈ 35 KB heap** (265 → 229 KB, recovered
after), clean and repeatable across reboots. Note: PSRAM was **not** enabled yet
(only ~339 KB internal heap) — TLS fits, but Spike 7's git working set needed
`CONFIG_SPIRAM` turned on first.

Credentials are build-time: copy [`.env.example`](../.env.example) to `.env`,
set `TW_WIFI_SSID` / `TW_WIFI_PASS`, and `just` loads them (dotenv) so
`build.rs` bakes them in. `.env` is gitignored; the SD bench (`sd_bench`) needs
none of it. `sdkconfig.defaults` gained the full certificate bundle and a bigger
main task stack for the mbedtls handshake.

## Spike 3 — SD card (FAT) on dedicated SPI3: verified 2026-07-11

A separate binary — [`src/bin/sd_bench.rs`](../src/bin/sd_bench.rs), flashed
with `just flash-bench` — is a thin on-device harness over the real SD storage
adapter ([`src/infrastructure/storage_sd.rs`](../src/infrastructure/storage_sd.rs),
`app::Storage`): it mounts the card, reports FAT usage, and round-trips an
atomic save/load (write `*.tmp` → fsync → unlink → rename → read-back). Per
ADR-012 the SD runs on its **own SPI3 host** —
**SCK 14 · MOSI 15 · MISO 13 · SD CS 10** — leaving the EPD alone on SPI2.
Verified on the dedicated SPI3 bus 2026-07-11 (same mount + round-trip result as
the initial shared-SPI2 bring-up).

Bench result (genuine 32 GB SDHC card): mounts at 10 MHz, `29806 MiB total`,
atomic round-trip byte-identical. Two findings baked into the code:

- **Card compatibility.** A 133 GB SDXC card failed init at `CMD59` (SPI-mode
  CRC); a genuine ≤32 GB card works. We keep CRC required and reject bad cards
  with a swap-the-card message rather than run over an unchecked bus. See the
  [Spike 3 postmortem](../../docs/record/postmortems/2026-07-05-spike3-sd-cmd59.md).
- **FatFS rename ≠ POSIX rename.** `f_rename` won't overwrite an existing
  target (returns `FR_EXIST`), so the atomic save unlinks the destination first.
  `storage_sd` pairs this with `*.tmp` boot-recovery (`recover` at mount): if a
  `*.tmp` is found _alongside_ the target the crash may have been mid-write, so
  it keeps the committed file and discards the tmp; it only promotes the tmp
  when the target was already unlinked. Long filenames
  (`CONFIG_FATFS_LFN_HEAP`) are required for the two-dot `*.md.tmp` name.

**Arbitration resolved (ADR-012):** the EPD driver holds an exclusive SPI2 lock
for its whole lifetime, and storage runs on its own thread, so a shared bus
would need an EPD rewrite plus a cross-thread mutex on the save path. Instead
the SD gets its own SPI3 — the EPD stays untouched, no arbitration. The atomic
save (unlink-then-rename + `*.tmp` boot-recovery) has since landed as the
`storage_sd` adapter behind `app::Storage`.

## Spike 5 — partial refresh + typing: verified 2026-07-04

`main.rs` wires the keyboard to the panel:
[`src/drivers/keyboard_usb.rs`](../src/drivers/keyboard_usb.rs) feeds decoded
key-downs (US layout, edge-detected) into a queue, and the main loop keeps a
wrapped, scrolling text buffer that it draws with a **partial refresh**
(`Epd::display_frame_partial`) per keystroke batch, plus a periodic full
refresh to clear ghosting. First spike where input and output run together.
Measured on the bench at 4 MHz SPI: partial refresh ~630 ms, full ~1870 ms —
the partial waveform (~490 ms, all 272 rows) dominates. Follow-up: windowed-Y
partial refresh (drive only the edited line's rows) to cut per-keystroke
latency.

## Spike 4 — USB host keyboard: verified 2026-07-04

[`src/drivers/keyboard_usb.rs`](../src/drivers/keyboard_usb.rs) drives the
ESP-IDF USB Host Library directly through the raw `esp-idf-sys` bindings (no
managed HID class driver), enumerates an attached keyboard, claims the
boot-keyboard interface, switches it to boot protocol, and polls the
interrupt-IN endpoint — decoding each 8-byte report into modifiers + keycodes.
Verified with a `19f5:3255` keyboard: keystrokes, modifiers, and rollover all
decode correctly.

Hardware: flash + serial over the CP2102 "UART" port (console = UART0,
independent of the USB PHY), keyboard on the native "USB" port. The keyboard
enumerated **bus-powered** — no external VBUS injection needed on this
DevKitC-1 v1.0 (keep a 5 V power cable only as a brownout fallback for
higher-power/RGB devices).

## Spike 2 — EPD: verified 2026-07-04

The GDEY0579T93 e-paper panel is driven through the thin dual-SSD1683 driver in
[`src/drivers/screen_epd.rs`](../src/drivers/screen_epd.rs) (ported from
GxEPD2's `GxEPD2_579_GDEY0579T93`). Verified on the bench rig over 4 MHz SPI:

- **2a — uniform fill:** clean full-panel white ↔ black refreshes, proving
  the wiring, both cascaded controllers, RAM addressing, and the full
  refresh waveform.
- **2b — graphics/text:** `epd::Frame` implements `embedded-graphics`'
  `DrawTarget`; a stroked circle straddling the master/slave seam (x = 396)
  renders round and continuous, and `FONT_10X20` text is legible — proving
  the split-and-mirror full-frame blit (`Epd::display_frame`).

Wiring: SCK 12 · DIN/MOSI 11 · CS 7 · DC 6 · RST 5 · BUSY 4, via the
DESPI-C579 breakout.

Every build is stamped by [`build.rs`](../build.rs) with UTC time and
`git describe --always --dirty`; the tag is logged on serial at boot and
drawn on the panel, so the running build is always identifiable during
diagnosis.

Bring-up note: the initial symptom was per-pixel noise on the panel — a
half-seated CS jumper, not firmware. If the panel shows speckle/banding,
reseat the jumpers (CS first) before debugging code.

## Spike 1 — Blink: verified 2026-07-04

GPIO 2 + on-board WS2812 toggled at 1 Hz with `blink N` on USB-serial, proving
toolchain, esp-idf link, and GPIO on real silicon. The blink code was replaced
by Spike 2 in `main.rs` (see git history: `e040a8d`).

**Pin choice:** GPIO 2 is a safe general-purpose pin on the ESP32-S3-DevKitC-1:
it's not tied to a strapping function at boot and not muxed to the USB or PSRAM
peripherals. The blink loop also drives the on-board addressable LED — WS2812
on GPIO 48 (GPIO 38 on DevKitC-1 v1.1 boards) — via the RMT peripheral, so both
a plain GPIO and the RMT path are exercised.

## Order

Risk-first: Wi-Fi/TLS (Spike 6), then git push (Spike 7), then SD (Spike 3) —
each spike proving one risk before the next layer was committed to.

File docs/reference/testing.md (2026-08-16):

# Testing conventions

> How Rust tests are laid out across the host-testable crates (`editor`,
> `keymap`, `display`). All of these build and run off the xtensa target —
> the firmware itself is exercised on hardware, not `cargo test`.
>
> Project overview: [`../README.md`](../../README.md) · doc index:
> [`README.md`](../README.md).

## Two shapes, chosen by what the test exercises

**Unit tests live in the source file.** A `#[cfg(test)] mod tests` block at the
bottom of the `.rs` file. It compiles only under `cargo test` (zero cost in the
shipped binary — which matters on a 16 MB part), and it gets private access to
the module it sits in. This is the default. `keymap/src/lib.rs` is the worked
example: 28 tests inline under the decoder they cover.

**Behavioural tests live in a `src/tests/` submodule.** When a test drives the
_whole_ `Editor` through `Key` events and asserts on private state — rather than
calling one function in isolation — it isn't really a unit test of any single
module. Those go in a `#[cfg(test)] mod tests;` **directory**, one file per
theme. The `editor` crate is laid out this way.

## The `editor` crate's `src/tests/`

- [``](../../editor/src/tests/) is the sole `#[cfg(test)] mod tests;`
  (declared at the bottom of [`lib.rs`](../../editor/src/lib.rs)). It holds **every
  shared helper** (`typed`, `command`, `kinds`, `over`, `palette_editor`, …) and
  the fixture consts, and it re-exports the crate root with
  `pub(crate) use crate::*;` so each theme file reaches `Editor`, `Key`,
  `Effect`, … through a single `use super::*;`.
- Each theme file (`editing.rs`, `visual.rs`, `palette.rs`, `search.rs`, …) is
  just `#[test]` fns plus that one `use super::*;`. No file re-imports the crate
  root directly.

Adding a test:

1. Put it in the theme file matching the surface it exercises. A test that spans
   surfaces (e.g. edit → format → push) goes with its _primary_ intent.
2. Need a helper used by more than one theme? Add it to `mod.rs`. A helper used
   by a single theme may stay in that theme file.
3. New theme? Add `mod <name>;` to `mod.rs` and a `//!` one-liner to the file.

## What we deliberately don't use

- **The top-level `tests/` integration directory.** That dir only sees a
  crate's public API. The editor's tests read private state (`e.text`,
  `e.caret`, `e.mode()`), so they must stay in-crate under `#[cfg(test)]`.
  Reach for `tests/` only to pin a crate's _public_ contract.
- **Doctests** for the embedded core. Fine for documenting a public API, but
  slow and awkward here; the behaviour is covered by the tests above.

## Running them

No cargo workspace ties the crates together, so run per crate from its own
directory:

```sh
cd editor && cargo test     # 224 tests
cd keymap && cargo test     # 28 tests
```

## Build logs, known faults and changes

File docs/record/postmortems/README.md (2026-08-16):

# Postmortems

> Bench + bring-up debugging write-ups: what broke, how we found the root cause,
> and the decisions that came out of it. One file per incident, named
> `YYYY-MM-DD-<slug>.md`. These capture _why_ a spike stalled or a design turned
> — the kind of context that's expensive to reconstruct later.
>
> Project overview: [`../../README.md`](../../../README.md). Bring-up spikes:
> [`firmware/docs/bring-up-spikes.md`](../../../firmware/docs/bring-up-spikes.md).

| Date | Incident | Status |
| --- | --- | --- |
| 2026-07-05 | [Spike 3 (SD) — card rejects CMD59 (SPI-mode CRC)](2026-07-05-spike3-sd-cmd59.md) | Paused — awaiting a compliant microSD; wiring + firmware proven |
| 2026-07-05 | [Spike 7 (git push) — ADR-004 kill-switch fired: gix can't push over HTTPS](2026-07-05-spike7-gix-https-push.md) | Turned — pivoted to libgit2; git mechanics proven on desktop, device build next |
| 2026-07-11 | [Editor freeze — SPI-DMA OOM during a background `:sync`](2026-07-11-editor-freeze-spi-dma-oom-during-sync.md) | Safety net shipped (paints non-fatal); root-cause eradication specced, not yet built |
| 2026-07-16 | [Display "buffer toggling" — partial refresh left one RAM bank two frames stale](2026-07-16-partial-refresh-bank-toggle.md) | Fixed + verified on device — band re-written to both banks post-refresh (ping-pong) |
| 2026-07-16 | [Gate-scan restriction spike — refuted: partial waveform time is MUX-independent](2026-07-16-gate-scan-spike-refuted.md) | Closed, negative result — never write `0x01`/`0x0F`; custom LUT is the only lever left |
| 2026-07-20 | [Onboarding wizard Wi-Fi bring-up boot loop (LoadProhibited)](2026-07-20-wizard-wifi-loadprohibited.md) | Fixed and verified on device — a size-opt Xtensa miscompile; `wizard_io::run` is pinned to opt-level 2 |

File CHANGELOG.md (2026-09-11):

# Typoena changelog

The Typoena firmware, release by release, newest first. Your device updates
itself over Wi-Fi — run `:update` to pull the latest build. The macOS setup
tool (the installer) is versioned separately and listed at the end.

_Generated from the commit history with [git-cliff](https://git-cliff.org)._

## Firmware

### [0.14.0] — 2026-09-06
#### Added
- **editor:** Add :link to write a markdown link from the file pick
- **editor:** Select a written link's title so typing replaces it

### [0.13.1] — 2026-09-06
#### Fixed
- **render:** Full-refresh a file switch so the outgoing note stops ghosting

### [0.13.0] — 2026-09-06
#### Added
- **palette:** Drop the repo/ prefix from the file list

#### Fixed
- **prefs:** Apply the preferences a pull brought in
- **prefs:** Let a wildcard hidden folder be named in the palette
- **sync:** Commit drift the journal missed instead of refusing every pull

### [0.12.1] — 2026-09-06
#### Fixed
- **flash:** Pick the bootloader from this build, not the oldest hash
- **palette:** Find commands by their : name, not just their label

### [0.12.0] — 2026-09-06
#### Added
- **hud:** Say which operation is running, not just that one is
- **palette:** List about next to help in the > commands
- **ota:** Warn on the splash while a new image is unconfirmed

#### Fixed
- **ota:** Report why an update failed instead of a progress line

### [0.11.0] — 2026-09-05
#### Added
- **prefs:** Hide folders from the device with hidden_folders
- **prefs:** Match hidden folders by prefix, with exceptions
- **inbox:** Date a fleeting note over SNTP alone, never a pull
- **logging:** Mirror warn+ logs to the SD card

#### Fixed
- **sync:** Observe net outcomes while the writer types
- **sync:** Scope the idle-save hold-off and expire it on silence
- **prefs:** Filter hidden folders in one place, not two
- **net:** Let the clock-only sync give the radio back
- **sd:** Bound libgit2's open packs, close the TLS fd leak, instrument load failures
- **logging:** Keep card records during a flush, drop the dead mute

### [0.10.0] — 2026-09-05
#### Added
- **hardware:** Add routed mainboard PCB with gerbers
- **tooling:** Enforce trailing newline on saved files
- **editor:** Terminate formatted buffer with trailing newline
- **sync:** List unsynced saves on :gl with commit or discard
- **palette:** Jump half a card on Ctrl-d/Ctrl-u
- **sync:** Report real push and pull phases on the panel
- **hardware:** Add mainboard v2 schematic — single-board PCBA with power management
- **pcb:** Import and place all 98 footprints
- **pcb:** Route the mainboard and add the design checker
- **pcb:** Generate the fabrication outputs from a script
- **pcb:** Ready the dev board for fabrication
- **pcb:** Cost-optimize the dev board for JLCPCB
- **palette:** List the fleeting-note commands in the > palette
- **help:** Add a paged :help command reference card

#### Fixed
- **editor:** Terminate buffer on Cmd+S mid-Insert without reflowing
- **pcb:** Align the 5V feedback divider across schematic, BOM and notes
- **pcb:** Tighten the pulsed-current loops
- **pcb:** Clear the silkscreen collisions and the In2.Cu ground zone
- **pcb:** Reroute around the relocated J5 and stitch the loose ground
- **pcb:** Move the 5V feedback divider off the discontinued 68k
- **pcb:** Turn the VBUS TVS the right way round on both boards

### [0.9.0] — 2026-08-01
#### Added
- **app:** Paint a publishing clue before the card-wide retarget

#### Fixed
- **editor:** Commit the Ctrl+Tab walk on Ctrl release

### [0.8.0] — 2026-08-01
#### Added
- **changelog:** Auto-generate CHANGELOG.md from commits with git-cliff
- **editor:** Add :pub/:publish to mark a note .pub.md
- **wizard:** Erase and dedicate a bring-your-own card on consent
- **firmware:** Fast partial waveform experiment (0x32 custom LUT)
- **firmware:** Swap in real Good Display GDEY0579T93 partial waveform
- **firmware:** Trim fast partial LUT — drop weakest tail phase per group
- **firmware:** Fast partial FR 0x04->0x08 — 420ms -> 266ms, solid black
- **firmware:** Keep-hot charge-pump experiment + re-scope validated comments
- **display:** Simplify boot splash to a lowercase wordmark
- **app:** Clear panel ghosting with scheduled full refreshes
- **editor:** Show friendlier filenames in the panel and palette
- **editor:** Open the command palette with Cmd+Shift+P
- **display:** Bake alternate mono font families into MonoFont atlases
- **editor:** Choose the writing font family from the settings palette
- **editor:** Group the side panel into file, sync and vim tiers
- **companion:** Typo the tucano — splash, panel face, moods, milestones
- **editor:** Show the sync scope flag only for Local buffers
- **fonts:** Add Courier Prime, IBM Plex Mono, Space Mono, Hack
- **companion:** Wobble Typo on each reveal, stay neutral on boot
- **companion:** Rebake Typo crisp at 96px with bolder moods
- **editor:** Add a face pref (default random) with a humor shuffle bag
- **companion:** Rotate Typo's rest face into the humors, and fix the fade
- **palette:** List the full card on an empty query
- **palette:** Say "reading card..." while the boot walk runs
- **palette:** Add a fast partial toggle for live bench A/B
- **firmware:** Trap integer overflow in release builds
- **firmware:** Panic scribe — dump the dirty buffer before the reboot
- **palette:** Title-typed new files and scoped folder suggestions
- **editor:** Add local link palette command
- **editor:** Ctrl+Tab walks recently-opened notes
- **editor:** Gf follows the markdown link under the caret
- **editor:** Gs/gl push and pull from Normal mode
- **editor:** Retarget links card-wide when :pub renames a file
- **editor:** Rename the :gp push command to :gs

#### Changed
- **firmware:** Pin the file-walk to Core1 so it can't starve the UI
- **render:** Shorten deep-idle full-refresh to 10s

#### Fixed
- **build:** Compile firmware at opt-level 2 to dodge Xtensa miscompile
- **editor:** Keep the caret column across format-on-save
- **epd:** Launder fast-partial residue with a boot-grade clean pass
- **epd:** Evict the resident fast-partial recipe before factory partials
- **epd:** Evict the fast recipe before RAM writes, not mid-refresh
- **editor:** Make Ctrl+W follow Vim word-class boundaries
- **editor:** Keep typed input out of the side panel
- **app:** Repaint stale NO KBD flag after boot-time attach

### [0.7.9] — 2026-07-19
#### Added
- **editor:** Add :about splash and name the active file in the panel
- **ota:** Name the running version in the up-to-date notice

### [0.7.7] — 2026-07-19
#### Added
- **reboot:** Add :reboot command with auto-save and restart screen
- **delete:** Add :d alias and a y/n confirmation guard
- **reboot:** Confirm :reboot and :setup with the y/n guard
- **wizard:** Require typing the repo name to confirm a repo switch
- **inbox:** Add :inbox and :oldest fleeting-note commands
- **palette:** Prefill folder and Tab-complete the new-file name
- **firmware:** Add demo + kbd bench bins on a shared panel engine
- **conf:** Complete a bare repo name with the GitHub user
- **sync:** Fold unpublished saves into a commit on :gl behind a confirm
- **firmware:** Over-the-air firmware update via :update

#### Fixed
- **firmware:** Fire unbaked-config warning on full builds

### [0.7.5] — 2026-07-17
#### Added
- **boot:** Async splash refresh + background palette file walk
- **editor:** Make / search case-insensitive
- **editor:** Smartcase + accent-folded search
- **editor:** Rename :sync to :gp
- **sync:** Skip media paths in the pull apply
- **editor:** Open the Cmd-P palette from every mode
- **editor:** Add open_last_on_boot pref with palette toggle
- **firmware:** Boot into the last-active file
- **editor:** Let a palette-query space match any separator
- **editor:** Continue blockquote markers on Enter
- **git-sync:** Rebase local work onto origin on :gl divergence
- **conf:** Extract the typoena.conf schema into a shared crate
- **firmware:** Read typoena.conf from the card at boot
- **wizard:** The onboarding wizard's step/field state machine
- **firmware:** First-boot wizard gate + Wi-Fi step on device
- **wizard:** Land the GitHub device-flow sign-in step
- **wizard,firmware:** On-device GitHub sign-in with a QR on the panel
- **wizard:** Show Wi-Fi password by default, Tab to hide
- **wizard:** Pick the Wi-Fi SSID from a device scan
- **wizard:** List the installation's repos on the device
- **wizard:** Shallow-clone the chosen repo on the device
- **wizard:** Add reset-mode menu for :setup re-entry
- **setup:** Wire :setup to reboot into the onboarding wizard
- **persistence:** Add FAT-safe recursive delete + factory_reset
- **setup:** Factory reset from the :setup reset menu
- **persistence:** Add wipe_repo for the :setup repo switch
- **setup:** Repo switch from the :setup reset menu
- **editor:** Cmd+S saves from any mode, dirty-guarded
- **editor:** Scroll_margin pref keeps caret context (vim scrolloff)
- **editor:** Rotate scroll_margin from the > palette
- **epd:** Add experimental partial-refresh temperature knob
- **focus:** Silent-timer Pomodoro with a masking rest curtain

#### Changed
- **palette:** Intern the file list into one PSRAM blob
- **sync:** Reuse the TLS session and skip the pull's needless fetch
- **epd:** Raise SPI clock to 20 MHz, close dead latency levers
- **epd:** Drop set_ram_area settle delay (was a full FreeRTOS tick)
- **boot:** Cut cold boot 4159→3239 ms (memtest off, 240 MHz)

#### Fixed
- **sync:** Apply the pull fast-forward as a tree diff, not checkout_tree
- **firmware:** Resume wizard from card state, not baked config
- **wizard:** Pre-spawn the clone worker before Wi-Fi to avoid ENOMEM
- **wizard:** Install TLS trust store and retry the clone cleanly
- **wizard:** Wrap the size-gate refusal so it doesn't clip off-panel
- No more panel going back and forth when typing

### [0.7.0] — 2026-07-13
#### Added
- Add glyphs
- **persistence:** Add mount_for_git with a larger open-file budget
- **sync:** Commit by splicing journaled dirty paths onto HEAD
- **palette:** Walk the card recursively for the file list
- **palette:** Show recents only until the query reaches two chars
- Wrap palette selection; fix push classing, file walk, card load
- **editor:** / forward search with n/N repeat (v0.7)
- **sync:** :gl pull — fetch + fast-forward only on the git thread

#### Changed
- **sync:** Instrument and benchmark commit-staging latency
- **git:** Cache emulated pack mmap to avoid re-reading the pack
- **sync:** Bench the index-free commit path and mmap cache
- **sync:** Enable FatFS fast seek for pack reads
- **sync:** Cache small pack windows and evict mmap cache on munmap
- **palette:** Trust dirent d_type instead of a per-entry stat

#### Fixed
- **sync:** Patch the mbedtls stream double-free that reset the chip
- **sync:** Move mbedTLS allocations to PSRAM
- **sync:** Survive push heap exhaustion and instrument the push path
- **sync:** Budget mmaps at 64KB/1.5MB, trace the push heap live

### [0.6.0] — 2026-07-12
#### Added
- **editor:** Add theme and auto_sync preset prefs with rotate-on-Enter
- **editor:** Add snippet library, tab-stop engine, and $ palette
- **editor:** Hint the matching snippet in the panel on typing pause
- **editor:** Generalise the > palette into a command registry
- **firmware:** Read .typoena.snippets.json at boot into set_snippets

#### Fixed
- **persistence:** Show a saved note's trailing newline as an empty line

### [0.5.0] — 2026-07-11
#### Added
- Add multi-file buffer foundation (v0.5 slice 1)
- **editor:** Add v0.5 file palette (Cmd-P) with fuzzy match
- **editor:** Add :enew and :delete with real git-staging (v0.5 slice 3)
- **persistence:** End saved files with a trailing newline
- **editor:** Add .typoena.toml prefs and palette settings (v0.5 slice 4)

### [0.1.0] — 2026-07-11
#### Added
- **firmware:** Blink on-board WS2812 alongside GPIO 2
- **firmware:** Drive GDEY0579T93 EPD via dual-SSD1683 driver
- **firmware:** Read keycodes from a USB HID boot keyboard
- **firmware:** Add partial refresh to the EPD driver
- **firmware:** Type on the e-paper panel with partial refresh
- **firmware:** Add vim text objects and the change operator
- **firmware:** Add Wi-Fi + TLS spike (Spike 6)
- **editor:** Use ISO-8859-15 font for accented glyphs
- **firmware:** Add SD/FAT spike (Spike 3)
- **firmware:** Enable octal PSRAM
- **firmware:** Vendor libgit2 v1.9.4 as a git submodule
- **firmware:** Add libgit2 esp-idf component (CMake + mbedTLS shims)
- **firmware:** Wire libgit2 component + bind git2 in system mode
- **firmware:** Add flash-FAT storage partition table
- **firmware:** Bake and document git push env vars
- **firmware:** Add on-device git push spike (git_push)
- **firmware:** Verify git-push TLS chain against embedded GitHub CAs
- **firmware:** Add persistent-clone git sync spike (git_sync)
- **firmware:** Add RECLONE_EACH_BOOT toggle to git_sync
- **editor:** Add Markdown affordances and a :fmt formatter
- **usb:** Track keyboard connection state
- **editor:** Split display into writing column and side panel
- **editor:** Put the mode indicator at the side-panel bottom-left
- **keymap:** Extract pure HID decode into host-testable crate
- **keymap:** Add US-International dead-key accent composer
- **wifi:** Retry association with backoff in shared connect helper
- **usb-kbd:** Compose dead-key accents before enqueuing keys
- **keymap:** Repurpose the physical Esc key to type backtick/tilde
- **editor:** Add :w/:sync commands as host save/publish effects
- **sd:** Reformat a fresh card on mount failure in the spike
- **sd:** Move the SD spike to its own SPI3 host
- **persistence:** Add SD mount + atomic save/load module
- **editor:** Add text() getter and with_text seed constructor
- **firmware:** Boot-load and save the note via persistence
- **firmware:** Gate :sync publish behind the git feature
- **editor:** Boot in Normal mode and add a panel snackbar
- **firmware:** Post loaded/saved snackbars to the panel
- **firmware:** Wire SD persistence + git publish into the editor
- **firmware:** Log per-phase :sync timing breakdown
- **keymap,editor:** Add Ctrl-d/u half-page scroll
- **editor:** Absolute line-number gutter
- **editor:** Edit the : command line with Ctrl-W / Cmd-Backspace
- **editor,firmware:** Add :gl fast-forward pull command
- **editor:** Format the buffer on save/sync (format_on_save)
- **keymap:** Add Ctrl-r redo intent
- **editor:** Add v0.3 editing — register, undo/redo, and dot-repeat
- **editor:** Add Visual mode (v/V) with y/d/c, move View to gr

#### Changed
- **firmware:** Window partial refresh to the edited rows
- **firmware:** Optimistic :sync — push first, reconcile only on reject

#### Fixed
- Save to local for the mvp 0.1
- **firmware:** Raise main task stack to 96 KB for libgit2 depth
- **libgit2:** Make the loose ODB persist on FATFS via POSIX shims
- **firmware:** Recover git_sync from a leftover clone dir
- **libgit2:** Create objects writable so FAT can delete them
- **firmware:** Delete repo dir via path-based recursion, not remove_dir_all
- **usb-kbd:** Quiesce in-flight transfer before free; guard hot-plug leaks
- **editor:** Make the buffer UTF-8-correct for accented input
- **sd:** Unlink target before f_rename to overwrite on FAT
- **sd:** Correct stale shared-bus log strings to SPI3
- **firmware:** Harden :sync publish — skip macOS sidecars, fast-forward first
- **firmware:** Keep the editor alive when a panel paint fails
- **editor:** Reveal the pasted block when it runs past the fold

## Installer

The macOS setup tool that prepares an SD card — install it with
`curl -fsSL https://typoena.dev/install.sh | sh`.

### [0.5.0] — 2026-07-19
#### Added
- Frame the header as the device's e-ink screen
- Add --wipe card-reformat TUI
- Make just wipe headless with --no-eject
- Complete a bare repo name against the GitHub user
- Fill the GitHub username from the ^G sign-in

### [0.4.0] — 2026-07-15
#### Added
- Proactive repo-access check at Configure

### [0.3.1] — 2026-07-15
#### Added
- Explain the app-install 403 on clone

### [0.3.0] — 2026-07-15
#### Added
- Sign in with GitHub replaces hand-created PATs
- Accept remote-URL shorthand

### [0.2.2] — 2026-07-15
#### Added
- Slow the header typewriter to 150ms per key

### [0.2.1] — 2026-07-15
#### Added
- Center the header and type both lines with one caret
- Jump a whole step with Ctrl-N / Ctrl-P

### [0.2.0] — 2026-07-15
#### Added
- Run blocking scans off the UI thread with a spinner
- Animate the typoena header with a typewriter intro

#### Fixed
- Stop subprocess output corrupting the TUI

### [0.1.1] — 2026-07-15
#### Added
- Improve wizard UX (nav, progress, wifi, cards)

### [0.1.0] — 2026-07-14
#### Added
- Self-contained macOS SD-card setup CLI

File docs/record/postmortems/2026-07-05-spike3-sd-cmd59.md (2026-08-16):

# Spike 3 (SD) — blocked on a card that rejects CMD59 (SPI-mode CRC)

> Date: 2026-07-05 · Build at time of failure: `07-05 16:07Z @f77f669-dirty`
> Status: **RESOLVED 2026-07-11** — a genuine 32 GB SDHC card mounts, negotiates
> 10 MHz, and round-trips cleanly on the shared SPI2 bus. Wiring and firmware
> were always good; the 133 GB SDXC card's CMD59 rejection was the sole fault.
> See [Resolution](#resolution-2026-07-11) below.
>
> Context: Spike 3 in the
> [spike log](../../../firmware/docs/bring-up-spikes.md),
> storage split [ADR-007](../../adr.md#adr-007-storage-split--fat-on-sd-for-working-copy-littlefs-on-flash-for-config),
> firmware notes [`../../firmware/docs/bring-up-spikes.md`](../../../firmware/docs/bring-up-spikes.md).
> Spike program: [`sd_bench.rs`](../../../firmware/src/bin/sd_bench.rs).

## Resolution (2026-07-11)

Re-ran `sd_fat` with a genuine 32 GB SDHC card (build `07-11 08:53Z
@195311a-dirty`). Everything the paused write predicted held:

- `sdspi_host: data CRC set=1` — **CMD59 now succeeds**. Init runs clean through
  card identification (`sdmmc_card_init: card type is SD`).
- `card mounted at /sd — max 10000 kHz, negotiated 10000 kHz`.
- `FAT usage — 29806 MiB total, 29802 MiB free` (~29.8 GiB of the 32 GB card).
- `round-trip OK — 92 bytes: create …tmp → fsync → rename → read back identical`.

Wiring, pull-ups, bus sharing, and the hand-rolled FFI mount path all confirmed
correct — the only variable that changed was the card, exactly as diagnosed. The
`cmd=52` / `cmd=5` "command not supported" lines still print and are still
normal (SDIO probes a memory card ignores).

### New finding: FatFS `f_rename` does not overwrite (atomic-save is not POSIX)

The first run created `/sd/spike3.md`; the **second** run failed at `rename tmp
-> final` with `File exists (os error 17)`. Root cause is a FatFS semantics
difference, not a fault: **`f_rename` returns `FR_EXIST` when the destination
already exists** — unlike POSIX `rename(2)`, which atomically replaces it. So the
textbook write-`*.tmp` → rename-over-target idiom from ADR-007 does **not** work
as-is on FAT; the destination must be unlinked first.

That unlink opens a crash window: between `f_unlink(target)` and `f_rename`, the
target is momentarily gone while `*.tmp` holds the complete, fsync'd new content.
The consequence for the real persistence module is a **boot-recovery** rule for a
lingering `*.tmp`. Implementing it (`firmware::persistence::Storage::recover`)
surfaced that "promote the tmp" is too blunt: a crash _during_ the tmp write (a
second window, before the fsync) leaves a **partial** tmp, so recovery must look
at whether the target survived —

- **tmp + target both present** → crash point ambiguous, tmp may be partial →
  keep the committed target, discard the tmp (the "previous version" guarantee);
- **tmp only, target absent** → target was already unlinked → tmp is the newest
  complete copy → promote it.

The spike now does unlink-then-rename and tolerates a missing target, so re-runs
are idempotent; recorded in
[ADR-007](../../adr.md#adr-007-storage-split--fat-on-sd-for-working-copy-littlefs-on-flash-for-config).

## Summary

Built the Spike 3 bench program (`sd_fat`): bring up the SD card over the EPD's
shared SPI2 bus, mount FAT, and prove the persistence module's atomic-save
pattern (write `*.tmp` → fsync → rename → read-back). The card **never mounts**:
SD init gets cleanly through CMD0 and CMD8 (the card even identifies as an
SDHC/SDXC v2 card), then fails at **CMD59 (CRC_ON_OFF)**, which the card rejects
as an illegal command (`ESP_ERR_NOT_SUPPORTED`, `0x106`). `sdmmc_card_init`
treats that as fatal.

Root cause is the **card**, not our wiring or code: the bench card is a 133 GB
SDXC that doesn't implement CMD59 in SPI mode — common on large / cheap /
counterfeit SDXC cards. It works fine on the Mac because macOS uses native SD
mode, never the SPI fallback the ESP32 uses.

**Decision:** keep CRC required (don't disable it to limp the bad card along —
see below) and reject incompatible cards with a clear message. Resume when a
genuine ≤32 GB card is on the bench.

## Bench wiring (shared SPI2, proven good)

| Signal | GPIO | Shared with EPD? |
| --- | ---- | --- |
| SCK | 12 | yes (epd.rs) |
| MOSI | 11 | yes (epd.rs) |
| MISO | 13 | **no** — new line; the EPD is write-only and never used MISO |
| SD CS  | 10 | no — EPD CS is 7 |

The SD sits on the same SPI2 bus as the panel, on its own chip-select. The spike
runs **SD-only** (see "EPD bus lock" below).

## Timeline

1. First flash → `sdmmc_send_cmd_crc_on_off returned 0x106`, `sdmmc_card_init
failed (0x106)`. Cryptic; could be wiring, pull-ups, speed, or card.
2. Added internal pull-ups on SCK/MOSI/MISO/CS and drove the EPD CS (GPIO 7)
   high (deselect the panel on the shared bus). **No change** — identical
   failure at the same command. A deterministic failure at one command argues
   against marginal signal integrity.
3. Verified the card on the Mac: `Windows_FAT_32 TYPOENA`, 33.6 GB partition on
   a 133 GB card, **healthy and readable**. Rules out a dead card / wrong FS.
4. Read the esp-idf SD init source: the CMD8 handler _tolerates_ the
   same `ESP_ERR_NOT_SUPPORTED` (treats it as "not a v2 card"), while CMD59's
   does not. So the failure might be a persistent bad response, not a CMD59
   one-off — needed the raw R1 bytes to tell.
5. Raised the compile-time log ceiling (`CONFIG_LOG_MAXIMUM_LEVEL_DEBUG`) and
   bumped the `sdmmc_*` / `sdspi_*` tags to DEBUG at runtime. The dump was
   decisive:
   - `cmd=52` / `cmd=5` fail (`0x107`/`0x106`) — **normal**: those are SDIO
     probes (CMD52/CMD5) a memory card doesn't answer.
   - `sdmmc_sd: SDHC/SDXC card` — printed **only when CMD8 succeeds**. So CMD0
     and CMD8 returned clean, correct responses (right 0xAA echo, no error bit).
   - `cmd=59, R1 response: command not supported` — only CMD59 is rejected.
6. Confirmed the breakout is a bare microSD→pin adapter (no level shifter), so
   the 3.3 V SPI path is clean.

## Root cause

The card responds correctly to CMD0 and CMD8 (proving wiring, signal integrity,
pull-ups, bus sharing, and the hand-built FFI mount path are all correct) but
**rejects CMD59 (CRC_ON_OFF) as an illegal command**. CMD59 is mandatory per the
SD spec; some large/counterfeit SDXC cards don't implement it in SPI mode. Since
esp-idf's `sdmmc_init_spi_crc` hard-fails when CMD59 fails (and there is **no**
Kconfig or host flag to skip it), the mount aborts.

## What it was _not_

- **Not wiring / a swap** — CMD0/CMD8 responses are clean and correct.
- **Not signal integrity** — internal pull-ups changed nothing; failure is
  deterministic at one command; init runs at 400 kHz where the jumpers are fine.
- **Not the filesystem** — failure is at SD _protocol_ init, before any FAT
  access. The card is FAT32 and mounts on the Mac.
- **Not a level-shifter breakout** — it's a bare 3.3 V adapter.
- **Not our FFI** — the hand-rolled `SDSPI_HOST_DEFAULT()` descriptors work; the
  driver reaches and drives the card correctly.

## Decision: keep CRC required, reject bad cards clearly

CMD59's job is to enable **CRC on data transfers**. The only way to mount this
card is to tolerate CMD59 failing, i.e. run with data CRC **off**. For a device
whose entire value is not losing the user's writing, giving up integrity
checking — precisely on the cards that are already the sketchy ones — is the
wrong trade. It would also require patching a vendored esp-idf function that
re-applies on every update.

So `sd_fat` now maps `ESP_ERR_NOT_SUPPORTED` from the mount to an actionable
message ("card rejected CMD59… use a genuine card, ideally ≤32 GB…") instead of
a raw code. This is the behavior the real `persistence` module should carry too:
a bad card at boot should say "swap the SD," not hang on a hex code.

A CRC-off patch remains _possible_ if bench work ever needs this exact card, but
it is explicitly **not recommended** and not applied.

## Other findings worth keeping

- **EPD bus lock forces SD-only (for now).** The EPD driver uses esp-idf-hal's
  `SpiBusDriver`, whose constructor calls `spi_device_acquire_bus(BLOCK)` and
  holds that **exclusive** lock for its whole lifetime (it needs CS held across
  a cmd→data sequence while DC toggles). While held, any other device on SPI2 —
  the SD — blocks. So the EPD and an arbitrated SD device can't both be live on
  one host as things stand. This spike proves the SD stack; the shared-bus
  **arbitration decision** (release/re-acquire around EPD ops, vs. the
  risk-table fallback of giving the SD its own SPI3) is still open and is what a
  follow-up must settle before integration.
- **FatFS long filenames are required.** The atomic-save temp name
  (`notes.md.tmp`, two dots) is not a valid 8.3 name, and FatFS defaults to
  8.3-only. `CONFIG_FATFS_LFN_HEAP=y` is needed by this spike **and** the real
  persistence path.
- **`SDSPI_*_DEFAULT()` macros are bindgen-invisible.** Built the `sdmmc_host_t`
  / `sdspi_device_config_t` descriptors by hand; the `SDMMC_HOST_FLAG_*` values
  are `BIT(n)` macros bindgen can't fold, so they're inlined (`BIT(3)`/`BIT(5)`).
- **Conservative SD clock.** `SD_FREQ_KHZ = 10_000` (vs. the 20 MHz default),
  since the EPD needed 4 MHz on these bench jumpers. Init runs at 400 kHz
  regardless, so this only affects post-init throughput — revisit on a real PCB.
- **Diagnostic technique.** Raising the log ceiling + `esp_log_level_set` to read
  the driver's per-command R1 bytes turned a cryptic error into a one-glance
  root cause. Reusable for any esp-idf init failure.

## Where the end-to-end (clone → SD → edit → push) stands

- **Clone is out-of-band in v0.1** — the dev clones the remote onto the mounted
  SD from a laptop; there is no first-clone on device
  ([ADR-007](../../adr.md#adr-007-storage-split--fat-on-sd-for-working-copy-littlefs-on-flash-for-config),
  technical doc "Provisioning"). The bench card mounts on the Mac, so that step
  is not blocked.
- **Edit → save-to-SD** becomes testable the moment a compliant card mounts
  (Spike 3 + the existing editor's atomic save). Closest milestone.
- **SD → push** needs **Spike 7 (gitoxide over HTTPS+PAT)**, which is unbuilt and
  needs **PSRAM enabled first** (not yet done). Spike 6 (Wi-Fi + TLS) proved the
  network/TLS gate. So the full loop is not testable yet even with a good card.

## Follow-ups

- [x] Re-run with a genuine ≤32 GB card → clean mount + round-trip (2026-07-11).
- [x] Strip the debug logging once green: removed `CONFIG_LOG_MAXIMUM_LEVEL_DEBUG`
      from `sdkconfig.defaults` and the `esp_log_level_set` block in `sd_fat.rs`
      (2026-07-11).
- [x] Write up Spike 3 as verified in
      [`../../firmware/docs/bring-up-spikes.md`](../../../firmware/docs/bring-up-spikes.md) (2026-07-11).
- [x] Record a **recommended-SD-card note** for v0.1 (genuine, ≤32 GB;
      large/counterfeit SDXC may fail CMD59) — in
      [ADR-007](../../adr.md#adr-007-storage-split--fat-on-sd-for-working-copy-littlefs-on-flash-for-config)
      (2026-07-11).
- [x] Enable PSRAM (done, `CONFIG_SPIRAM`) and build Spike 7 (git push) — both
      complete; see [Spike 7 postmortem](2026-07-05-spike7-gix-https-push.md).
- [x] Settle the **shared-bus arbitration** decision → **SD on its own SPI3**
      (ADR-012, 2026-07-11); spike rewired to SPI3 (SCK 14 / MOSI 15) and
      **re-verified on hardware 2026-07-11** — same mount + round-trip result.
- [ ] **Still open:** implement the FatFS atomic-save (unlink-then-rename +
      `*.tmp` boot-recovery) in the real `persistence` module — → tracked as
      the crash-safe-writes item in [v0.9 robustness](../../plan/macroplan.md#v09--robustness--).

## Artifacts (this session)

- `firmware/src/bin/sd_fat.rs` — the spike (mount + atomic round-trip + clear
  rejection + debug logging).
- `firmware/Cargo.toml` — `[[bin]] sd_fat`.
- `firmware/justfile` — `build-sd` / `flash-sd` / `monitor-sd`.
- `firmware/sdkconfig.defaults` — `CONFIG_FATFS_LFN_HEAP=y` (keep) and
  `CONFIG_LOG_MAXIMUM_LEVEL_DEBUG=y` (temporary, strip when green).

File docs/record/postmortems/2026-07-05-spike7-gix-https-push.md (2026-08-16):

# Spike 7 (git push) — the ADR-004 kill-switch fired: gix can't push over HTTPS

> Date: 2026-07-05 (on-device push completed 2026-07-06)
> Status: **DONE** — gix ruled out for the push path; pivoted to `libgit2`
> (`git2`), proved the git mechanics on desktop, then landed the full
> `init → commit → push` over mbedTLS HTTPS **on hardware** (2026-07-06). See
> "On-device push COMPLETE" below.
>
> Context: Spike 7 in the
> [spike log](../../../firmware/docs/bring-up-spikes.md),
> git impl [ADR-004](../../adr.md#adr-004-git-implementation--gitoxide-gix), auth
> [ADR-005](../../adr.md#adr-005-auth--https--github-personal-access-token).
> Spike program: [`../../spikes/spike7-git-push/`](../../../spikes/spike7-git-push/README.md).

## Summary

Spike 7 was written as the kill-switch for [ADR-004](../../adr.md): _"the
smart-HTTP path is validated in spike 7 before we commit to integration; if it
fails on the device, we fall back to `libgit2-sys`."_ It never needed a device
to fire. Before writing any gix code, gitoxide's own crate-status doc settles
the question: `gix` has send-pack/receive-pack **plumbing** (report-status,
sideband, delete-refs, atomic pushes) but supports push as a **workflow** only
over `file://` and `ssh://`. **Push over HTTP(S) is not implemented** — push is
still listed under "workflows that still need plumbing." (Clone/fetch, by
contrast, are robust over HTTP(S) — which is why Spike 6's TLS GET passed but
does not carry over to push.)

Because [ADR-005](../../adr.md) fixes auth as **HTTPS + PAT**, `gix` cannot satisfy
the push path today. gix _can_ push over `ssh://`, but that would (a) revisit
ADR-005 and (b) still die on device — gix's SSH transport spawns the external
`ssh` program, which does not exist on the ESP32. So the kill-switch condition
is met at the library level.

**Decision:** take the fallback the risk table already names — `libgit2` via the
[`git2`](https://docs.rs/git2) crate — keeping ADR-005 (HTTPS + PAT) intact.
Proved the full `add → commit → push` sequence on desktop
([`spikes/spike7-git-push`](../../../spikes/spike7-git-push/README.md)).

## Why not the alternatives

| Option | Verdict |
| --- | --- |
| **gix + HTTPS** (as ADR-004 intended) | Blocked — gix has no HTTP(S) push. |
| **gix + SSH push** | gix supports it, but revisits ADR-005 _and_ gix's SSH transport shells out to an `ssh` binary absent on ESP32 → dead on device. |
| **gix-protocol send-pack + custom HTTPS transport** | Pure-Rust, no ADR change, but not smoke-test-sized: hand-wiring send-pack over an mbedtls HTTP transport is real work and unproven upstream. Reconsider only if the libgit2 cross-compile (below) turns out worse. |
| **libgit2 (`git2`)** ← chosen | The ADR's named fallback. Trivial on desktop; the risk becomes the on-device cross-compile. |

## What the desktop spike proves

Run live against a local `file://` bare remote (no credentials), exercising the
exact v0.1 `git` module contract:

- **first commit + push** from an unborn `HEAD` (fresh clone of an empty repo)
  → the commit lands in origin. Message is an ISO-8601 timestamp.
- **nothing to push** → short-circuits when the staged tree matches `HEAD`.
- **divergence** → a second clone advances origin; the first clone's push is
  rejected, `pull --no-edit` merges cleanly (different files), the retry push
  succeeds, and origin ends with a correct two-parent merge commit.

Also confirmed 2026-07-05 against a **real GitHub repo** (`jcalixte/typoena-test`)
over HTTPS with a fine-grained PAT: `committed → push accepted by remote`, the
commit landed on GitHub. So the TLS handshake + PAT auth + smart-HTTP push all
work through libgit2's vendored stack (desktop links `openssl-sys` for TLS). The
one path still unexercised live is a **non-fast-forward rejection over HTTPS**
(the `push_update_reference` callback) — the `file://` transport surfaced that as
a `push()` error instead, and the GitHub push was a clean fast-forward.

Implementation notes that carry into the real module:

- **`git add --all` semantics.** libgit2's `index.add_all(["*"], DEFAULT)` stages
  new + modified + **deleted** paths, unlike a naive `git add .`. v0.5 file-delete
  needs removals to reach the next Push's staged set — this is that behavior.
- **Push rejection is not always a `push()` error.** A non-fast-forward can come
  back as a transport `Err` (local transport did this) _or_ silently via the
  `push_update_reference` callback with a status string while `push()` returns
  `Ok` (the HTTPS/GitHub path). The spike handles both and routes either to the
  pull-and-retry. The callback path is coded for but not yet exercised live.
- **PAT hygiene.** The token is handed only to libgit2's credential callback
  (`Cred::userpass_plaintext`) and never logged — matches ADR-005.

## What it does _not_ prove — the next gate

The risk moved **with** the kill-switch and got harder. ADR-004 chose
gix _specifically to avoid_ libgit2's C cross-compile to xtensa; falling back to
libgit2 re-introduces exactly that. The open question is now:

> Can `libgit2` (`git2` / `libgit2-sys`) cross-compile to
> `xtensa-esp32s3-espidf` and use esp-idf's **mbedtls** as its TLS backend?

`libgit2-sys` vendors libgit2 and, on desktop, pulled `openssl-sys` for TLS —
there is no openssl on esp-idf, so the device build will need libgit2 pointed at
mbedtls (its `MbedTLS` backend) via the esp-idf sysroot, which is unproven. This
is the on-device Spike 7 and it also depends on:

- **PSRAM** (`CONFIG_SPIRAM`) enabled — still off (only ~339 KB internal heap;
  see firmware README / Spike 6 note). libgit2's pack working set needs it.
- **A working SD card** (Spike 3, currently
  [paused on a CMD59-incompatible card](2026-07-05-spike3-sd-cmd59.md)) for the
  `/sd/repo` working copy.

So the full **SD → push** loop is still not testable on hardware; this spike
retired the _library/API_ risk and replaced it with a _cross-compile_ risk to
tackle once PSRAM + SD are unblocked.

## On-device probe — 2026-07-05

Two moves toward the on-device gate, decoupled from the (still-blocked) SD card:

**PSRAM enabled.** `sdkconfig.defaults` gained `CONFIG_SPIRAM=y` +
`CONFIG_SPIRAM_MODE_OCT=y` (the N16R8 is _octal_ PSRAM — quad mode would fail
init) + `CONFIG_SPIRAM_USE_MALLOC=y` (adds PSRAM to the heap so large Rust allocs
land there). Speed left at 40 MHz for a safe first enable. Octal PSRAM uses
GPIO 33–37; the EPD/SD pins (4–13) avoid that range, so no wiring conflict.
**Confirmed on hardware 2026-07-05:** boot log shows `Found 8MB PSRAM device`
(vendor AP, gen-3, 64 Mbit die), `SPI SRAM memory test OK`, and `Adding pool of
8192K of PSRAM memory to heap allocator` — the full 8 MB joins the heap on top of
~372 KB internal DRAM. The editor boots and types normally, so PSRAM broke
nothing. The ~1.5 MB git working-set budget now has headroom.

**libgit2 cross-compile probe.** Added `git2` (default-features off → no
openssl/ssh, isolating the C build from the TLS question) + a throwaway
`git_probe` bin, and built for `xtensa-esp32s3-espidf`. Result reframes the risk
in a _more_ encouraging direction than expected:

- **The C cross-compiles.** `xtensa-esp-elf-gcc` ran on libgit2's sources and
  several files built with `exit status: 0`. The feared "cmake can't target
  xtensa / no toolchain" failure did **not** happen.
- **The wall is missing esp-idf networking headers.** libgit2's core
  `git2_util.h` does `#include <arpa/inet.h>`, and the build died with
  `arpa/inet.h: No such file or directory`. Root cause: `libgit2-sys` builds
  vendored libgit2 as a **standalone `cc` library**, so it never inherits
  esp-idf's include paths — esp-idf's BSD-socket headers (lwIP) live under the
  esp-idf component tree, not the bare toolchain sysroot the `cc` invocation
  used. (`arpa/inet.h` _does_ exist in esp-idf, via lwIP's POSIX compat layer;
  it just wasn't on the `-I` path.)

So the on-device libgit2 question is **not** "impossible," it's "needs esp-idf
integration": get the vendored C build to see esp-idf's lwIP/newlib includes.
Candidate paths, roughly in order of effort:

1. **Inject esp-idf include dirs into the `cc` build** via
   `CFLAGS_xtensa-esp32s3-espidf` (point `-I` at esp-idf's lwIP POSIX-compat
   headers). Cheapest to try; risk is a _cascade_ — `arpa/inet.h` is likely the
   first of several missing headers, and then missing lwIP/pthread symbols at
   final link.
2. **Build libgit2 as a proper esp-idf component** (CMake component pulled into
   the esp-idf build so it inherits all component includes/libs). The "right"
   way; more plumbing, via esp-idf-sys's extra-components mechanism.
3. **Patch/fork `libgit2-sys`** to be esp-idf-aware (read `DEP_ESP_IDF_*` and add
   the include paths). Upstreamable but the most work.

The util-layer `arpa/inet.h` include is unconditional (not gated on the transport
backend), so path 1/2/3 is needed before even a transport-less build links.

### Path 1 attempted — 2026-07-05: confirmed a dead end

Injected esp-idf's lwIP + generated-config include dirs via
`CFLAGS_xtensa_esp32s3_espidf` and rebuilt the probe. `arpa/inet.h` **resolved**
— then the build immediately hit the next wall: `lwipopts.h → sys/ioctl.h: No
such file`, a header from a _different_ esp-idf component (vfs/newlib), not lwIP.
That is the whole problem in one line: **path 1 peels the esp-idf component
include graph one component at a time**, with fragile absolute `-I` paths into
build-output dirs (the config-dir hash even changed between two builds). It does
not converge without effectively reconstructing esp-idf's entire per-component
include environment by hand.

### Decision: go straight to path 2 (libgit2 as an esp-idf component)

Path 2 isn't just the robust include fix — it **solves the TLS backend at the
same time**. libgit2 the C library _does_ support mbedTLS (`USE_HTTPS=mbedTLS`);
only the `libgit2-sys` Rust wrapper lacks it. Building libgit2 as an esp-idf
CMake component lets us (a) inherit every component's includes + link (kills the
cascade) and (b) set `USE_HTTPS=mbedTLS` against esp-idf's own mbedtls — which
would make a **custom Rust subtransport unnecessary**. Two birds. Sketch:

- Add libgit2 via esp-idf-sys's extra-components mechanism (a `components/`
  dir + `CMakeLists.txt` declaring `REQUIRES lwip mbedtls pthread newlib vfs`,
  wrapping libgit2's own CMake with `USE_HTTPS=mbedTLS`, `USE_SSH=OFF`).
- Bind to it from Rust — either `libgit2-sys` in _system_ mode pointing at the
  component-built lib, or hand-rolled bindings for the handful of calls the
  `git` module needs.

This is a real, multi-step chunk (component CMake + bindings + link), not a
flag-flip — scoped as the next work item, gated behind nothing now that PSRAM is
up.

## Follow-ups

- [x] Enable PSRAM (`CONFIG_SPIRAM`) — **done + hardware-verified 2026-07-05**
      (octal, USE_MALLOC): 8 MB detected, memory-tested, added to heap; editor
      still runs.
- [x] On-device Spike 7 libgit2 build — **probed + path 1 attempted 2026-07-05**:
      the C cross-compiles; the include cascade does not converge via CFLAGS
      injection (path 1 dead end). Decision: **path 2** (libgit2 as an esp-idf
      component with `USE_HTTPS=mbedTLS`).
- [x] Path 2: add libgit2 as an esp-idf component — **compiles AND links
      2026-07-05** (Gate A + Gate B). libgit2 1.9.4 built as a component with
      `REQUIRES mbedtls lwip pthread vfs newlib`; the include cascade vanished as
      predicted. mbedTLS wired directly (`GIT_MBEDTLS` + `GIT_SHA1/256_MBEDTLS`).
      A `git_smoke` bin calling `git_libgit2_init/version/shutdown` links clean:
      538 `git_*` functions in the ELF, +514 KB text. See "Path 2 result" below.
- [x] Flash the PSRAM build and confirm the SPIRAM heap region — **done
      2026-07-05**: 8192K pool added to heap, memory test OK.
- [x] Run the desktop spike against a real GitHub test repo — **done 2026-07-05**
      (`jcalixte/typoena-test`, fine-grained PAT): HTTPS handshake + PAT auth +
      push confirmed. Still open: the `push_update_reference` rejection path over
      HTTPS (needs a non-fast-forward against a real remote to trigger it).
- [x] On-device `init → commit → push` over mbedTLS HTTPS — **DONE +
      hardware-verified 2026-07-06** (see "On-device push COMPLETE").
- [x] Revise the `git` module section of the technical doc — **DONE 2026-07-07**
      (commit `2f2f122`): gix → libgit2/git2, transport settled, 96 KB stack,
      persistent-clone flow.
- [x] Real cert trust-store (drop the `certificate_check` bypass) — **DONE +
      hardware-verified 2026-07-06** (commit `2519ed8`; see "Shortcuts — status").
- [x] Settle the product sync transport — **DECIDED 2026-07-06: HTTPS + PAT**
      (on-device libgit2 is HTTPS-only; no libssh2 port).
- [~] Retire the last shortcut: no PAT-in-flash — **decision documented, deferred**
  as [ADR-011](../../adr.md#adr-011-credential-provisioning--how-the-pat-reaches-the-device-and-is-protected-at-rest)
  (open): on-device paste → eFuse-encrypted NVS + a per-device fine-grained PAT.
  Gates the first non-dev distribution; nothing to implement until then.
- [~] Fold the push into the editor's `git` module (persistent clone +
  fast-forward) over HTTPS+PAT — **increment A DONE + hardware-verified
  2026-07-07** (`git_sync.rs`): `clone` + persistent `open` + fast-forward push
  proven on device (`afa61de`), plus **recursive delete on FATFS solved**
  (`8dece73`): the EACCES on wiping a repo dir was `std::fs::remove_dir_all`
  (uses `openat`/`unlinkat`/`fdopendir`, unimplemented in esp-idf's path-based
  FATFS VFS), NOT read-only — a diagnostic walk showed every entry writable
  (`ro=false`). Fix = a path-based `remove_tree`; the `p_open`/`p_creat` shim
  (`39e1155`) stays to keep objects writable. Remaining: **B** = divergence/
  merge path (merge commit on FATFS; low value for a single writer); **C** =
  lift the logic into a reusable `git` module wired to the editor's `Ctrl-G`.
  Storage caveat: the real notes repo is 3.9 GB / 562 MiB pack — needs
  shallow+sparse or a dedicated small repo (ADR-007), can't clone whole.
- [x] Move git to a dedicated large-stack task so the shared main-task stack (and
      the editor build) can drop back — **DONE + hardware-verified 2026-07-06**.
      `git_push` now runs on its own `std::thread` (`GIT_STACK = 96 KB` via
      `Builder::stack_size`; main joins it), and `CONFIG_ESP_MAIN_TASK_STACK_SIZE`
      dropped 98304 → **12288** (the Spike-6 value proven with the editor +
      TLS-on-main). On-device push succeeded off-main — no panic/overflow, no
      ENOMEM on the spawn — retiring the "time()-only-works-on-main" misdiagnosis.

## Path 2 result — libgit2 compiles and links on xtensa (Gate A + Gate B)

The bet paid off. libgit2 **1.9.4** (the exact version `libgit2-sys 0.18.5`
vendors, chosen so `git2`'s safe Rust API can bind it in system mode later)
builds as an esp-idf component and links into a real image.

**Why a component beat Path 1.** Registering libgit2 with
`REQUIRES mbedtls lwip pthread vfs newlib` makes it inherit those components'
include + link graph. Path 1's manual CFLAGS injection died because resolving
one component's headers exposes the next (`arpa/inet.h` → `sys/ioctl.h` → …).
The component model walks that graph for us — the cascade never appeared.

**mbedTLS, not OpenSSL.** The libgit2-sys wrapper only offers
openssl/securetransport/winhttp, but the C library has an mbedTLS backend
(`streams/mbedtls.c`, `hash/mbedtls.c`). A hand-written `git2_features.h` selects
`GIT_HTTPS` + `GIT_MBEDTLS` + `GIT_SHA1_MBEDTLS` + `GIT_SHA256_MBEDTLS`, so TLS
and hashing reuse the mbedtls esp-idf already ships (and Spike 6 validated).

**The port surface was small** — four shims, libgit2 sources untouched (so we
never fork 1.9.4):

| Gap on esp-idf (picolibc + VFS) | Shim |
| --- | --- |
| no top-level `<poll.h>` (only `<sys/poll.h>`) | forwarding `poll.h` on the include path |
| `lstat` absent (no symlinks) | `#define lstat stat`, force-included via `esp_port.h` |
| `<sys/mman.h>` absent | `esp_map.c` — `p_mmap` via `git__malloc` + `read` (pack pages land in PSRAM) |
| `getuid`/`geteuid`/`getgid`/`getppid`/`getpgid`/`getsid`/`getpwuid_r`/`readlink`/`utimes` declared but not implemented | `esp_stubs.c` — single-root-user, no-user-db, no-symlink answers |

Also: gcc 14 promoted `-Wimplicit-function-declaration` /
`-Wincompatible-pointer-types` to hard errors; this pre-gcc14 C trips them
benignly, so the component downgrades them to warnings. `unix/process.c`
(fork/`sys/wait.h`) is excluded — only the SSH-exec transport we don't enable
uses it.

**Verification.** A throwaway `git_smoke` bin (`git_libgit2_init` /
`_version` / `_shutdown` via three hand externs) links with **zero undefined
references**: `nm` shows **538 `git_*` text symbols** in the ELF (`git_index_*`,
`git_repository_*`, `git_commit_*`, `git_remote_*`), the four shims present,
+514 KB `.text` (negligible against 16 MB flash).

**Gate C — RAN ON HARDWARE 2026-07-05.** Flashed `git_smoke` to the S3; the
linked library reports `1.9.4`, `git_libgit2_init() -> 1` (global init ran —
registers the mbedTLS stream + HTTP transport + hash backends),
`git_libgit2_shutdown() -> 0`, clean. No crash/assert/hang. So libgit2 +
mbedTLS **compiles, links, and executes** on the ESP32-S3 — the full Path 2
de-risk. Still unproven: an actual `repository_init` → `commit` → `push` over
mbedTLS HTTPS (needs Wi-Fi/SNTP from Spike 6 + a working-copy location).

**Build mechanics learned.** The component is wired via
`[[package.metadata.esp-idf-sys.extra_components]]` `component_dirs`, pointed at
on-disk source through a `LIBGIT2_SRC` env var (probe stage — not yet vendored).
esp-idf-sys emits no `rerun-if-*`, so editing the _root_ Cargo.toml or the
component doesn't retrigger its build script once it has succeeded; forcing a
reconfigure means `rm -rf target/**/.fingerprint/esp-idf-sys-*` (cheap — the
159 MB cmake cache in the OUT_DIR persists, so only the changed component
recompiles).

**Gate D — `git2` safe-API binding LINKS 2026-07-05.** Replaced the hand
externs with the real path: the `git2` crate (default-features off, so no
openssl-sys/libssh2-sys) bound to our component via `libgit2-sys` in **system
mode** (`LIBGIT2_NO_VENDOR=1`). The trick: we don't want libgit2-sys to build
_or_ link anything — esp-idf already links `liblibgit2.a` inside its component
group (verified in `build.ninja`: `esp-idf/libgit2/liblibgit2.a` sits in the
`libespidf.elf` `LINK_LIBRARIES`, and the group is repeated ~6× so libgit2's
refs to mbedtls/lwip resolve). So a **fake pkg-config with empty `Libs`**
(`firmware/pkgconfig/{libgit2,zlib}.pc`, found via `PKG_CONFIG_LIBDIR` +
`PKG_CONFIG_ALLOW_CROSS=1`) makes both libgit2-sys's and libz-sys's probes
succeed while emitting nothing; the symbols come from the component. `git_smoke`
now uses `git2::Version` + `Oid::hash_object` and links with zero undefined refs
— `nm` confirms `git_odb_hash`, `git_oid_tostr`, `git_error_last`, and
`mbedtls_sha1_starts` all **defined** in the ELF.

**Build gotcha (important):** esp-idf-sys forwards the app's link args only when
its build script reruns, and emits no `rerun-if-*`. After the component set
changes, the forwarded args go stale — `rm -rf
target/**/.fingerprint/esp-idf-sys-*` before building forces a fresh forward
(that was why the first git2 link failed with undefined `git_*`).

**Build-gating done:** `git2` is an optional dep behind the `git` feature, and
`git_smoke` has `required-features = ["git"]`, so the editor build never pulls
libgit2-sys/pkg-config. The component's CMake now registers _empty_ when
`LIBGIT2_SRC` is unset, so `just build` (no env) still works.

**Open decisions before commit** (deliberately not done yet):

1. **Vendoring** — the component points at `~/.cargo`'s unpacked source via
   `LIBGIT2_SRC`; not reproducible. Needs a submodule pinned to `v1.9.4` (or a
   vendored copy). This also lets the `just flash-git` recipe drop the env vars.
2. **Component build burden** — `extra_components` still compiles all ~200
   libgit2 files on a clean build even for the editor (cached after; Rust side
   is already gated). Accept, or gate the C compile too.
3. ~~Runtime (Gate D on HW)~~ — **DONE 2026-07-05.** `just flash-git` on the S3:
   `git2 crate is talking to libgit2 1.9.4`, then `sha1(blob "hello") =
b6fc4c620b67d95f953a5c1c1230aaab5db5a1b0` + "hash matches" — i.e. git2 →
   libgit2 → mbedTLS SHA1 all ran correctly on device. Full chain proven.
4. ~~**The real thing** — `repository_init` → `commit` → `push` over mbedTLS
   HTTPS~~ — **DONE + hardware-verified 2026-07-06** (flash-FAT working copy);
   see "On-device push COMPLETE" below.

## On-device push COMPLETE — 2026-07-06

The real thing runs on hardware. `just flash-git-push` (bin
`firmware/src/bin/git_push.rs`, build `@a15789a`) did the whole loop on the
ESP32-S3 and pushed to GitHub over HTTPS:

```
init OK at /spiflash/wc-1783370910
wrote device.md
staged + tree written
committed to master
origin set; pushing refs/heads/master:refs/heads/device/1783370910
cert-check BYPASSED for github.com
push accepted by remote
✅ Spike 7 complete — pushed master → origin/device/1783370910 over mbedTLS HTTPS
```

Verified from both ends: the device logged `push accepted`, and `git ls-remote
https://github.com/jcalixte/typoena-test.git` independently shows
`refs/heads/device/1783370910` at commit `a96a7996`. So Wi-Fi/SNTP → mount
flash-FAT → `repository_init` → `add_all` → `commit` → smart-HTTP push + pack
upload + PAT auth all work on-device through libgit2 + esp-idf mbedTLS.

**Heap:** started at 8.44 MB free, min-ever **6.85 MB** — the whole TLS handshake

- packfile build cost ~1.6 MB, all served from PSRAM; internal DRAM was never
  stressed. **Timing:** first-boot FATFS format of the working-copy dir ~7.7 s,
  commit sub-second, TLS handshake→accept ~6 s.

### Three bugs stood between "links + runs" and "pushes"

Gate D proved SHA1 on device; getting from there to a real push took three fixes
on the flash-FAT + FATFS path, each found on hardware. All are committed (5
microcommits through `a15789a`).

1. **Main task stack 12 KB → 96 KB.** libgit2 is stack-hungry: nearly every
   function puts a `char path[GIT_PATH_MAX]` (4 KB) buffer on the stack, and the
   `repository_init → config-write → FATFS → wear-leveling` chain nests ~10 of
   them — a _trivial config write_ measured ~67 KB of stack. At 48 KB it
   overflowed and smashed an adjacent newlib lock handle → `LoadProhibited` in
   `xQueueGenericSend`. **This corrected an earlier misdiagnosis:** the "`time()`
   only works on the main task, not a std::thread" conclusion from the first
   on-device attempt was wrong — that thread had the _default 4 KB_ stack, so the
   same deep chain just overflowed sooner. It was always stack depth, not
   thread-vs-main. (This stack has since moved: `sdkconfig.defaults` is shared
   with the editor build, so git was later given its OWN 96 KB `std::thread` and
   the main-task stack dropped back to 12 KB — see the follow-ups. The misdiagnosis
   is now doubly retired: the push runs fine off the main task.)

2. **`p_rename` = remove-then-rename** (`esp_stubs.c`). FATFS `f_rename` fails
   `EEXIST` if the target exists and FAT has no hardlinks, so libgit2's own
   `p_rename` (link-then-rename in `posix.c`) can't overwrite the
   `config`/`refs`/`HEAD`/`index` files its lock→commit sequence depends on. Ours
   drops the target then renames; `posix.c`'s original is compiled under a
   throwaway name via a file-scoped CMake `COMPILE_DEFINITIONS`, so ours is the
   `p_rename` every caller links. (Not crash-atomic, but FAT offers no atomic
   replace — acceptable for the working copy.) Verified on hardware: cleared the
   `failed to rename lockfile to '.git/config'` error.

3. **`utimes` existence-gate — the killer.** This one silently defeated every
   object write. Our first `utimes` stub returned `0` unconditionally ("VFS can't
   set times; ignore"). But libgit2's `git_futils_touch()` → `p_utimes()` is how
   the loose ODB's `freshen` probe answers _"does this object already exist?"_,
   and `git_odb_write()` (`odb.c:1629`) **skips the write entirely** when freshen
   succeeds. So a blanket `return 0` made freshen always report "exists" →
   libgit2 believed every object was already on disk → **every** blob/tree/commit
   write was silently dropped. `.git/objects/` stayed empty (only `info/` +
   `pack/`), and `write_tree` failed with `invalid object specified - device.md`.
   Fix: `stat`-gate the stub — present → `0` (setting the time is a cosmetic
   no-op we skip), absent → `-1`/`ENOENT`, so freshen correctly reports "not
   found" and the real write proceeds.

   Diagnosed with an in-binary A/B/C/D ODB probe — write an in-memory blob, a
   file blob, run `add_all`, then walk `.git/objects` — which showed `exists =
false` for every OID and an empty objects dir, isolating it to the _write_
   path (not read, not mmap, not the index). The vendored `odb.c` /
   `odb_loose.c` / `futils.c` source then pinned it to the freshen→touch→utimes
   chain. **Lesson:** a "harmless" no-op POSIX stub is actively dangerous when a
   caller reads its return value as a semantic signal.

### Shortcuts — status

- **Cert verification — DONE, hardware-verified 2026-07-06 (commit `2519ed8`).**
  Was: `certificate_check` blanket-accepted the peer cert (MITM-open). Now: embed
  GitHub's roots (`firmware/src/bin/github_roots.pem` — USERTrust ECC/RSA +
  DigiCert G2/Global Root CA, extracted from the macOS root store), write them to
  `/spiflash/ca.pem`, and load them via `git2::opts::set_ssl_cert_file`
  (`GIT_OPT_SET_SSL_CERT_LOCATIONS`; `CONFIG_MBEDTLS_FS_IO=y` lets mbedtls fopen
  the file). The callback returns `CertificatePassthrough`, which the transport
  maps to `is_valid ? 0 : -1` (`httpclient.c:805`) → **fail-closed**. The push
  still landed, proving the chain validates against the embedded USERTrust ECC
  root on-device. Caveat: roots must be refreshed if GitHub rotates CAs; a product
  would prefer esp-idf's bundle via a custom subtransport (it can't reach
  libgit2's private mbedtls config without touching libgit2 sources).
- **PAT baked into flash — STILL STANDING** (ADR-005 spike shortcut). `build.rs`
  embeds `TW_PAT` in the git_push/git_sync image via `env!()` — plaintext in
  flash, extractable with `esptool read_flash`. Fine for the dev's bench unit,
  not for a shipped one. The provisioning + at-rest-hardening decision is now
  tracked as an **open** ADR: [ADR-011](../../adr.md#adr-011-credential-provisioning--how-the-pat-reaches-the-device-and-is-protected-at-rest)
  (likely on-device paste → eFuse-encrypted NVS + a per-device fine-grained PAT).
- **Product sync transport — DECIDED 2026-07-06: HTTPS + PAT.** On-device libgit2
  is HTTPS-only (mbedTLS build; no ssh client, libssh2 unported), and the proven
  path is HTTPS+PAT, so the product keeps ADR-005 rather than porting SSH. The
  real project remote (`git@github.com:jcalixte/typewriter.git`, SSH) stays for
  desktop/human use; the device pushes over an HTTPS remote + token (stored
  securely, not in flash). No libssh2 port needed.

## Artifacts (this session)

- `spikes/spike7-git-push/` — the desktop spike crate (`src/main.rs`,
  `Cargo.toml`, `README.md`, `.env.example`).
- `firmware/components/libgit2/` — the esp-idf component (uncommitted probe):
  `CMakeLists.txt`, `git2_features.h`, `poll.h`, `esp_port.h`, `esp_map.c`,
  `esp_stubs.c`.
- `firmware/src/bin/git_smoke.rs` + Cargo.toml `[[bin]]`/`extra_components`
  (uncommitted probe wiring).
- ADR-004 — outcome note appended (kill-switch fired → libgit2).
- `docs/v0.1-mvp-technical.md` — risk-table row updated (gix push → libgit2).

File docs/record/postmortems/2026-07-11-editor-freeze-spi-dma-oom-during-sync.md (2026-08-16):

# Editor freeze — SPI-DMA out-of-memory during a background `:sync`

> Date: 2026-07-11 · Build at time of failure: `07-11 18:02Z @229c259-dirty`
> Status: **Safety net shipped and hardware-verified** (2026-07-13, during the
> [real-repo-sync kaizen](../kaizen/real-repo-sync.md): live scrolling through
> a real-repo push — the run-4 crash was this same paint-during-push family,
> and after the fixes the UI survived every subsequent push, success and
> failure alike). The paint path also **no longer allocates per repaint**
> (persistent two-frame `draw_into`/`swap` in `main.rs`, 2026-07-13), removing
> the frame-buffer half of the paint-time allocation. **Root cause not fully
> eradicated**: the EPD driver's per-refresh internal DMA scratch remains; the
> permanent fix (a persistent scratch buffer in `Epd`) is specced below and
> now tracked in [v0.9 robustness](../../plan/macroplan.md#v09--robustness--).
>
> Context: editor loop [`../../firmware/src/main.rs`](../../../firmware/src/main.rs),
> EPD driver [`screen_epd.rs`](../../../firmware/src/drivers/screen_epd.rs), git
> transport [`net.rs`](../../../firmware/src/infrastructure/net.rs).
> Display medium [ADR-003](../../adr.md#adr-003-display-medium--e-ink-gdey0579t93-panel);
> concurrency model (dedicated git thread) [ADR-006](../../adr.md).

## Summary

First-ever field freeze. After an hour of clean editing, the user ran `:sync`;
the commit and push **succeeded** (`push accepted by remote`, commit
`48a2c0a8`), but partway through the push the panel stopped updating. Keystrokes
kept being logged, so the device wasn't hung — but nothing repainted again.

The editor task had died. A screen refresh that happened to run **while Wi-Fi +
TLS were up for the push** failed to allocate an internal DMA buffer
(`ESP_ERR_NO_MEM`), and that error propagated through a `?` straight out of
`main()`. ESP-IDF's `main_task` returned from `app_main()`; the editor loop lived
on that task, so it stopped. The USB-keyboard and git threads are **separate
FreeRTOS tasks** (ADR-006) and kept running — hence keys still logged while the
panel was frozen. A zombie, not a crash.

## Symptom

```
I (305749) firmware::git_sync: verifying github.com TLS chain against embedded GitHub CA bundle
I (305979) firmware::usb_kbd: key: HalfPageUp          ← scroll arrives → editor loop paints
E (306259) spi_master: setup_dma_priv_buffer(1206): Failed to allocate priv TX buffer
Error: ESP_ERR_NO_MEM
I (306259) main_task: Returned from app_main()         ← editor task exits
...
I (310119) firmware::git_sync: push accepted by remote ← git thread unaffected; commit landed
I (311069) firmware::usb_kbd: key: Escape              ← keys still logged, no refresh ever again
I (312729) firmware::usb_kbd: key: HalfPageDown
```

## Root cause

The EPD is on SPI2 configured `Dma::Auto(4096)` (`main.rs`), and the driver hands
frame data to `spi.write()` as ordinary Rust `Vec<u8>` buffers (`epd.rs`
`write_frame_bank` / `data`). With PSRAM added to the heap allocator, those
`Vec`s can be allocated **from PSRAM**, which is **not DMA-capable**. When a
transfer buffer isn't DMA-capable, esp-idf's `spi_master` bounces it through a
temporary internal buffer it mallocs on the fly (`setup_dma_priv_buffer`, using
`MALLOC_CAP_DMA` → **internal RAM only**).

For the whole session that bounce allocation succeeded, because internal RAM was
plentiful. The instant `:sync` brought up **Wi-Fi + TLS**, they consumed the
small internal pool. The next paint's bounce allocation returned
`ESP_ERR_NO_MEM`. The real defect is not the low-memory moment itself — it's that
the paint's `?` made a **transient, retryable** I/O failure **fatal to the whole
appliance**.

Two things made this easy to misread:

- **"8.4 MB free heap" is a red herring.** That figure is dominated by PSRAM.
  The starved pools are the tiny internal ones (~265 KB / 21 KB / 32 KB), and DMA
  bounce buffers can only come from those.
- **It looked like a git/sync bug, but the push was fine.** The git thread
  finished and the remote accepted the commit. Only the UI task died.

## Timeline

1. Hour of normal editing — hundreds of ~630 ms partial refreshes, no issue
   (internal RAM never under pressure; Wi-Fi off — the radio is lazy, ADR-006).
2. `:sync` → save → git thread brings up Wi-Fi, SNTP, TLS, commits `48a2c0a8`,
   starts the push. Internal RAM now under heavy Wi-Fi/TLS load.
3. User keeps scrolling (`HalfPageUp`) during the push. Each scroll triggers a
   full-area partial refresh → SPI-DMA transfer → bounce-buffer malloc.
4. One such malloc fails (`ESP_ERR_NO_MEM`); the `?` in the refresh call
   propagates out of `main()`; `main_task` returns from `app_main()`.
5. Push completes normally; Wi-Fi torn down; internal RAM freed — but the editor
   task is already gone, so nothing repaints. Keys log into the void.

## What it was _not_

- **Not out of heap** — plenty of PSRAM free; it was internal _DMA-capable_ RAM
  specifically.
- **Not a git or TLS bug** — the sync succeeded end to end.
- **Not an editor-core bug** — `editor`/`keymap` never ran; the failure is in the
  firmware paint path's error handling.
- **Not a panel/wiring fault** — the same paint path worked for an hour and works
  again after Wi-Fi is down.

## Remediation shipped — paints are non-fatal

A screen refresh is idempotent and retryable: the editor buffer is the source of
truth, so a dropped frame costs nothing and the next paint recovers. This is the
exact contract already written into `save_note` ("errors are logged, never
propagated"). Every paint site in the editor loop (`main.rs`) now:

- logs the failure and **drops the frame** instead of `?`-propagating it;
- leaves `shown` untouched so the next paint repaints the same diff;
- sets a `force_full` flag so the next paint is a **full refresh**, which
  rewrites both RAM banks and recovers from a partial that may have died
  mid-transfer and left the `0x24`/`0x26` banks inconsistent.

Effect: a paint that lands during a sync is dropped (panel goes stale for the
~15 s of the push), then self-heals the moment the push finishes and internal RAM
frees. A permanent brick becomes a brief stale window. The boot-time first render
stays `?`-fatal on purpose — it runs before Wi-Fi, can't hit this, and a dead
panel at boot is a legitimate hard fault.

## Root-cause eradication (specced, not yet built)

The safety net stops the brick but not the underlying **contention**: paints
during a sync still fail and drop. To keep the editor fully live while a push
runs — the whole point of the async git thread (ADR-006) — remove the on-the-fly
DMA allocation entirely.

**Fix: a persistent, internal, DMA-capable scratch buffer owned by `Epd`.**

- Allocate it **once at `Epd` construction** (boot, before Wi-Fi is ever up, when
  internal RAM is plentiful) via
  `heap_caps_malloc(SPI_CHUNK, MALLOC_CAP_DMA | MALLOC_CAP_INTERNAL | MALLOC_CAP_8BIT)`.
- `data()` already chunks writes to `SPI_CHUNK` (4096 B), so a **4 KB** scratch
  buffer is sufficient: copy each chunk into it and hand that DMA-capable slice to
  `spi.write()`.
- Because the source is now DMA-capable, `spi_master` DMAs directly from it —
  `setup_dma_priv_buffer` is never invoked, there is **no per-refresh
  allocation**, and paints no longer compete with Wi-Fi/TLS for internal RAM.
  Refreshes then succeed during a sync, and `force_full` recovery is only ever
  exercised by genuine faults, not by normal syncing.

**Cost:** ~4 KB of internal RAM reserved for the life of the device; one small
`unsafe` block for the alloc + slice; a `memcpy` per 4 KB chunk (negligible
against the ~630 ms panel waveform).

**Alternatives considered and rejected:**

- _Trim Wi-Fi's internal buffer counts_ to leave headroom — fragile tuning that
  risks Wi-Fi stability/throughput and only widens the margin instead of removing
  the failure mode.
- _Force the whole ~13.6 KB frame buffer internal_ (custom allocator / full
  `heap_caps` buffer) — larger reservation and more churn than the 4 KB
  chunk-scratch, for no extra benefit since `data()` already chunks.
- _Serialize paints against sync_ (skip painting while a push is in flight) —
  defeats the async-git design and freezes the panel for the whole push; the
  safety net already makes this unnecessary.

**Verification when built:** reproduce the exact failing scenario — edit,
`:sync`, and keep scrolling/paging through the _entire_ push. Expect: every
refresh succeeds (no `refresh … FAILED` warnings, no dropped frames), min-ever
internal heap stays comfortably above zero throughout, and `force_full` is not
triggered by the sync.

## Follow-ups

- [x] Make all editor-loop paints non-fatal + `force_full` recovery (`main.rs`);
      release build green.
- [x] Reflash and hardware-verify the safety net against the repro (edit →
      `:sync` → scroll through the push): panel must recover, not freeze.
      **Verified 2026-07-13** (real-repo-sync kaizen runs 5–9: concurrent
      typing/scrolling through full pushes, no freeze; bonus fix — repaints no
      longer allocate at all, closing the run-4 `Frame::new_white` OOM-abort
      variant of the same failure).
- [ ] Implement the persistent internal DMA scratch buffer in `Epd` (eradication
      above) if the stale-during-sync window proves annoying in real use —
      → tracked in [v0.9 robustness](../../plan/macroplan.md#v09--robustness--).
- [ ] After eradication, confirm refreshes succeed _during_ a push and drop the
      stale window entirely.

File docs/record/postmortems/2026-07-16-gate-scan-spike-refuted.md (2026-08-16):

# Gate-scan restriction spike — refuted: partial waveform time is MUX-independent

> Date: 2026-07-16 · Status: **CLOSED — negative result, reverted the same day.**
> The panel's ~545 ms partial-refresh floor stands; the only lever left is a
> custom LUT (not attempted, trade-offs below).
>
> Context: follow-on to the same-day
> [bank-toggle postmortem](2026-07-16-partial-refresh-bank-toggle.md), whose
> timing analysis flagged this lever. Panel + driver port:
> [ADR-003](../../adr.md#adr-003-display-medium--e-ink-gdey0579t93-panel),
> driver: [`screen_epd.rs`](../../../firmware/src/drivers/screen_epd.rs).

## Summary

Hypothesis: partial refreshes take ~545 ms regardless of band height because
the SSD1683 rides its power-on defaults and scans **all 300 gate lines** (the
panel has 272) on every update — so programming the gate registers to scan
only the refresh band (20 lines for one text row) should cut the waveform to
a fraction and transform typing feel.

Hardware said no, twice:

1. **No scaling.** With the scan restricted to 20 gates, the partial still
   ran 571 ms (vs 543 ms full-scan baseline). The waveform's BUSY time is set
   by its phase schedule (the LUT), not by how many gates are driven.
2. **A write-only hazard.** Writing driver output control (`0x01`) with the
   *datasheet* power-on scan-order byte **mirrored the panel vertically** —
   the operating gate configuration is loaded from panel OTP at reset,
   differs from the datasheet POR, and cannot be read back. Every partial
   then painted mirrored bands, desyncing both RAM banks (splash ghosts
   persisted through refreshes).

Reverted the same session. Verdict: **never write `0x01`/`0x0F` on the
GDEY0579T93**; `update_part`'s doc comment carries the warning.

## The experiment

Neither GxEPD2 nor the Good Display factory demo ever writes driver output
control (`0x01`, MUX = number of gate lines scanned) or gate scan start
position (`0x0F`) for this panel — confirmed against upstream source. Both
ride the power-on defaults. Combined with the bank-toggle session's
measurement (windowed 20-row band 543 ms vs full-area 629 ms — only the SPI
transfer scales), the "scan time = MUX × line time" model predicted a
one-line refresh somewhere around 40–140 ms.

The spike added, inside `update_part` and mirrored to both controllers
(master `0x00` / slave `0x80`, like the RAM-window commands):

```
0x01  [h-1 low, h-1 high, 0x00]   # MUX = band height, datasheet-POR order byte
0x0F  [y0 low, y0 high]           # scan starts at the band's first row
… partial kick (0x3C/0x21/0x22/0x20), busy-wait …
0x01/0x0F restored to (0, 300)    # assumed power-on defaults
```

The full-refresh path was untouched.

## What the flash showed

- `windowed refresh: 571 ms` for a 20-gate scan — the registers demonstrably
  took effect (see next line), so this cleanly refutes MUX-proportional
  timing.
- The image came up **mirrored across the X axis**, and the boot splash
  (circle + wordmark) never cleared: with the gate mapping flipped, every
  partial landed its band at the mirrored position, so the two RAM banks
  desynced across the whole panel.
- Full-area partials ran 690 ms (vs 629 baseline) — even the "free" 272-vs-300
  gate trim bought nothing.

## Why

- **Refresh duration lives in the LUT, not the scan.** An e-ink refresh plays
  a per-transition waveform: phases of ±15 V held for fixed numbers of
  frames. BUSY ends when the phase schedule ends. Driving fewer gates per
  frame doesn't shorten the schedule.
- **Datasheet POR ≠ operating config.** Good Display panels load their real
  gate setup (scan order/direction, interlacing) from panel OTP at reset.
  The registers are write-only, so there is no safe value to "restore" — any
  write of `0x01` gambles against calibration you can't read. This is the
  same lesson shape as the bank-toggle bug: the factory init sequence is the
  contract, including the registers it *doesn't* touch.

## The remaining lever: a custom LUT (not attempted)

The LUT is the waveform program itself: for each pixel transition
(white→black, black→white, no-change) it encodes which voltage to apply and
for how many frames. Our `init()` loads the factory-tuned one from panel OTP
(`0x22 = 0xB1`), temperature-compensated via the sensor reads. Writing our
own via `0x32` with shorter/fewer phases is how hobbyist "fast partial
refresh" projects reach ~100–200 ms on similar panels.

Known costs, which is why this stays parked:

- **Ghosting & contrast** — shorter pulses move the particles less; erased
  pixels shadow sooner and blacks gray out, demanding more frequent full
  refreshes.
- **Panel longevity** — the factory waveform is DC-balanced; a hand-rolled
  unbalanced one can permanently degrade the panel over months.
- **Temperature** — the OTP LUT is selected per temperature reading; one
  custom table behaves differently cold vs warm.
- **No reference** — the OTP waveform isn't pushed; this is
  reverse-engineering with the panel as the test bench.

Today's ~545 ms per keystroke *batch* (not per keystroke) is acceptable for
the one-refresh-per-batch editor model. Revisit only if typing latency
becomes the top user complaint.

## Lessons

- **Registers you can't read back are write-only hazards.** When a factory
  init never touches a register, that silence may itself be load-bearing —
  OTP-loaded state can hide behind any POR value in the datasheet.
- **Cheap refutation is good spike economics.** One driver-level change,
  one flash, and the existing per-refresh timing logs settled a "very
  promising" theory in minutes — including a failure mode (mirroring) that
  proved the writes took effect, making the negative timing result trustworthy.

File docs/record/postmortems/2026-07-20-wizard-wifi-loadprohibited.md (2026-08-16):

# Postmortem — Onboarding wizard Wi-Fi bring-up boot loop (LoadProhibited)

**Date:** 2026-07-20
**Firmware:** 0.7.9
**Component:** `firmware/src/infrastructure/wizard_io.rs` (`run`), toolchain codegen
**Severity:** High — every card entering onboarding boot-looped; the device was unusable for any first-time / BYO-card user.
**Status:** Fixed and verified on device.

## Summary

Any card that entered the onboarding wizard — blank card, foreign card, bring-your-own card, a card with an incomplete `typoena.conf`, or an explicit `:setup` — sent the device into a reboot loop. The crash was a `LoadProhibited` Guru Meditation the instant the wizard tried to bring up the Wi-Fi radio, immediately after the "card erased — dedicated to Typoena" step.

The root cause was **not** in our logic and **not** in the Xtensa argument ABI, though it spent a long time looking like both. It was a **backend miscompilation of the wizard's enormous `run` function at `opt-level = "s"`**: the size optimizer emitted code that read a value out of a stack slot it never wrote. The fix is a one-line, surgically-scoped compiler setting — compile the `firmware` package at `opt-level = 2` — not any source change.

## Impact

- **Who:** every first-time user, and anyone re-running `:setup`. Already-provisioned cards (which skip the wizard) were unaffected, so this never showed up in day-to-day use or in `:gp`/`:gl` sync.
- **Failure mode:** hard boot loop (`rst:0xc RTC_SW_CPU_RST` — the panic handler resetting into the same crash), not a graceful failure. The device never reached the Wi-Fi network list.
- **Data:** none lost. On BYO cards the consent gate + card wipe worked correctly; the crash was strictly *after* that, at radio bring-up.

## The symptom

```
Guru Meditation Error: Core 0 panic'd (LoadProhibited). Exception was unhandled.
EXCCAUSE: 0x1c   EXCVADDR: 0xa5a5a5a5
```

Two facts made this diagnosable:

1. **`0xa5a5a5a5` is not random garbage.** `0xa5` is FreeRTOS's `tskSTACK_FILL_BYTE`, the pattern it paints fresh task stacks with. A load *from* (or *of*) `0xa5a5a5a5` means we dereferenced a pointer/value that lives in a stack slot that was allocated but **never written** — an uninitialized-stack read.
2. **It always landed at the same place:** the first thing the wizard does that touches a real object — cloning one of the esp-idf singletons on the way into `EspWifi::new`.

`EspSystemEventLoop` and `EspDefaultNvsPartition` are `Arc`-backed. `.clone()` on one is an `Arc::clone` that dereferences the `ArcInner` `NonNull` pointer. If that pointer was read from an unwritten stack slot, it *is* `0xa5a5a5a5`, and the atomic refcount bump faults. (The `Modem`/`WifiModem` peripheral is a ZST — cloning/reborrowing it never dereferences anything — which is why the modem argument *never* crashed even when its slot was poisoned. That was a red herring for most of the investigation.)

## Root cause

At `opt-level = "s"`, the Xtensa/LLVM backend miscompiled `wizard_io::run`. `run` is an **enormous** function (the entire wizard event loop, inlined helpers and all). Somewhere in its stack-slot allocation for argument spills and by-value struct copies, the optimizer emitted a read from a slot that no store ever populated. Whatever singleton landed in that slot was then `0xa5a5a5a5`, and the first `.clone()` of it faulted.

The size optimizer is exercised hardest on exactly the largest functions, and `run` is the largest in the crate. This is a backend defect, not undefined behavior in our Rust.

## The chase — why it took six device flashes

Each hypothesis below was a build → flash → `addr2line` cycle. The trap was that the crash **moved with every codegen change but never cleared** — which, in hindsight, was itself the diagnosis.

| # | Hypothesis | Change | Result |
|---|---|---|---|
| 1 | 84-byte by-value `Conf` (7 `String`s) spills `nvs`/`sys_loop` into unwritten Xtensa arg-spill slots | `start: &conf::Conf` (8 bytes, one slot) | Crash **moved** to `sys_loop.clone()`, did not clear |
| 2 | `esp_wifi_init` can't get a contiguous internal DMA block (largest free ~63 KB with the 96 KB clone worker resident) | `CONFIG_SPIRAM_TRY_ALLOCATE_WIFI_LWIP=y` | **No change** — a 0xa5 load is a stack read, not a failed alloc. Disproven as the cause. |
| 3 | Threading singleton *references* through the deep inlined loop materializes the bad slot | Own singletons by value; `#[inline(never)] build_radio` helper (mirrors the working `wifi_tls` spike); build radio lazily | Crash **moved** to `nvs.clone()` at the `build_radio` call (with `run` inlined into `main`) |
| 4 | Need *all* the levers: `#[inline(never)]` on `run` **and** `&Conf` **and** by-ref singletons | all three at once | Crash **moved earlier** — a compiler-generated `memcpy` from `0xa5` at loop entry (PC `0x42013e13`), *before any keypress*. `#[inline(never)]` **introduced a fresh** miscompilation. |

The by-value → by-ref swap in hypothesis #1 producing "crash moved, didn't clear" was already the tell. It took three more rounds to accept that no rearrangement of the source feeding the optimizer would fix an optimizer that mis-allocates stack slots.

The evidence that finally reframed it: the fault relocates in lock-step with **argument order, argument count, by-ref vs by-value, and inline hints** — every one of these is a codegen knob, none of them is a correctness knob for well-defined Rust. When behavior tracks the codegen path and not the program's meaning, the codegen path is broken.

## The fix

Stop compiling this crate at `opt-level = "s"`:

```toml
# firmware/Cargo.toml
[profile.release.package.firmware]
opt-level = 2
```

A per-package profile override recompiles the `firmware` crate (lib + bin) with a codegen path that emits the same straightforward source correctly, while the workspace crates and the bench bins (`sd_bench`, `wifi_tls`, `qc`) keep the size-tuned `"s"`. Cost: **+~55 KB** flashed image (2,259,776 → 2,314,736 B, 14.13% of the factory partition — negligible headroom impact).

Kept as belt-and-suspenders (and just better code): the lean signature — `start: &conf::Conf`, by-ref `sys_loop`/`nvs`, and the lazy `build_radio` helper. Removed: `#[inline(never)]` on `run` (only ever a workaround attempt; it *introduced* variant #4).

## Verification

Flashed 2026-07-20 onto an unconfigured card:

```
wizard: card erased — dedicated to Typoena
wizard: bringing up the Wi-Fi radio — internal DRAM free 165791 B (largest block 63488 B)
wifi:mode : sta (94:a9:90:d1:74:78)
wizard: scan found 5 network(s)
```

No Guru Meditation. The radio came up on the main task and the scan reached the network list — the point six argument-shuffling attempts never got to.

## What went well

- **`debug = 2` + `addr2line -f -i -C`** pinned every crash to an exact inlined source line. Without per-crash line resolution, the "it moves but never clears" pattern would have been invisible — this is what ultimately cracked it.
- **Recognizing the UX cost mid-chase:** an early eager-radio-build variant delayed the first wizard paint ~1–2 s; switched to a lazy build (radio comes up only on the first effect that needs it) so the fix didn't regress onboarding feel.

## What went wrong

- **Four hypotheses / six flashes chasing the ABI** before concluding "backend bug." The relocation after hypothesis #1 was sufficient evidence to pivot; instead three more ABI variants were generated.
- **`CONFIG_SPIRAM_TRY_ALLOCATE_WIFI_LWIP` was added under a wrong causal story** (a 0xa5 load can never be a failed allocation). The flag is *kept* — internal DRAM is genuinely tight at radio bring-up (~63 KB largest free block) and routing Wi-Fi/LWIP to PSRAM is legitimate headroom — but its comment is corrected to say so.

## Lessons

1. **`LoadProhibited` on exactly `0xa5a5a5a5` = uninitialized-stack read** (FreeRTOS `tskSTACK_FILL_BYTE`). Treat that specific value as a diagnostic, not generic corruption.
2. **A fault that relocates predictably with every codegen change but never clears is a compiler-backend bug, not an ABI mistake.** The relocation *is* the evidence: you're moving where the optimizer parks a bad read, not fixing what feeds it. Stop rearranging source; change the codegen path.
3. **Enormous functions are miscompilation surface at aggressive size-opt.** The size optimizer is stressed hardest on the biggest functions — and `run` is the biggest.
4. **ZST peripherals are red herrings in an ABI hunt.** `Modem` never faulted from its poisoned slot because nothing dereferences a ZST; "the modem arg is fine" did not mean "the slot is fine."
5. **Per-package `opt-level` is the surgical lever** — fix one crate's codegen without paying size across the workspace.

## Action items

- [x] `[profile.release.package.firmware] opt-level = 2` — the fix.
- [x] Removed the temporary `debug = 2` from `[profile.release]` (crash resolved; addr2line no longer needed).
- [x] Corrected the `CONFIG_SPIRAM_TRY_ALLOCATE_WIFI_LWIP` comment in `sdkconfig.defaults` (kept the flag, fixed the story).
- [ ] **Run the rest of onboarding on device** — join network → device-flow auth → clone. The crash is fixed *to the scan*; the full flow past the network list is not yet re-verified end to end.
- [ ] **Recognition note for future size-opt miscompiles.** If a second one appears, consider `opt-level = 2` workspace-wide and/or a minimal repro filed upstream (rust-lang / esp-rs, Xtensa LLVM).
- [ ] **A wizard smoke test** (bench-qc fixture is the natural home): "enters wizard + radio scans" as a go/no-go would have caught this before a user hit the boot loop.

### Note on splitting `run`

Decomposing `run` into smaller functions is tempting for readability, but **it is not the fix and would not have prevented this** — new function boundaries *reintroduce* the argument-spill surface that hypotheses #1/#3 chased. The `opt-level = 2` override, not decomposition, is the correctness guarantee. Refactor `run` for clarity if desired, but keep the override.

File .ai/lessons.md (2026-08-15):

# Lessons

## "on save" means the device, not the host tooling (2026-08-08)

An editor-behavior ask in this repo ("on save, …", "lint on save") is about the
Typoena device's editor — the `editor` crate's core plus its `app`/`firmware`
adapters. It is not about Zed settings, Claude Code hooks, or repo tooling.
Ask before touching `.zed/` or `.claude/` for a behavior request.

## A research conversation is not a change request (2026-08-15)

Session `16ecf0f4` (2026-08-09) was twelve questions about buying a 40% Planck
— "where can I buy one of these", "and the keys?", "1u?". It ended in
`6d148d4`, editing `typoena-case-kb.scad`, `README-kb.md` and `hardware/justfile`.
The research was the ask and was answered; the model edit nobody requested.

When research turns up a real model defect, name it and offer the fix. Land it
when asked.

## Read the parameter block, not the whole model (2026-08-15)

`typoena-case.scad` is 34.5 KB and `README.md` 17.7 KB — ~13k tokens to read
both in full, for a change that moves one constant. The 84 parameters live in a
banner-separated block at lines 30–285. Read that plus the single module that
consumes the constant.

## Storage-layer guarantee ≠ user-visible behavior (2026-08-08)

Claimed "firmware already appends the trailing newline" from
`storage_sd.rs:atomic_write`, and it was wrong from the writer's seat: the byte
landed on the file, but the buffer never gained the empty last row, so nothing
changed on screen and the buffer stayed a byte out of step with its file.
Before saying a feature exists, check the layer the user actually observes
(buffer / screen), not just the deepest layer that touches the bytes.

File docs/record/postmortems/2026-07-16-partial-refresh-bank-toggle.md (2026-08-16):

# Display "buffer toggling" — partial refresh left one RAM bank two frames stale

> Date: 2026-07-16 · Build at time of diagnosis: `07-16 19:59Z @61db4a6-dirty`
> Status: **FIXED, verified on device 2026-07-16** — after every partial
> refresh the band is re-written to *both* controller RAM banks (the GxEPD2
> `writeImageAgain` sequence). Lines no longer flap during fast typing.
>
> Context: partial refresh landed in Spike 5, windowed-Y in Spike 13 (both in the
> [spike log](../../../firmware/docs/bring-up-spikes.md)),
> panel + driver port [ADR-003](../../adr.md#adr-003-display-medium--e-ink-gdey0579t93-panel),
> driver: [`screen_epd.rs`](../../../firmware/src/drivers/screen_epd.rs), refresh
> policy: [`../../firmware/src/main.rs`](../../../firmware/src/main.rs).

## Summary

Since the v0.1 partial-refresh port, writing fast made the panel "toggle":
lines below the caret flapped up and down around an Enter (the new line
appearing, un-appearing, re-appearing), and characters from the previous
keystroke batches flickered out and back in. Everything always settled correct
at the next pause, which is why it survived every spike and soak as a vague
"e-ink shimmer" until a fast-writing session made it undeniable.

Root cause: the SSD1683 **ping-pongs its two RAM banks on every Display Mode 2
(partial) update**, and the driver's partial path re-synced only the `0x26`
bank afterwards — which post-swap is the bank that is *already correct*. The
other bank was left holding the frame from **two refreshes ago**, and the next
partial drove the whole panel toward it. Every second partial update therefore
repainted recent history: new content reverted, then returned, alternating.

One extra band write per refresh fixes it. The cost is ~5 ms on a windowed
keystroke refresh, ~60 ms on a full-area pass.

## Symptom

- Fast typing, especially across an Enter: the lines below the caret jump to
  their shifted position, jump back, jump forward again — "the lines get
  swapped up with what there was before."
- Characters from the previous 1–2 keystroke batches blink off/on (subtle — a
  10 px glyph next to a 20 px line shift).
- Always self-heals at the next pause or Normal-mode action. Saved text was
  never wrong; this was purely a panel artifact.

## Investigation

### Wrong turn first: refresh cadence

The per-refresh log (`windowed/full-area/FULL refresh #N … rows a..=b`) first
pointed at cadence, and three real problems fell out of that pass:

1. the periodic panel-longevity FULL refresh promoted a *keystroke* repaint
   every 64 updates — and since the counter only advanced while typing, its
   ~2 s multi-flash could **only ever** land mid-sentence;
2. the 750 ms Insert caret debounce fired during ordinary mid-sentence pauses,
   and each show + erase-on-resume pair cost two whole-panel passes;
3. any erase — including just the caret bar — forced a full-area pass.

All three were fixed (debounce → 2000 ms; FULL deferred to the idle branch;
caret-bar erase allowed on the windowed path via an erase-bounding-box check).
They made typing calmer — and made the *real* bug *more* visible, which was
the tell: the frequent caret full-area passes had been accidentally healing
the panel every second or two.

### The trace that pinned it

A second serial trace during a repro session proved the firmware side clean:
every refresh band matched the keystroke stream exactly (the Enter's line
shift landed as one `full-area (rows 40..=259)`, subsequent chars as
`windowed (rows 40..=59)`), and no band ever re-painted a reverted layout. The
frames were right; the panel disagreed — so the divergence had to live in the
controller's RAM banks.

Two timing facts closed in:

- windowed (20 rows) vs full-area (272 rows) partials measured **543 ms vs
  629 ms** — the waveform does *not* scale with the band; only the SPI
  transfer does. Every partial update drives the whole panel, so the whole
  panel is exposed to whatever the banks contain, every time;
- the toggling alternated update-by-update — the signature of *two* states
  taking turns, i.e. two banks taking turns being the reference.

### Root cause: Mode-2 ping-pong vs a one-bank resync

The driver's partial sequence was:

```
write 0x24 (band) → update_part → write 0x26 (band)   # WRONG for this panel
```

Upstream GxEPD2 for this exact panel (`GxEPD2_579_GDEY0579T93`) re-writes the
image to **both** banks *after* every partial refresh (`writeImageAgain`:
`0x26` then `0x24`). The reason: on a Mode-2 display the controller swaps the
roles of the two RAM buffers. Post-swap, `0x26` addresses the just-displayed
(correct) buffer and `0x24` addresses the stale one — so syncing only `0x26`
is a no-op, and the stale buffer stays stale:

```
physical buffers P, Q            P            Q          panel shows
full-area refresh (frame F0)     F0           F0         F0
partial #1 (F1, band b1)
  write 0x24[b1]                 F1           F0
  update  → drives diff(P,Q)                             F1   (swap: 0x24→Q)
  write 0x26[b1]  (lands in P)   F1 (no-op)   F0  ← never updated
partial #2 (F2, band b2)
  write 0x24[b2]  (lands in Q!)  F1           F0+b2
  update  → drives diff(Q,P)                             F0+b2  ← b1 REVERTED
partial #3 (F3, band b3)                                 F3     ← b1 restored,
  …                                                              b2 reverted
```

Every second partial repaints toward a buffer that is mostly two frames old.
Any full-frame pass (full refresh, or a full-area partial, which writes all
272 rows around the update) rewrites both physical buffers and heals
everything — which is exactly why the bug hid behind the old 750 ms caret
cadence, slow deliberate spike testing (Spike 13 verified windowed-Y with
single measured edits), and Normal-mode-heavy sessions.

## The fix

[`screen_epd.rs`](../../../firmware/src/drivers/screen_epd.rs) `display_frame_partial_window` now ends
with the faithful GxEPD2 sequence — band re-written to both banks, `0x26`
then `0x24`:

```
write 0x24 (band) → update_part → write 0x26 (band) → write 0x24 (band)
```

Verified on device 2026-07-16: fast typing across Enters, lines shift once
and stay put; no char flicker from previous batches.

## Shipped alongside (same session)

- `CURSOR_DEBOUNCE_MS` 750 → 2000 ms (no caret churn on mid-sentence pauses).
- Panel-longevity FULL refresh deferred to the idle branch
  (`partials_since_full` counter; never promotes a keystroke repaint anymore).
- `only_adds_ink` → `erase_bbox`: an erase confined to one character cell with
  the caret on screen (the debounced caret bar being re-suppressed) rides the
  windowed path instead of forcing a full-area pass.

## Lessons

- **Port the *sequence*, not the register writes.** The original port read
  GxEPD2's post-refresh writes as "sync the previous bank" and kept only the
  `0x26` write. The `writeImageAgain` name — *again*, same image, both banks —
  was the contract; the ping-pong is why it exists.
- **A bug that self-heals hides behind anything that heals it.** The caret
  debounce was accidental hygiene; removing it exposed the real fault.
  Cadence fixes that make a display *worse* are a strong hint the remaining
  fault is state, not policy.
- **Prove which layer owns the corruption before touching it.** The refresh
  log's per-band rows made it possible to verify every frame against the
  keystroke stream and exonerate the firmware — after that, the panel RAM was
  the only suspect left.
- **Measured timings encode architecture.** Windowed vs full-area at
  543/629 ms said "the waveform drives all gates regardless" — which both
  scoped the blast radius of stale RAM and flagged a candidate lever:
  restricting the gate scan so single-line updates get *actually* fast.
  **Spiked and refuted the same day**: programming driver output control
  (`0x01`, MUX = band height) + gate scan start (`0x0F`) on both controllers
  took visible effect but a 20-gate scan still ran 571 ms — the partial
  waveform's BUSY time does not scale with MUX on this panel. Worse, writing
  `0x01` with the datasheet POR scan-order byte **mirrored the panel
  vertically**: the operating gate config is loaded from panel OTP at reset,
  can't be read back, and differs from the datasheet POR. Verdict: `0x01` is
  a write-only hazard on this panel; the ~545 ms partial floor stands. Lever
  closed — full spike writeup in
  [the gate-scan postmortem](2026-07-16-gate-scan-spike-refuted.md).

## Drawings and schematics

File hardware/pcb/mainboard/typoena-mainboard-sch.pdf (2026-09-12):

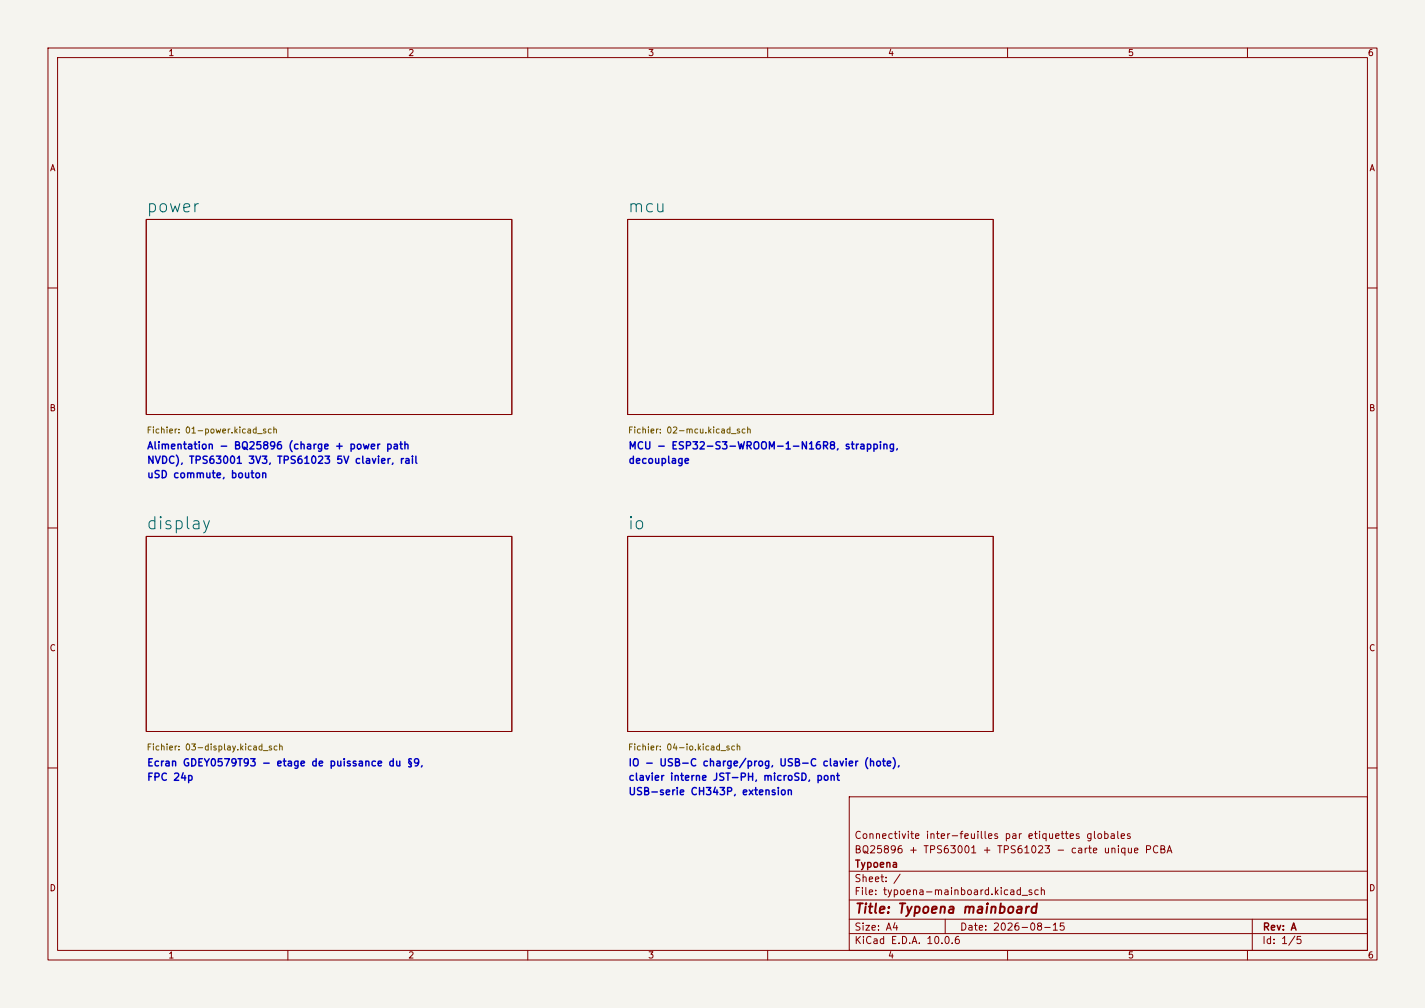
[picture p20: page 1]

Fichier: 01-power.kicad_sch
Alimentation - BQ25896 (charge + power path
NVDC), TPS63001 3V3, TPS61023 5V clavier, rail
uSD commute, bouton

Fichier: 03-display.kicad_sch
Ecran GDEY0579T93 - etage de puissance du §9,
FPC 24p

Fichier: 04-io.kicad_sch
IO - USB-C charge/prog, USB-C clavier (hote),
clavier interne JST-PH, microSD, pont
USB-serie CH343P, extension

Connectivite inter-feuilles par etiquettes globales
BQ25896 + TPS63001 + TPS61023 - carte unique PCBA
Typoena
Sheet: /
File: typoena-mainboard.kicad_sch
Title: Typoena mainboard

Size: A4 | Rev: A
KiCad E.D.A. 10.0.6 | Id: 1/5

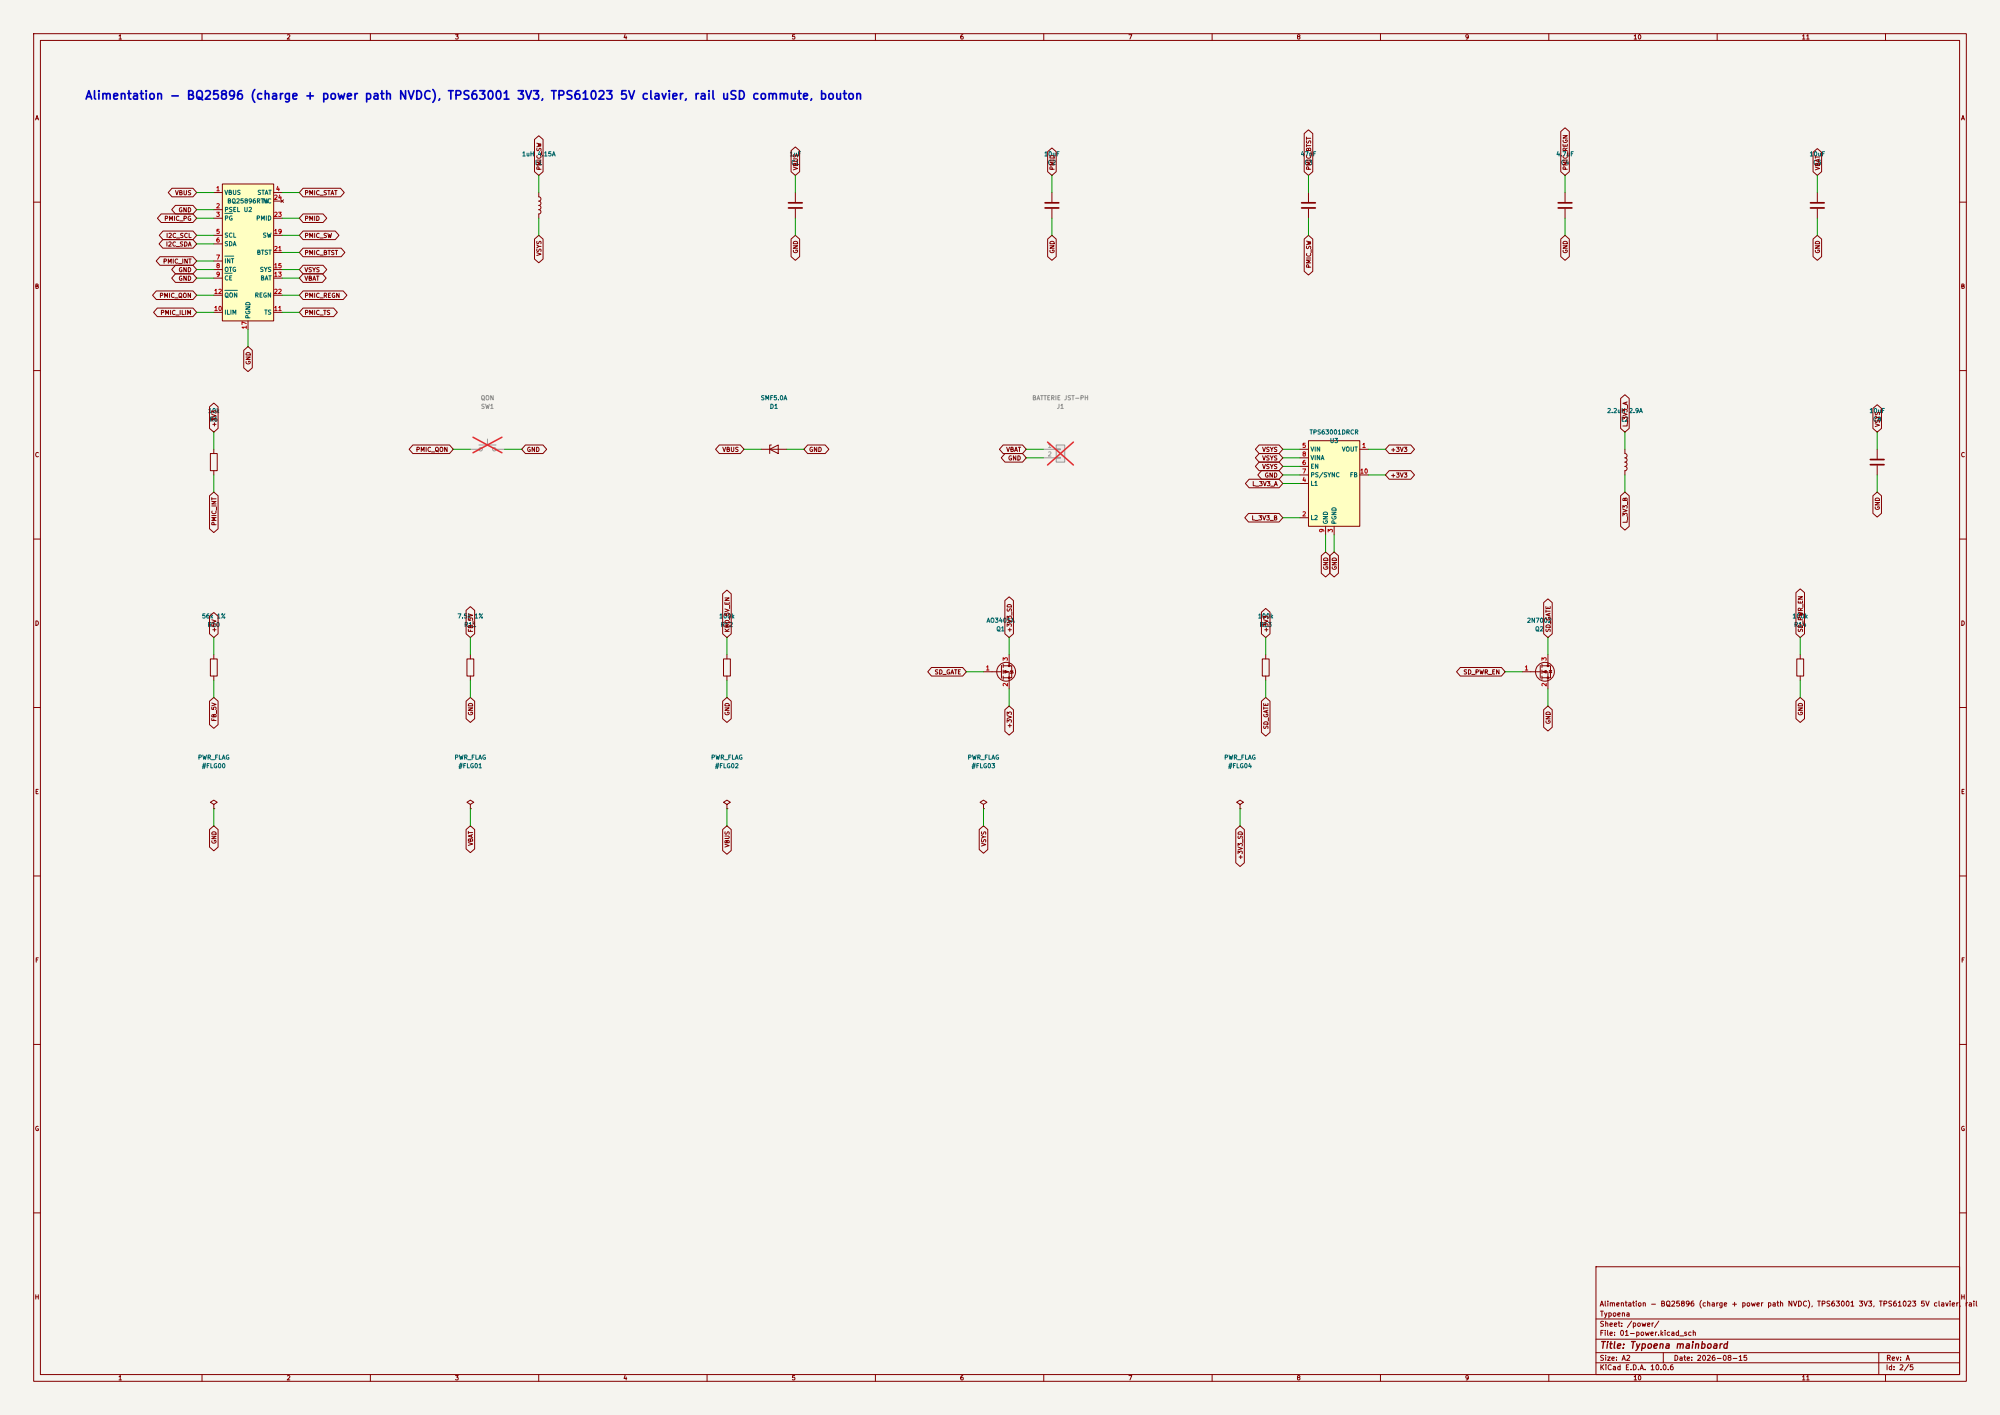
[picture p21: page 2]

PMIC_QON Alimentation - BQ25896 (charge + power path NVDC), TPS63001 3V3, TPS61023 5V clavier, rail uSD commute, bouton

SW 19 BTST 21 REGN 22 PMID 23 NC 24 U2 BQ25896RTW

Alimentation - BQ25896 (charge + power path NVDC), TPS63001 3V3, TPS61023 5V clavier, rail
Typoena
Sheet: /power/
File: 01-power.kicad_sch
Title: Typoena mainboard

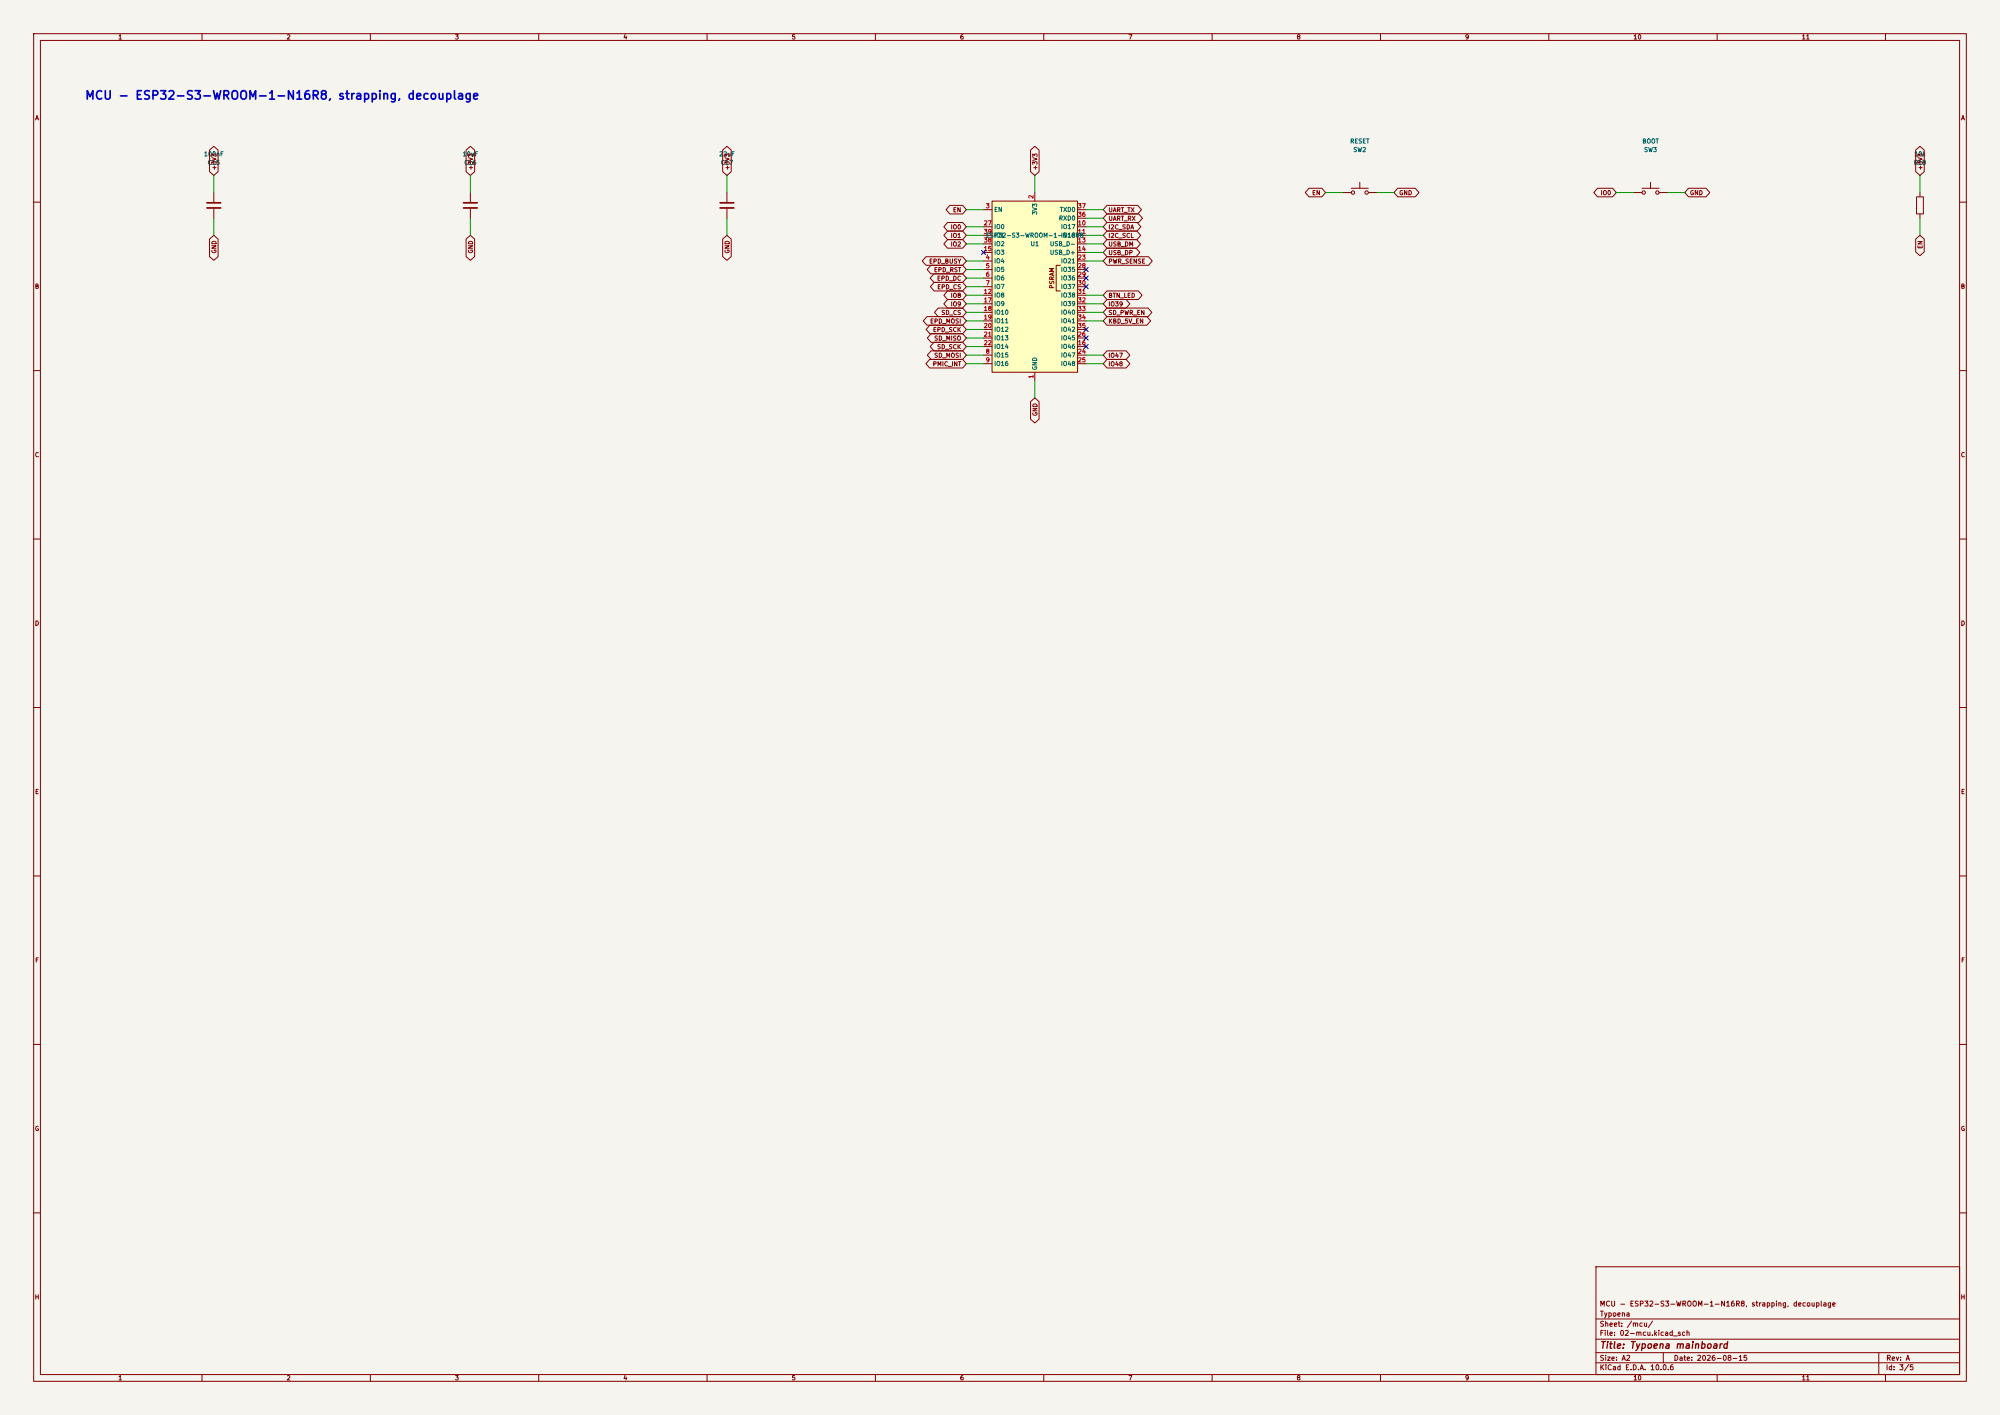
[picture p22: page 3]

MCU - ESP32-S3-WROOM-1-N16R8, strapping, decouplage

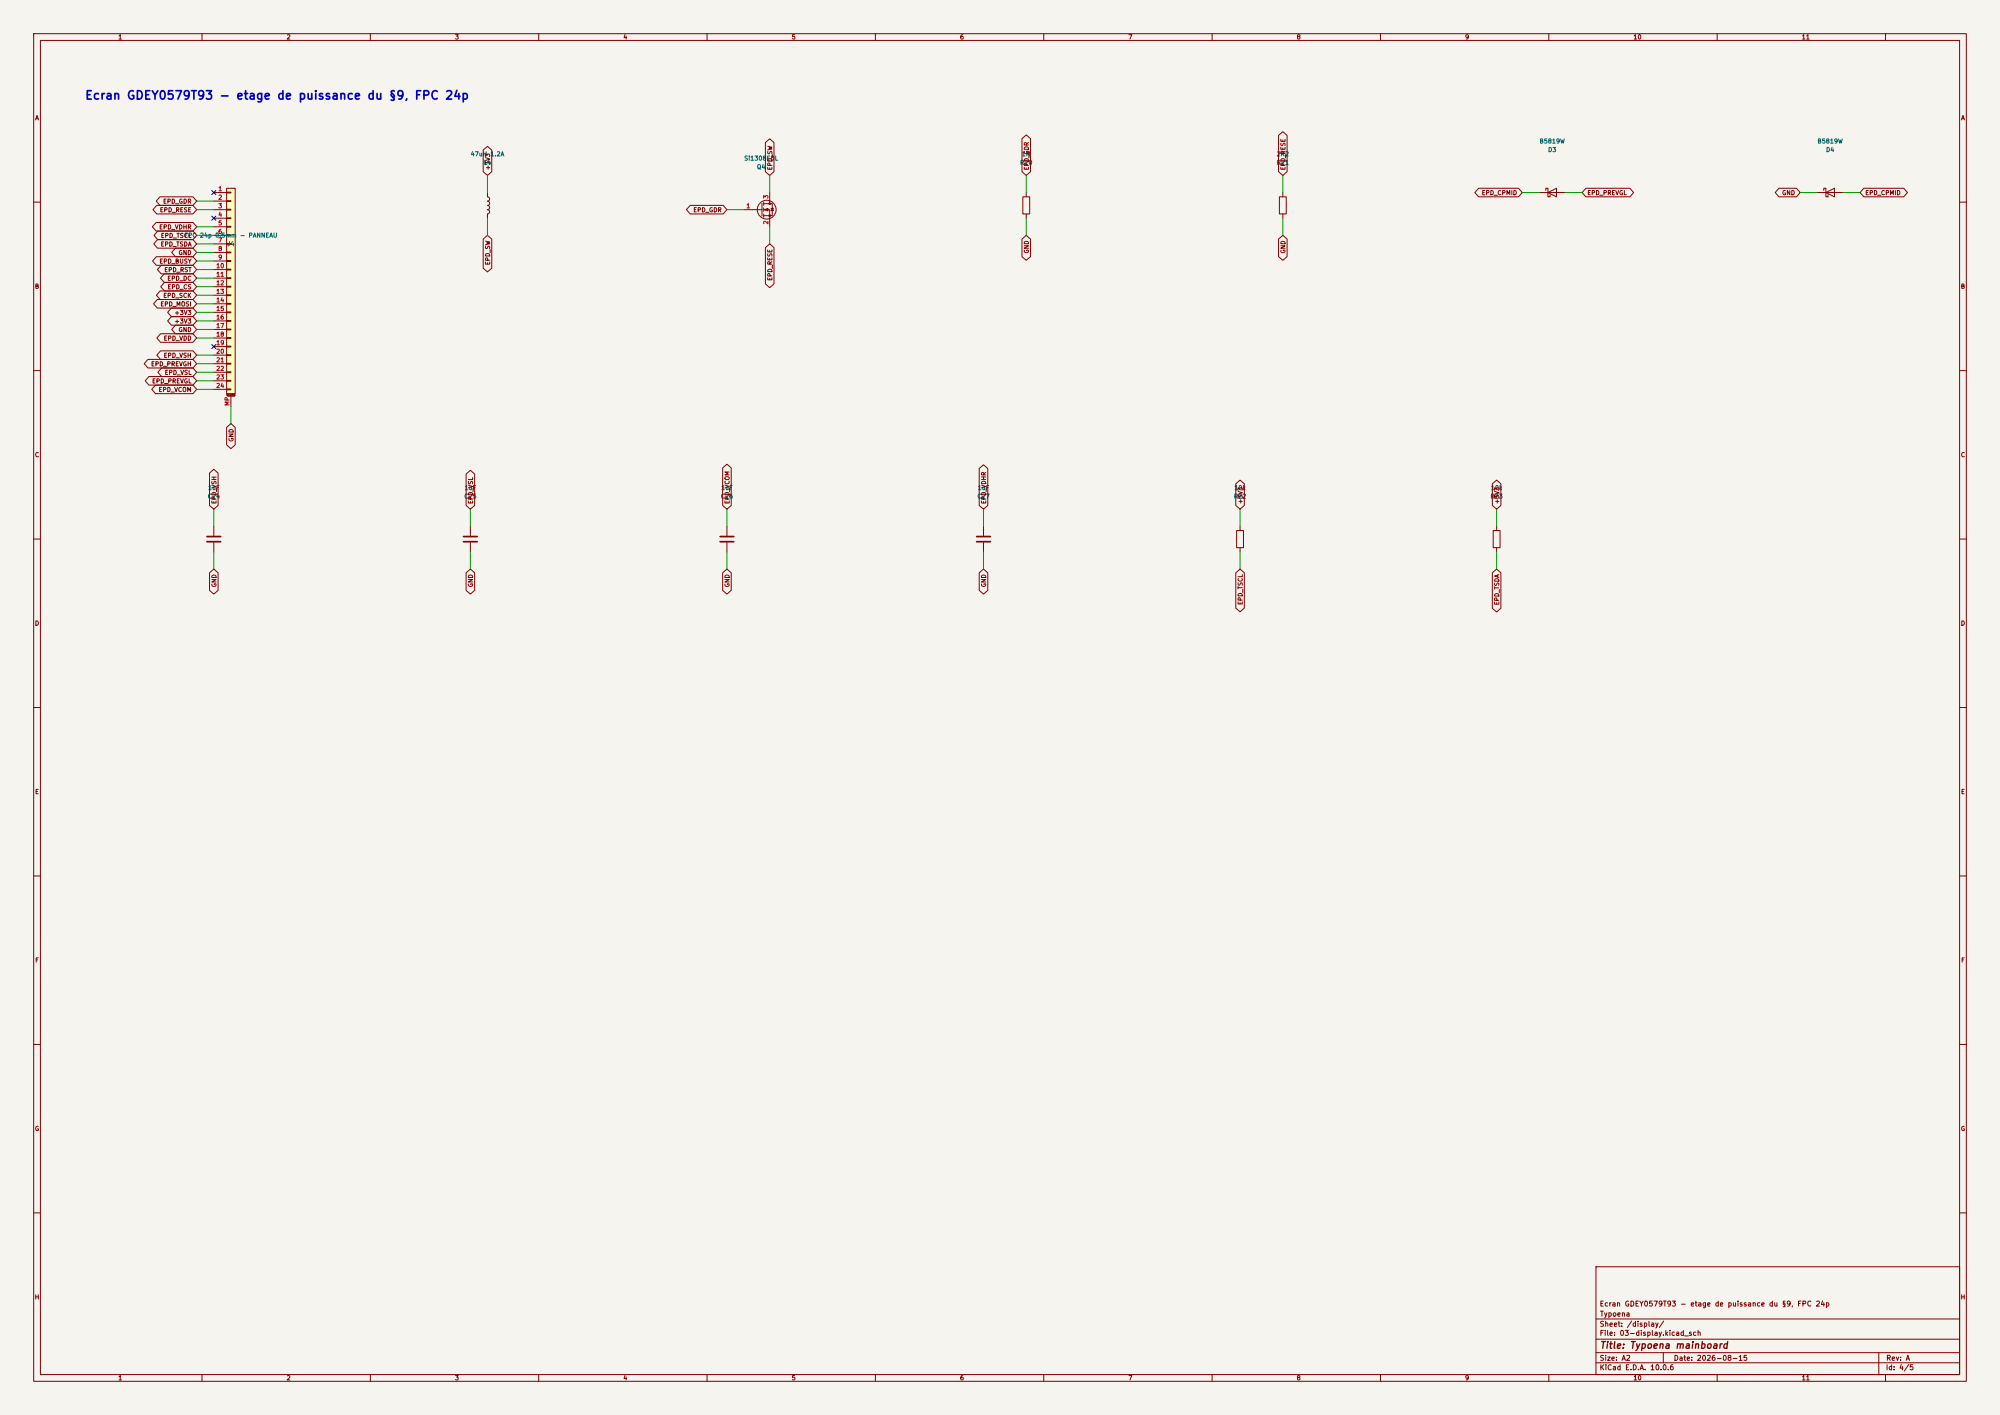
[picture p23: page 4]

GND Ecran GDEY0579T93 - etage de puissance du §9, FPC 24p

Ecran GDEY0579T93 - etage de puissance du §9, FPC 24p

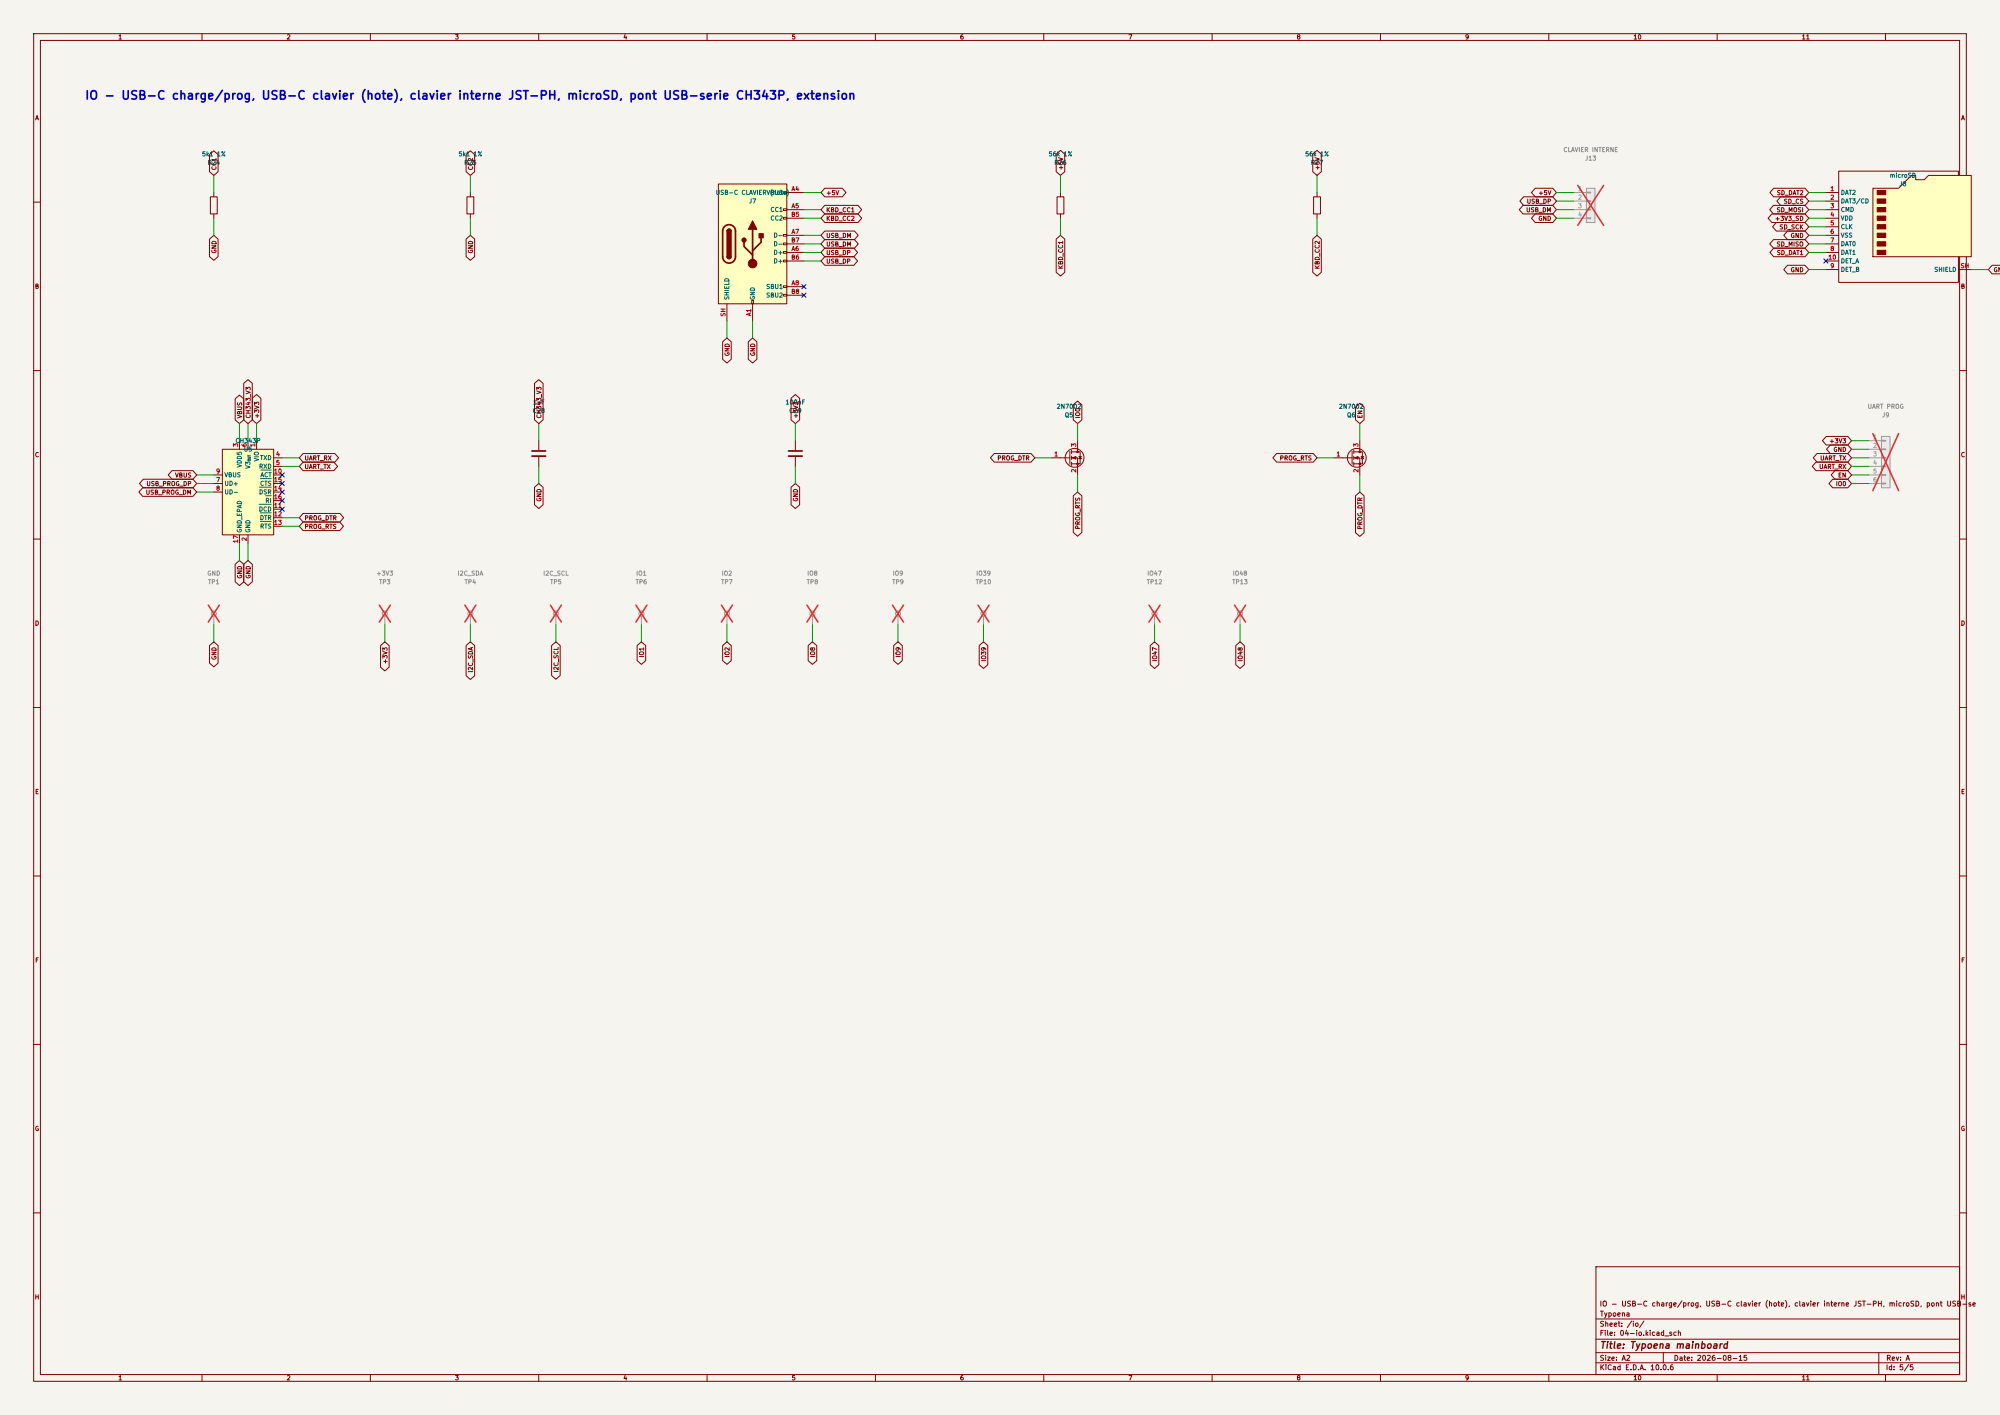
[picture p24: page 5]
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

ACT 10 DCD 11 DTR 12 RTS 13 DSR 14 CTS 15 RI 16 U5 CH343P

IO - USB-C charge/prog, USB-C clavier (hote), clavier interne JST-PH, microSD, pont USB-se

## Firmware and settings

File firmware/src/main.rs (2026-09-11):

use std::rc::Rc;

use esp_idf_svc::hal::cpu::Core;
use esp_idf_svc::hal::delay::FreeRtos;
use esp_idf_svc::hal::gpio::{AnyIOPin, PinDriver, Pull};
use esp_idf_svc::hal::i2c::{config::Config as I2cConfig, I2cDriver};
use esp_idf_svc::hal::peripherals::Peripherals;
use esp_idf_svc::hal::spi::config::{Config, DriverConfig};
use esp_idf_svc::hal::spi::{Dma, SpiBusDriver, SpiDriver};
use esp_idf_svc::hal::units::FromValueType;
use esp_idf_svc::hal::task::thread::ThreadSpawnConfiguration;

use app::{FileIndex, Panel, Runtime};
use display::Frame;
use editor::{Editor, Prefs, Scope, Snippets, LOCAL_DIR, PREFS_PATH, SNIPPETS_PATH};
use firmware::drivers::bq25896::Bq25896;
use firmware::drivers::clock_esp::{self, EspClock};
use firmware::drivers::keyboard_usb as usb_kbd;
use firmware::drivers::power_esp::{EspPower, Rails};
use firmware::drivers::screen_epd::Epd;
use firmware::drivers::system_esp::EspSystem;
use firmware::infrastructure::file_index::EspFileWalk;
use firmware::infrastructure::net::NetService;
use firmware::infrastructure::panic_scribe;
use firmware::infrastructure::sd_log;
use firmware::infrastructure::storage_sd::{SdStorage, Storage, CONF_PATH, NOTES};

/// Injected by build.rs so serial output identifies the exact build.
const BUILD_TAG: &str = concat!("build ", env!("BUILD_TIME"), " @", env!("BUILD_GIT"));

fn main() -> anyhow::Result<()> {
    // Required once before any esp-idf-svc call; some runtime patches
    // only link if this symbol is referenced. See esp-idf-template#71.
    esp_idf_svc::sys::link_patches();
    // Tees the serial log to the card (see `sd_log`); the flusher starts once
    // the mount exists, and everything logged before then is buffered.
    sd_log::init();

    // On the card too (`sd_log::DIAG`): it is the session separator in a
    // rotating log, and it names the build the rest of the lines came from.
    log::info!(target: sd_log::DIAG, "Typoena — modal editor (vim modes), {BUILD_TAG}");

    let peripherals = Peripherals::take()?;
    let pins = peripherals.pins;

    // FIRST: the two switched rails (uSD 3V3 on IO40, keyboard 5V on IO41) and
    // the button LED (IO38). Both enables carry a pulldown, so the card and the
    // keyboard are dead hardware until this runs — before the SD mount and
    // before `usb_kbd::start`, not merely early.
    let rails = Rails::bring_up(pins.gpio40, pins.gpio41, pins.gpio38)?;

    // Positional arg order: SCK 12 · MOSI 11. CS 7 · DC 6 · RST 5 · BUSY 4 below.
    let spi = SpiDriver::new(
        peripherals.spi2,
        pins.gpio12,
        pins.gpio11,
        None::<AnyIOPin>,
        &DriverConfig::new().dma(Dma::Auto(4096)),
    )?;
    // SSD1683 takes 10–20 MHz. This clock sets only the pixel clock-out, not the
    // waveform BUSY time, so it trims the pre-kick band write (~43 ms at 4 MHz).
    // Sweeping higher risks signal-integrity glitches (garbled/missing bands).
    // See docs/tradeoff-curves/epd-refresh-latency.md.
    let bus = SpiBusDriver::new(spi, &Config::new().baudrate(20.MHz().into()))?;
    let cs = PinDriver::output(pins.gpio7)?;
    let dc = PinDriver::output(pins.gpio6)?;
    let rst = PinDriver::output(pins.gpio5)?;
    let busy = PinDriver::input(pins.gpio4, Pull::Down)?;
    let mut epd = Epd::new(bus, dc, rst, cs, busy);

    log::info!("EPD reset + init…");
    epd.reset()?;
    epd.init()?;
    // Async: the ~2.2 s full-refresh waveform runs while the SD mounts and the
    // note loads below. It writes both RAM banks, so it doubles as the baseline;
    // the first editor render waits it out (`wait_ready`) and replaces it.
    //
    // On the first boot after an OTA the splash carries a "keep powered" warning:
    // until `mark_running_firmware_valid` runs at cursor-ready, a reset rolls the
    // device back to the previous slot for good. Probed before the paint because
    // this frame is the only one on screen for that whole window.
    let splash = if firmware::infrastructure::ota::running_slot_pending_verify() {
        Frame::confirming_update()
    } else {
        Frame::splash()
    };
    epd.display_frame_async(splash.bytes())?;

    // SD after the EPD, against the doc's SD-first boot order: a dead panel
    // can't explain a missing card. Fatal-by-design rationale: `boot_storage`.
    let storage = boot_storage(&mut epd);
    sd_log::start();

    // Before the wizard gate — first-boot setup types on this keyboard.
    usb_kbd::start()?;

    // Device runtime config + the first-boot wizard gate. Whatever this block
    // yields is installed before the net thread spawns. Secrets stay out of the
    // log — only which keys exist.
    let (sys_loop, nvs, modem) = {
        use esp_idf_svc::eventloop::EspSystemEventLoop;
        use esp_idf_svc::nvs::EspDefaultNvsPartition;

        let sys_loop = EspSystemEventLoop::take()?;
        let nvs = EspDefaultNvsPartition::take()?;
        let mut modem = peripherals.modem;

        let card = match std::fs::read_to_string(CONF_PATH) {
            Ok(body) => conf::Conf::parse(&body),
            Err(_) => conf::Conf::default(),
        };
        let provided: Vec<&str> = conf::Field::ALL
            .iter()
            .filter(|f| !card.get(**f).trim().is_empty())
            .map(|f| f.conf_key())
            .collect();
        log::info!(
            "typoena.conf on card provides: {}",
            if provided.is_empty() { "nothing".into() } else { provided.join(", ") }
        );

        let effective = firmware::infrastructure::net::effective_conf_from(&card);
        let unconfigured = !effective.missing_required().is_empty() || !storage.repo_present();
        // `:setup` reboots into the wizard prefilled (the running editor can't
        // reclaim the radio from the net thread). One-shot: clear the marker on
        // read so a power-pull mid-setup boots the editor, not setup again.
        let setup_requested = storage.setup_requested();
        if setup_requested {
            storage.clear_setup_request();
        }
        let final_conf = if unconfigured || setup_requested {
            if unconfigured {
                log::info!("unconfigured card (conf incomplete or repo missing) — entering the onboarding wizard");
            } else {
                log::info!(":setup requested — reopening the wizard prefilled from the card conf");
            }
            // The wizard provisions the *card*, so it resumes from the card's own
            // state, never the baked fallback — which would skip the very steps a
            // blank card needs. `run` is opt-level 2; see its doc comment.
            match firmware::infrastructure::wizard_io::run(&mut epd, &storage, &card, setup_requested && !unconfigured, &sys_loop, &nvs, &mut modem) {
                Ok(c) => c,
                Err(e) => boot_halt(&mut epd, "Setup stopped", &format!("{e:#}")),
            }
        } else {
            card
        };
        firmware::infrastructure::net::set_card_conf(final_conf);
        (sys_loop, nvs, modem)
    };

    // Read before the boot buffer is chosen (`open_last_on_boot` decides which
    // file) and before the first render (`line_numbers` shapes the opening frame).
    let prefs = match storage.load_path(PREFS_PATH) {
        Ok(src) => Prefs::parse(&src),
        Err(_) => Prefs::default(),
    };
    log::info!("prefs: {prefs:?}");
    // Before anything reads the wall clock, so `localtime_r` — and thus the
    // `:inbox` note's dated name/title — reflects the local calendar day. Empty
    // (the default) leaves the ESP clock at UTC.
    if !prefs.timezone.is_empty() {
        clock_esp::apply_timezone(&prefs.timezone);
    }
    let (boot_path, boot_scope, saved) = boot_note(&mut epd, &storage, &prefs);

    // The net thread owns the Wi-Fi stack, brought up lazily on its first
    // request. On a cold clock that request is the runtime's own boot kick a
    // moment from now (`Runtime::new`), which dates `:inbox` without a fetch.
    let (net_tx, net_rx) = {
        use firmware::infrastructure::net::{run_net_service, NetOutcome, NetRequest, GIT_STACK};

        let (req_tx, req_rx) = std::sync::mpsc::channel::<NetRequest>();
        let (res_tx, res_rx) = std::sync::mpsc::channel::<NetOutcome>();
        // Core1 at priority 1, like the file walk (see `spawn_file_walk`): an
        // esp-idf `std::thread` defaults to priority 5 against the UI task's 1,
        // and the boot clock kick makes this thread — plus the Wi-Fi and lwIP
        // tasks it starts — run during the opening seconds of a session, when
        // the writer is already typing.
        let cfg = ThreadSpawnConfiguration {
            name: None,
            stack_size: GIT_STACK,
            priority: 1,
            inherit: false,
            pin_to_core: Some(Core::Core1),
            ..Default::default()
        };
        if let Err(e) = cfg.set() {
            log::warn!("net thread cfg (Core1, prio 1) FAILED ({e}); spawning at pthread default");
        }
        let spawned = std::thread::Builder::new()
            .name("net".into())
            .stack_size(GIT_STACK)
            .spawn(move || run_net_service(modem, sys_loop, nvs, req_rx, res_tx));
        if let Err(e) = ThreadSpawnConfiguration::default().set() {
            log::warn!("restoring default thread cfg FAILED ({e})");
        }
        spawned?;
        log::info!(
            "net thread up ({} KB stack); Wi-Fi comes up on its first request",
            GIT_STACK / 1024
        );
        (req_tx, res_rx)
    };

    let mut ed = Editor::with_file(boot_path.clone(), boot_scope, saved);
    ed.set_prefs(prefs);
    ed.set_version(firmware::infrastructure::ota::FW_VERSION);
    let snippets = match storage.load_path(SNIPPETS_PATH) {
        Ok(src) => match Snippets::parse(&src) {
            Ok(s) => s,
            Err(e) => {
                log::warn!("snippets parse FAILED ({e}); none loaded");
                Snippets::default()
            }
        },
        Err(_) => Snippets::default(),
    };
    log::info!("snippets: {} loaded", snippets.0.len());
    ed.set_snippets(snippets);

    // Seed both before the first render.
    ed.set_keyboard_present(usb_kbd::keyboard_present());
    ed.refresh_stats();

    // First editor render — the splash disappears here. `Panel::new` paints the
    // opening frame as a partial that first waits out the splash's waveform, so
    // the swap rides the partial instead of a second full refresh (~1.3 s saved).
    // The panel then owns the EPD and both reused framebuffers: a repaint never
    // allocates, so a background `:gs` can take the heap to the floor safely.
    let mut panel = Panel::new(epd, &mut ed)?;
    // Hardware entropy, so the face order differs run to run. Host builds skip
    // this and stay deterministic for the tests.
    panel.reseed_humor(unsafe { esp_idf_svc::sys::esp_random() });

    // Two clocks, ~1.4 s apart. `esp_log_timestamp()` counts from ~power-on — the
    // real cold-boot number. `esp_timer_get_time()` only starts after the
    // 2nd-stage bootloader + the ~0.74 s PSRAM memtest, so it is app-side init
    // only. "Cursor ready" = first editor frame on the panel.
    let total_ms = unsafe { esp_idf_svc::sys::esp_log_timestamp() };
    let app_ms = (unsafe { esp_idf_svc::sys::esp_timer_get_time() } / 1000) as u32;
    log::info!("boot: cursor ready — {total_ms} ms since power-on ({app_ms} ms app-side)");

    // Reaching cursor-ready is the health bar: on the first boot after an OTA
    // `:update` this cancels the pending rollback, otherwise it is a logged no-op.
    firmware::infrastructure::ota::mark_running_firmware_valid();

    // AFTER the first editor frame: the seconds-long readdir over SPI would
    // otherwise starve the boot-critical SD reads and delay the first paint.
    let files = EspFileWalk::new();
    files.request_rewalk();

    // Every adapter below runs on this single UI task, so `Rc` (not `Arc`) is enough.
    let card = Rc::new(storage);

    // The charger, on the I2C bus it shares with the expansion header. A board
    // that doesn't answer is not fatal — the machine runs with no battery
    // telemetry and a button that still works, which is exactly the bench rig.
    let charger = match I2cDriver::new(
        peripherals.i2c0,
        pins.gpio17,
        pins.gpio18,
        &I2cConfig::new().baudrate(400.kHz().into()),
    ) {
        Ok(bus) => Bq25896::new(bus)
            .inspect_err(|e| {
                log::warn!("no charger answered on I2C ({e}); running without battery telemetry")
            })
            .ok(),
        Err(e) => {
            log::warn!("I2C bus bring-up FAILED ({e}); running without battery telemetry");
            None
        }
    };
    let power: Box<dyn app::Power> =
        Box::new(EspPower::new(rails, pins.gpio21, charger, card.clone())?);

    let net: Box<dyn app::NetService> =
        Box::new(NetService::new(card.clone(), net_tx, net_rx));
    let system: Box<dyn app::System> = Box::new(EspSystem(card.clone()));

    // The only exits are `:reboot`/`:setup`, which restart the device — so `run`
    // never returns.
    let mut runtime = Runtime::new(
        ed,
        panel,
        Box::new(usb_kbd::UsbKeyboard),
        Box::new(SdStorage(card.clone())),
        net,
        Box::new(EspClock),
        system,
        power,
        Box::new(files),
    );

    if std::path::Path::new(panic_scribe::EMERGENCY_PATH).exists() {
        log::warn!(
            "panic dump from a previous crash present: {}",
            panic_scribe::EMERGENCY_PATH
        );
    }
    // Arm the panic scribe now that `runtime` has its final address (`run`
    // borrows it until the device reboots, so it never moves again).
    panic_scribe::arm(&raw const runtime as *const (), |p| {
        // SAFETY: `arm`'s contract — only ever called back on THIS thread,
        // halted at the panic site, so the `&mut` inside `run` is suspended and
        // the read cannot race. The `'static` stands in for the Epd's true
        // pin-borrow lifetime: this stack frame never returns.
        let rt = unsafe { &*(p as *const Runtime<Epd<'static>>) };
        rt.scribe_snapshot().map(|(path, text)| (path.to_string(), text.to_string()))
    });
    runtime.run()
}

/// Mount the SD card, or halt with the reason on the panel. A missing CARD is
/// fatal by design: the note is the whole point of the appliance, so we refuse to
/// run in a state where the next save could destroy it. A missing REPO is not
/// fatal — the wizard gate in `main` enters first-boot setup instead.
fn boot_storage(epd: &mut Epd) -> Storage {
    // The only production mount, so its budget is the editor's as well as the
    // net thread's: libgit2 keeps the pack + idx descriptors open across a sync,
    // which overruns a tight budget. See `storage_sd::MAX_FILES_GIT`.
    match Storage::mount_for_git() {
        Ok(s) => s,
        Err(e) => boot_halt(epd, "SD card not ready", &format!("{e:#}")),
    }
}

/// Choose and load the boot buffer. With `open_last_on_boot` set and a marker
/// naming a still-existing file (`Storage::last_file`), resume that file;
/// otherwise the default note. Only the default note is fatal (`boot_halt`) —
/// a stale or unreadable last file falls back rather than refusing to boot.
fn boot_note(epd: &mut Epd, storage: &Storage, prefs: &Prefs) -> (String, Scope, String) {
    if prefs.open_last_on_boot {
        if let Some(path) = storage.last_file() {
            match storage.load_path(&path) {
                Ok(text) => {
                    log::info!("boot: resumed {path} ({} bytes)", text.len());
                    let scope = if path.starts_with(LOCAL_DIR) { Scope::Local } else { Scope::Tracked };
                    return (path, scope, text);
                }
                // Unreadable (e.g. grown past MAX_FILE_BYTES on a computer) —
                // the default note still boots.
                Err(e) => log::warn!("boot: can't resume {path} ({e:#}); falling back to {NOTES}"),
            }
        }
    }
    let note = match storage.load() {
        Ok(text) => text,
        Err(e) => boot_halt(epd, "Could not read your note", &format!("{e:#}")),
    };
    log::info!("boot: loaded {} bytes from {NOTES}", note.len());
    (NOTES.to_string(), Scope::Tracked, note)
}

/// Show a terminal boot error on the panel and idle forever. Rebooting into the
/// same missing card would just thrash, so we stop and explain instead.
fn boot_halt(epd: &mut Epd, headline: &str, detail: &str) -> ! {
    log::error!("boot halt — {headline}: {detail}");
    if let Err(e) = show_message(epd, &format!("{headline}\n\n{detail}\n")) {
        log::error!("(could not paint the boot error either: {e:#})");
    }
    loop {
        FreeRtos::delay_ms(1000);
    }
}

/// Render a plain full-frame message by borrowing the editor purely as a
/// text-layout engine, so boot failures surface on the panel, not a dead screen.
fn show_message(epd: &mut Epd, msg: &str) -> anyhow::Result<()> {
    let frame = Editor::with_text(msg.to_string()).draw(false);
    epd.display_frame(frame.bytes())?;
    Ok(())
}

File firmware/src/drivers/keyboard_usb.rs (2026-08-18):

//! USB host HID boot keyboard → key-event queue.
//!
//! Drives the ESP-IDF USB Host Library directly through the raw `esp-idf-sys`
//! bindings (the convenience HID class driver is a managed component that isn't
//! vendored in mainline, and a boot keyboard doesn't need it). `start()`
//! installs the host stack, spawns the daemon + client event pumps on their own
//! threads, and returns immediately; decoded key-down events are pushed onto a
//! queue the caller drains with `next_key()`. This keeps the USB pumps off the
//! main thread so the main thread can own the e-paper panel.
//!
//! On attach it opens the device, dumps its descriptors, claims the boot
//! keyboard interface (interface 0 / EP 0x81 / 8-byte reports, confirmed by
//! Spike 4's enumeration of VID:PID 19f5:3255), switches it to boot protocol,
//! and polls the interrupt-IN endpoint. Each report is edge-detected against
//! the previous one so a held key yields a single key-down, then translated
//! through a US QWERTY layout.
//!
//! Logging goes over the CP2102 UART bridge (console = UART0), independent of
//! the USB PHY, so the host library and the serial monitor coexist.

use std::collections::VecDeque;
use std::ffi::c_void;
use std::ptr;
use std::sync::atomic::{AtomicBool, AtomicU32, AtomicU8, Ordering};
use std::sync::{Mutex, MutexGuard, OnceLock};

use esp_idf_svc::sys::esp;
use esp_idf_svc::sys::{
    usb_config_desc_t, usb_device_desc_t, usb_device_handle_t, usb_host_client_config_t,
    usb_host_client_event_msg_t, usb_host_client_event_t_USB_HOST_CLIENT_EVENT_DEV_GONE,
    usb_host_client_event_t_USB_HOST_CLIENT_EVENT_NEW_DEV, usb_host_client_handle_events,
    usb_host_client_handle_t, usb_host_client_register, usb_host_config_t, usb_host_device_close,
    usb_host_device_open, usb_host_get_active_config_descriptor, usb_host_get_device_descriptor,
    usb_host_install, usb_host_interface_claim, usb_host_interface_release,
    usb_host_lib_handle_events, usb_host_transfer_alloc, usb_host_transfer_free,
    usb_host_transfer_submit, usb_host_transfer_submit_control, usb_print_config_descriptor,
    usb_print_device_descriptor, usb_transfer_status_t_USB_TRANSFER_STATUS_COMPLETED,
    usb_transfer_t, EspError, ESP_INTR_FLAG_LEVEL1,
};

/// A decoded key-down event, re-exported from the `keymap` crate. The decode
/// logic (edge detection + US-QWERTY translation) lives there — pure, with no
/// esp/std deps — so it is host-testable and fuzzable off the xtensa target.
/// This module only bridges it to the USB transport. See MEMORY_AUDIT.md.
pub use keymap::Key;

/// The [`hal::Keyboard`] port over this module's global USB-host key queue.
/// Zero-sized: all state lives in the module statics, so every instance reads
/// the one shared queue. Construct after [`start`]; the run loop drives the
/// editor through this contract instead of the free functions below.
pub struct UsbKeyboard;

impl hal::Keyboard for UsbKeyboard {
    fn next_key(&mut self) -> Option<Key> {
        next_key()
    }

    fn keyboard_present(&self) -> bool {
        keyboard_present()
    }
}

/// Boot-keyboard parameters, confirmed by Spike 4's enumeration.
const KBD_INTERFACE: u8 = 0;
const KBD_ALT_SETTING: u8 = 0;
const KBD_EP_IN: u8 = 0x81;
const BOOT_REPORT_LEN: usize = 8;

/// HID class control requests. bmRequestType 0x21 = host→device | class |
/// interface recipient; wIndex (byte 4) = the interface number.
const SET_PROTOCOL_BOOT: [u8; 8] = [0x21, 0x0b, 0x00, 0x00, KBD_INTERFACE, 0x00, 0x00, 0x00];
const SET_IDLE_INFINITE: [u8; 8] = [0x21, 0x0a, 0x00, 0x00, KBD_INTERFACE, 0x00, 0x00, 0x00];

/// Address of a freshly-attached device, published by the client event
/// callback and consumed by the client loop. 0 means "nothing pending".
static NEW_DEV_ADDR: AtomicU8 = AtomicU8::new(0);
/// Set when the open device is unplugged.
static DEV_GONE: AtomicBool = AtomicBool::new(false);
/// Whether a keyboard is currently open (attached + set up). Unlike `DEV_GONE`
/// (a one-shot detach event the client loop consumes), this is the persistent
/// connection state the side-panel disconnect flag reads via `keyboard_present`.
static KBD_PRESENT: AtomicBool = AtomicBool::new(false);
/// Control-transfer completion, published by `ctrl_cb` to the setup routine.
static CTRL_DONE: AtomicBool = AtomicBool::new(false);
static CTRL_STATUS: AtomicU32 = AtomicU32::new(0);
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

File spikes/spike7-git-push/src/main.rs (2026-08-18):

//! Spike 7 (desktop half) — `libgit2` add → commit → push over HTTPS + PAT.
//!
//! ## Why libgit2 and not gitoxide
//!
//! [ADR-004] chose `gix` and named Spike 7 its kill-switch: "if [gix smart-HTTP
//! push] fails on the device, we fall back to `libgit2-sys`." Before writing a
//! line of gix code, gitoxide's own crate-status doc settles it — gix has
//! send-pack *plumbing* but supports push only over `file://` and `ssh://`;
//! **push over HTTP(S) is not implemented**. Since [ADR-005] fixes auth as
//! HTTPS + PAT, the kill-switch condition is met at the library level, so this
//! spike proves the fallback: `libgit2` via the `git2` crate.
//!
//! ## What this proves (desktop)
//!
//! The exact sequence the on-device `git` module will run (v0.1 technical →
//! `git` module), against a real repository:
//!
//!   1. open the working copy
//!   2. stage everything — `git add --all` semantics, so deletions propagate
//!      too (matters for v0.5 file-delete → next Push's staged set)
//!   3. short-circuit when nothing is staged ("nothing to push")
//!   4. commit with the configured author, message = an ISO-8601 timestamp
//!   5. push HEAD to `origin/<branch>` over HTTPS with a PAT in the credential
//!      callback (never logged)
//!   6. on push rejection (remote moved): fetch + `pull --no-edit`
//!      (fast-forward or a clean merge), then retry the push once
//!
//! ## What it does NOT prove
//!
//! The real remaining risk moved with the kill-switch: **can libgit2
//! cross-compile to `xtensa-esp32s3-espidf` against esp-idf's mbedtls?** That
//! is the next on-device gate — the very cross-compile pain gix was picked to
//! avoid. This desktop pass de-risks the *API and the git mechanics*; the
//! device build is a separate spike.
//!
//! ## Run
//!
//! Local remote (no credentials — proves the mechanics end to end):
//!   cargo run -- /path/to/working-copy      # origin is a file:// bare repo
//!
//! Real GitHub repo (proves HTTPS + PAT):
//!   set -a; . ./.env; set +a
//!   cargo run -- "$TW_REPO_PATH"
//!
//! [ADR-004]: ../../docs/adr.md
//! [ADR-005]: ../../docs/adr.md

use std::cell::RefCell;
use std::rc::Rc;

use anyhow::{bail, Context, Result};
use chrono::Utc;
use git2::{
    build::CheckoutBuilder, Commit, Cred, CredentialType, FetchOptions, IndexAddOption,
    PushOptions, RemoteCallbacks, Repository, Signature,
};

/// Runtime config, mirroring the build-time `TW_*` env the firmware bakes in.
struct Config {
    repo_path: String,
    /// GitHub username + PAT for HTTPS basic auth. Both `None` → a local
    /// (`file://`) remote that needs no credentials.
    gh_user: Option<String>,
    pat: Option<String>,
    author_name: String,
    author_email: String,
    /// Optional override for `origin`'s URL (the HTTPS remote baked in at build
    /// time). Unset → use the working copy's existing `origin` as-is.
    remote_url: Option<String>,
}

impl Config {
    fn from_env_and_args() -> Result<Self> {
        let repo_path = std::env::args()
            .nth(1)
            .or_else(|| non_empty("TW_REPO_PATH"))
            .context("no working copy: pass a path as argv[1] or set TW_REPO_PATH")?;
        Ok(Self {
            repo_path,
            gh_user: non_empty("TW_GH_USER"),
            pat: non_empty("TW_PAT"),
            author_name: non_empty("TW_AUTHOR_NAME").unwrap_or_else(|| "Typoena".into()),
            author_email: non_empty("TW_AUTHOR_EMAIL")
                .unwrap_or_else(|| "typoena@example.com".into()),
            remote_url: non_empty("TW_REMOTE_URL"),
        })
    }

    fn signature(&self) -> Result<Signature<'static>> {
        Signature::now(&self.author_name, &self.author_email).context("building commit signature")
    }
}

/// An env var, treated as absent when empty (build.rs emits "" for unset vars,
/// so the firmware uses the same convention).
fn non_empty(key: &str) -> Option<String> {
    std::env::var(key).ok().filter(|v| !v.is_empty())
}

fn main() {
    match run() {
        Ok(summary) => println!("✅ Spike 7 (desktop) complete — {summary}"),
        Err(e) => {
            eprintln!("❌ Spike 7 (desktop) failed: {e:?}");
            std::process::exit(1);
        }
    }
}

fn run() -> Result<String> {
    let cfg = Config::from_env_and_args()?;
    let repo = Repository::open(&cfg.repo_path)
        .with_context(|| format!("opening working copy at {}", cfg.repo_path))?;
    log(&format!("opened {}", cfg.repo_path));

    if let Some(url) = &cfg.remote_url {
        ensure_origin(&repo, url)?;
    }

    // Stage + commit, or short-circuit.
    let branch = match commit_if_changes(&repo, &cfg)? {
        Some(b) => b,
        None => return Ok("nothing to push (index matches HEAD)".into()),
    };
    let refspec = format!("refs/heads/{branch}:refs/heads/{branch}");

    // Push, with one pull-and-retry on rejection (the remote-moved case).
    match push_once(&repo, &cfg, &refspec) {
        Ok(()) => Ok(format!("pushed {branch} to origin")),
        Err(first) => {
            log(&format!(
                "push rejected ({first}); pull --no-edit then retry once"
            ));
            pull_no_edit(&repo, &cfg, &branch).context("pull --no-edit after rejected push")?;
            push_once(&repo, &cfg, &refspec).context("retry push after pull")?;
            Ok(format!("pushed {branch} to origin (after pull + merge)"))
        }
    }
}

/// Point `origin` at `url`, creating the remote if the working copy has none.
fn ensure_origin(repo: &Repository, url: &str) -> Result<()> {
    match repo.find_remote("origin") {
        Ok(_) => repo
            .remote_set_url("origin", url)
            .context("remote_set_url origin")?,
        Err(_) => {
            repo.remote("origin", url)
                .context("creating origin remote")?;
        }
    }
    log(&format!("origin → {url}"));
    Ok(())
}
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

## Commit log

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2026-07-04 feat(firmware): read keycodes from a USB HID boot keyboard
    Spike 4. Drive the ESP-IDF USB Host Library directly through the raw
    esp-idf-sys bindings (the convenience HID class driver is a managed
    component not vendored in mainline, and a boot keyboard doesn't need
    it). On attach, src/usb_kbd.rs enumerates the device and dumps its
    descriptors, claims the boot-keyboard interface, sends SET_PROTOCOL(boot)
    and SET_IDLE(0), then polls the interrupt-IN endpoint and decodes each
    8-byte report into modifiers + keycodes logged over UART.
    main.rs becomes the Spike 4 harness; the epd module is kept compiled
    (allow(dead_code)) so it doesn't bit-rot. Verified on hardware with a
    19f5:3255 keyboard: lette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
    [main.rs, usb_kbd.rs]
2026-07-04 feat(firmware): add partial refresh to the EPD driver
    display_frame_partial writes the new image to bank 0x24, runs GxEPD2's
    partial waveform (_Update_Part: 0x3C/0x80, 0x21/0x00,0x10, 0x22/0xFF,
    0x20), then syncs bank 0x26 so the next partial has a correct baseline.
    Like GxEPD2 for this dual-controller panel, the update covers the full
    panel with the partial waveform — no windowing, since the waveform time
    dominates. Much faster than a full refresh and without the flashing.
    [epd.rs]
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2026-07-05 feat(firmware): add on-device git push spike (git_push)
    Wi-Fi + SNTP + flash-FAT + libgit2 in one bench binary: init a fresh working
    copy, commit, and push a per-boot device/<unix> branch over mbedTLS HTTPS with
    PAT auth. Gated behind the `git` feature; built/flashed via `just flash-git-push`.
    Status: local git init verified on hardware; the ODB-write fix and the full
    push are not yet confirmed end-to-end on device. Cert verification is bypassed
    in the push callback (spike shortcut) -- real trust-store wiring must land
    before this leaves the bench.
    [git_push.rs]
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2026-07-07 fix(firmware): recover git_sync from a leftover clone dir
    859c478 aborted if /spiflash/repo already existed — libgit2 refuses to
    clone into a non-empty dir (code=Exists). Remove a writable stale/partial
    clone and re-clone.
    Milestone #2A now hardware-verified end to end: clone (boot 1) + persistent
    open + fast-forward push (boot 2) against origin/main, on the 96 KB git
    thread, min heap 6.8 MB — clone/checkout fit the stack, no bump needed.
    Known limit: the remove only works on a *writable* leftover. libgit2 marks
    objects/packs read-only and FATFS won't f_unlink a read-only file (EACCES);
    POSIX chmod does not clear AM_RDO on esp-idf's FATFS VFS (verified). So
    re-cloning over a run that w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
    [git_sync.rs]
2026-07-07 fix(firmware): delete repo dir via path-based recursion, not remove_dir_all
    std::fs::remove_dir_all deletes race-free via the openat/unlinkat/fdopendir
    family; esp-idf's path-based FATFS VFS doesn't implement those, so it fails
    with EACCES on the first entry. That looked like a read-only-attribute
    problem but wasn't. A plain read_dir -> remove_file/remove_dir walk
    (remove_tree) uses only what FATFS supports.
    Hardware-verified: a diagnostic recursive delete removed the whole
    /spiflash/repo (every entry reported writable, ro=false) then re-cloned +
    pushed, twice. Wire remove_tree into both the RECLONE_EACH_BOOT reset and
    the stale-clone recovery.
    The p_open/p_creat shim (39e1155) stays: it k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
    [git_sync.rs]
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2026-07-11 chore(sd): drop Spike 3 CMD59 diagnostic logging
    The per-command sdmmc/sdspi DEBUG logs only existed to diagnose the CMD59
    init failure, now resolved (verified 2026-07-11). Remove the build-time log
    ceiling and the runtime esp_log_level_set block.
    [sd_fat.rs]
2026-07-11 fix(sd): unlink target before f_rename to overwrite on FAT
    FatFS's f_rename returns FR_EXIST on an existing destination — unlike POSIX
    rename(2) it won't replace it, so re-running the round-trip failed at rename.
    Unlink the target first (tolerating a missing one for the first save). This
    opens a crash window the real persistence module must close with *.tmp boot
    recovery (ADR-007).
    [sd_fat.rs]
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2026-07-11 fix(sd): correct stale shared-bus log strings to SPI3
    The boot banner, success line, and round-trip payload still said
    "shared SPI2" / "shared bus" after the move to SPI3. Cosmetic only —
    serial output now matches the dedicated-bus wiring.
    [sd_fat.rs]
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2026-07-11 fix(firmware): harden :sync publish — skip macOS sidecars, fast-forward first
    Two robustness fixes surfaced by commit 07d87772 (the first editor-driven
    :sync), which shipped three macOS AppleDouble files to typoena-test:
    - Staging filter: add_all now runs a per-path callback that skips ._* and
    .DS_Store, so Finder/Spotlight cruft on the FAT card never lands in a
    commit. Device-level, so it protects every repo without a per-repo
    .gitignore.
    - Pre-commit fast-forward: publish_once fetches origin and, if the local
    branch is behind, fast-forwards to it via a MIXED reset before committing.
    This lets the device absorb a foreign push (e.g. the sidecar cleanup) and
    fast-forward clean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
    [git_sync.rs]
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2026-07-11 feat: add multi-file buffer foundation (v0.5 slice 1)
    Rework the single Effect return into a drained effect queue
    (Save{path,scope,contents} / Load / Publish / Pull) so one action can
    ask the host for several ordered steps: opening a non-resident file
    queues a Save of the outgoing dirty buffer then a Load of the target.
    Keep the active buffer's fields inline on Editor and park inactive
    buffers in a small LRU (<=3 resident = active + 2); switching back to a
    resident buffer restores its caret/scroll/undo without touching the SD.
    A dirty parked buffer is saved before eviction, so nothing leaves RAM
    unsaved. `:e <path>` opens by prefix (/sd/repo -> Tracked, /sd/local ->
    Local); `:sync` is refus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
    [main.rs, persistence.rs]
2026-07-11 feat(persistence): end saved files with a trailing newline
    Add the POSIX line terminator on save and strip it on load, so files
    written by the editor no longer trip git's "No newline at end of file".
    Done at the persistence choke point, not in :fmt: the editor buffer is
    newline-free by design (rows = #\n + 1), so a trailing '\n' in the buffer
    would render a phantom blank last line. save_path adds exactly one '\n'
    (guarded against doubling); load_path strips one back off so the buffer
    stays newline-free and round-trips byte-stable.
    Update the sd_fat spike payload to be newline-free so its byte-identity
    round-trip assertion holds under the new normalizing contract.
    [persistence.rs, sd_fat.rs]
2026-07-12 fix(persistence): show a saved note's trailing newline as an empty line
    Read notes verbatim and insert the final newline only when it is missing,
    instead of stripping the terminator on load and appending it unconditionally
    on save. The editor's `rows = #\n + 1` model then renders a file's POSIX
    terminator as a visible trailing blank line — what a writer expects: open a
    note and see (and land the caret on) the empty line the newline stands for.
    Supersedes the strip-on-load / unconditional-append handling that shipped
    with the prefs work (c535864), which kept the buffer newline-free and hid the
    terminator. Load + save are now an identity round-trip for any device-written
    file (all end in '\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
    [persistence.rs, sd_fat.rs]
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2026-07-12 feat(firmware): read .typoena.snippets.json at boot into set_snippets
    Mirror the prefs boot-read: load the git-tracked snippet library from the
    SD repo, parse it with Snippets::parse, and hand it to the editor before
    the first render. Missing/unreadable/malformed is non-fatal (no snippets,
    editor runs). Verified serde_json builds for xtensa (cargo check, 0.6.0).
    [main.rs]
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2026-07-12 feat(sync): commit by splicing journaled dirty paths onto HEAD
    The index pipeline (add_all → index.write → write_tree) is O(N_tree)
    and cannot commit the real 1179-file / 570 MB-pack clone (index.write
    measured up to 611 s on FAT's racy-clean re-hash). stage_and_commit is
    now an O(depth) TreeBuilder splice of exactly the paths the editor
    saved or deleted — ~2-2.8 s on the real clone — with the working tree
    as source of truth (existing file → insert, missing → remove).
    Storage records those repo-relative paths on every save/delete and
    journals them to /sd/.typoena-dirty (atomic, only on growth), so a
    power pull can't strand a saved-but-unpublished note now that nothing
    walks the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
    [git_sync.rs, main.rs, persistence.rs]
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2026-07-13 feat: wrap palette selection; fix push classing, file walk, card load
    - Palette Ctrl-N/P (and half-page keys) wrap around the result list
    instead of clamping at the ends; tests updated to the new semantics.
    - try_push maps libgit2's negotiation-time NotFastForward error to
    PushFailure::Rejected so the reconcile path runs instead of failing
    as a transport error.
    - walk_files decodes esp-idf d_type values (DT_REG=1/DT_DIR=2) that
    libc 0.2.178's generic unix table misreads as fifo/chardev — the
    palette walk was silently dropping every file on the card.
    - `just load` refuses to mirror over unpublished device edits listed
    in the card's .typoena-dirty journal (backup+discard via
    TW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
    [git_sync.rs, main.rs]
2026-07-13 fix(sync): survive push heap exhaustion and instrument the push path
    Run 4 (2026-07-13): remote.push() consumed ~6 MB of PSRAM over 66 s and
    the UI thread aborted on Frame::new_white's per-draw vec![0xFF; 26928].
    Run 5 confirmed the UI now survives, but the push still exhausts both
    pools (a ~7 KB inflateInit fails inside the pack build) and the heap
    telemetry never fired — hence the telemetry rework.
    - display/editor: Editor::draw_into() renders into a caller-owned
    Frame; main.rs keeps two boot-time frames (shown/back) and mem::swaps
    on success, so steady-state repaints never allocate.
    - git_sync: odb cache capped at 1 MB via raw libgit2-sys opts (git2
    0.20 doesn't wrap the total ca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
    [git_sync.rs, main.rs]
2026-07-13 fix(sync): budget mmaps at 64KB/1.5MB, trace the push heap live
    Runs 7-9 on the real repo (2026-07-13): esp_map live-bytes wired into
    log_push_heap plus a 5s sibling heartbeat thread proved the push OOM was
    libgit2's mmaps — ~3.4MB of whole-file .idx/multi-pack-index maps living
    OUTSIDE the mwindow budget, plus windows at the (working) 4MB soft limit,
    an impossible budget on the 8MB pool. Shrinking to 64KB windows / 1.5MB
    mapped limit left 4.5MB min-ever free and cut marking reads 4x; with the
    card repacked to a single pack, the first-ever real-repo push landed
    (6713ea6e, :sync 24.1s end-to-end).
    The heartbeat stays for now (the marking phase fires no libgit2 callbacks,
    so it is the only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
    [git_sync.rs]
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2026-07-13 feat(sync): :gl pull — fetch + fast-forward only on the git thread
    The git channel now carries GitRequest::{Publish,Pull} with a shared
    ensure_online preamble (Wi-Fi/clock/TLS once per session). pull_once
    fetches origin — refreshing the tracking ref so the radio-free
    up-to-date check stays honest — and maps four shapes: up to date,
    LocalAhead (stranded commit, :sync's job), clean fast-forward,
    Diverged (refused; no merge on the device). The fast-forward is a SAFE
    checkout then ref move: it refuses to overwrite content that differs
    from HEAD, the belt under the UI gate that refuses :gl while the dirty
    journal is non-empty. A RAM-dirty buffer doesn't gate — its edits win
    (last-writer-w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
    [git_sync.rs, main.rs, persistence.rs]
2026-07-13 feat(boot): async splash refresh + background palette file walk
    The splash's ~2.2s full-refresh waveform now runs while the SD mounts
    and the note/prefs load (Epd::display_frame_async + wait_ready guard on
    every public display call), and the 4.3s palette walk moves to a 16KB
    background thread whose result lands in the idle branch — the first
    editor frame no longer waits on non-mandatory work. The post-pull
    re-walk rides the same channel, removing a 4.3s UI stall after :gl.
    Also: rustfmt pass on sd_bench, drop the spike-9 log line in splash.
    [epd.rs, main.rs, splash.rs]
2026-07-14 fix(sync): apply the pull fast-forward as a tree diff, not checkout_tree
    First on-device ff attempt (2026-07-14) crashed: libgit2's SAFE
    checkout iterates the whole working directory (readdir over SPI on all
    ~1100 files) to find dirty files — the same O(tree) wall the splice
    commit avoids — and with fetch memory still resident it exhausted
    internal DRAM; esp-idf's spi_master then NULL-derefs on its own
    failed-DMA-alloc path instead of erroring.
    apply_tree_diff mirrors the splice: diff_tree_to_tree skips identical
    subtree OIDs in memory, then writes/deletes exactly the changed paths
    (unlink+tmp+rename — FAT rename won't overwrite). Belt kept O(changed):
    any to-be-clobbered file whose c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
    [git_sync.rs]
2026-07-14 perf(sync): reuse the TLS session and skip the pull's needless fetch
    Two halves of the connection-cost lever (first on-device pull: 9.7s
    fetch to learn 'up to date'; a rejected-push :sync runs three full
    handshakes):
    - esp_mbedtls_stream.c caches the mbedTLS session at stream close and
    offers it on the next connect to the same host — the server then
    skips the certificate exchange and most of the key exchange. Second
    vendor delta, single git thread, best-effort (any refusal falls back
    to a full handshake).
    - pull_once now ls-refs first: the ref advertisement alone answers
    'anything new?', so up-to-date and local-ahead return without ever
    entering pack negotiation, and a needed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
    [git_sync.rs]
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2026-07-14 feat(sync): skip media paths in the pull apply
    A pulled image blob is materialized whole in RAM before landing on the
    card — history holds 16MB PNGs and a 38MB mp3 against 8MB PSRAM, the
    last OOM path in :gl. The device never renders media, and the splice's
    explicit-path staging means a missing image can't be committed as a
    deletion, so media become invisible to apply_tree_diff: never written,
    deleted, or belt-hashed. Blobs still arrive in .git via fetch; the
    card's working copy stays text-only and goes deliberately image-stale.
    [git_sync.rs]
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2026-07-14 feat(firmware): boot into the last-active file
    Record the active buffer in a device-local marker (/sd/.typoena-last,
    beside the dirty journal) on every switch; when open_last_on_boot is set,
    boot resumes it. Prefs are now read before the boot note is chosen.
    A missing/garbled/stale marker falls back to notes.md — only the default
    note stays boot-fatal.
    [main.rs, persistence.rs]
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2026-07-15 feat(installer): Sign in with GitHub replaces hand-created PATs
    ^G on the Configure step runs the Typoena GitHub App's device flow: request
    a one-time code via system curl, show it big, auto-open
    github.com/login/device, and poll in the background (pending/slow_down
    honored, Esc cancels) until the ghu_ token fills the token field. The token
    speaks the same x-access-token basic auth as a PAT, so the clone path and
    firmware are untouched; pasting a fine-grained PAT stays as the fallback.
    The panel is modal on Configure — plain Esc/n/q cancel, ^N/^P are inert so
    a reflexive step jump can't kill the flow. If the app has user-token expiry
    on, the success snackbar flags the token lifetime.
    Als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
    [main.rs]
2026-07-15 feat(installer): accept remote-URL shorthand
    The Git remote field now takes you/notes, you/notes.git,
    github.com/you/notes, and SSH pastes (git@host:path, ssh://host/path) —
    all expanded to the canonical HTTPS clone URL by expand_remote_url, with
    a live '→ will use …' hint under the field. The conf and the clone only
    ever see the expanded form (the device's libgit2 is HTTPS-only, and an
    SSH-shaped origin on the card is a known push blocker). Full http(s) URLs
    pass through untouched; --dry-run-sd accepts the same shorthand.
    [main.rs]
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2026-07-16 fix(firmware): resume wizard from card state, not baked config
    The boot gate uses the card-over-baked effective conf to decide whether
    to run the wizard, but it also handed that merged conf to the wizard as
    its resume state. On a device with baked dev values (env!("TW_*")), a
    blank card then skipped straight to the repo step because Wi-Fi and the
    token were already "present" from the fallback — no interactive screen
    ever appeared. The wizard provisions the card, so it must resume from
    the card's own state; the gate keeps using the effective conf.
    [main.rs]
2026-07-16 feat(wizard): pick the Wi-Fi SSID from a device scan
    The wizard now scans on entry and shows nearby networks as a filterable
    pick list, so the SSID is selected rather than typed; only the password
    is typed (and it is shown by default). Esc drops to manual entry for a
    hidden or missed network, seeded with the filter.
    Driver-side: scan_wifi builds the radio once (new ensure_radio helper),
    starts a default station config, scans, then stops so the existing join
    path's start() runs from a clean state. Results are deduped by SSID
    (keeping the strongest signal), hidden networks dropped, strongest-first.
    Also records the deferred SoftAP companion-webapp direction in the spec.
    [wizard_io.rs]
2026-07-16 fix(wizard): pre-spawn the clone worker before Wi-Fi to avoid ENOMEM
    The clone thread failed to spawn on-device ("pthread: Failed to create
    task! / Not enough space") because its 96 KB stack is allocated from
    internal DRAM, and by the clone step Wi-Fi + the device-flow TLS have
    fragmented that pool — no contiguous 96 KB block is left. Total capacity
    is fine (a push runs the same 96 KB stack alongside Wi-Fi + TLS), so this
    is an allocation-order problem, not a shortage.
    Spawn the clone worker at the top of the wizard, before any radio work
    (the same trick the git service uses: grab the stack at boot, before
    Wi-Fi). It parks on a request channel through Wi-Fi/sign-in/repo-list,
    then runs th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
    [wizard_io.rs]
2026-07-16 fix(wizard): install TLS trust store and retry the clone cleanly
    The wizard's clone_repo runs before the git service thread, which is
    where ensure_online normally installs the embedded GitHub CA bundle for
    libgit2's mbedTLS stream. Without it the clone rejected github.com as
    NOT_TRUSTED (0x08) even though the device-flow POSTs to the same host
    validated (those use esp-idf's own bundle). Install the trust store in
    clone_repo itself; Wi-Fi and the clock are already up from the device
    flow, so only the CA bundle was missing.
    Also make the origin remote idempotent: a failed attempt left /sd/repo
    init'd with origin added, so a retry died at "remote 'origin' already
    exists". Reuse or repoint it i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
    [git_sync.rs]
2026-07-16 feat(installer): make just wipe headless with --no-eject
    The --wipe TUI took over the terminal for every bench reformat. Default
    to a headless run: print the target (device, size, unpublished edits),
    ask once y/N, then erase. --no-eject leaves the fresh volume mounted so
    `just wipe --no-eject && just wifi-seed` chains without a re-insert; -y
    skips the prompt; --ui keeps the old full-screen picker. The justfile
    recipes pass all args straight through.
    [main.rs]
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2026-07-19 feat(wizard): erase and dedicate a bring-your-own card on consent
    A blank or foreign card (no typoena.conf, no /sd/repo) now enters a
    consent gate (Wizard::adopt_blank_card -> Screen::Consent) instead of
    silently provisioning: Enter erases the whole card (Storage::wipe_card)
    and dedicates it to Typoena, then walks into the normal Wi-Fi flow; Esc
    declines (Effect::Decline) and the driver halts without touching it. A
    power-pull mid-onboarding writes conf fields, so a resume no longer
    matches the gate.
    Also restructures radio bring-up so it survives that flow: run takes
    start by reference, and the radio is built lazily the first time an
    effect needs Wi-Fi in a non-inlined build_radio fed the o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
    [main.rs, storage_sd.rs, wizard_io.rs]
2026-07-21 feat(firmware): fast partial waveform experiment (0x32 custom LUT)
    reMarkable-inspired "A2" lever to cut the ~490 ms per-keystroke typing
    latency floor: a hand-authored short partial waveform written to the
    SSD1683 via 0x32, used in place of the factory OTP partial. Three
    guardrails: scoped to the additive windowed path only (windowed-fast),
    a 2x-tighter longevity full-refresh cadence while active
    (FULL_REFRESH_EVERY_FAST), and a default-off `fast_partial` pref.
    Wiring: `Screen::display_frame_partial_window_fast` port (default
    delegates to the normal partial, so mock/demo are unaffected), driver
    override loading the LUT into both controllers + 0xCF activation, and
    render-engine routing with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
    [screen_epd.rs]
2026-07-21 feat(firmware): swap in real Good Display GDEY0579T93 partial waveform
    Replace the placeholder 153-byte Waveshare 1.54"/SSD1681 partial LUT
    (which never darkened this panel — 2026-07-19 bench) with the panel's own
    LUT_DATA_part (233 bytes) from Good Display's SSD1683 reference driver,
    archive S-GDEY0579T93-FP(LUT)-20250814.
    Corrects the four defects the reference now proves were behind the
    dead-end run: 0x32 wants 227 bytes not 153, the phase content was for the
    wrong panel, the drive voltages were wrong (EOPT=0x06, VSH2=0xA8,
    VCOM=0x00), and the 0x37 display-option write was omitted.
    Drops FAST_PHASE0_FRAMES (the real LUT embeds per-group timing in its
    7-byte rows). Deliberately skips t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
    [screen_epd.rs]
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2026-07-21 feat(firmware): keep-hot charge-pump experiment + re-scope validated comments
    Adds FAST_PART_KEEP_HOT (default true; revert = flip to false): fast partials use
    trigger 0xCC (no power-down) instead of 0xCF, so the charge pump stays energized
    across a typing burst and keystrokes 2..N skip the booster ramp. Hot time is bounded
    by the every-32 full refresh + any factory/idle refresh (all carry the power-down
    bits), so it can't stay hot indefinitely. UNTESTED; needs a real idle power-off
    before it could ship — this is a bench toggle.
    Also re-scopes two now-stale comments on FAST_PARTIAL_LUT: it was marked NOT YET
    VALIDATED (now validated — FR 0x08, ~266ms, solid black, no ghost), and the
    pha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
    [screen_epd.rs]
2026-07-21 revert(firmware): default keep-hot off — bench showed no win
    Charge-pump keep-hot (0xCC) was tested on device 2026-07-21. Windowed-fast
    held flat at ~240 ms and the first partial after a power-down full refresh was
    no slower than mid-burst partials, so there is no ramp penalty to skip — the
    ~240 ms is waveform BUSY. Screen stayed clean, so the trigger is safe, but with
    zero latency win the pump-stays-hot cost isn't worth paying. Toggle left wired
    (FAST_PART_KEEP_HOT = false) for a future A/B.
    [screen_epd.rs]
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2026-07-22 feat(case): re-model enclosure for the two-PCB build
    PCB 1 (ESP32 + e-ink driver + MT3608 boost) mounts back-left on low
    standoffs; PCB 2 (uSD + 2x USB-C + TP4056) runs along the back wall,
    back-right, its connectors exiting the back wall from the measured
    8/7/5 mm gaps. LiPo 3700 lies flat across the front (CG low + forward).
    Ports/holes/reset are set to the real hardware; drops the old single
    devkit + DESPI-breakout model.
    [typoena-case.scad]
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
